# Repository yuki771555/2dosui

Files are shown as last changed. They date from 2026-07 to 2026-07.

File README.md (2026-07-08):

# 2dosumi

Raspberry Pi + HX711 + load cells project for detecting return-to-bed events.

## Local mock run

```powershell
python -m twodosumi run --config config/mock.fast.json --max-samples 25
```

## Web UI and webhook notifications

Install dependencies on the Raspberry Pi, then start the Web UI:

```bash
python3 -m pip install -r requirements-pi.txt
python3 -m twodosumi web --config config/pi.aggregate.json --secrets config/secrets.json --host 127.0.0.1 --port 8080
```

On first launch, `config/secrets.json` is created with a `web_ui_token`.
Open the UI through Tailscale Serve:

```bash
tailscale serve --bg 8080
```

The Web UI can edit thresholds and timing settings, start/stop detection, check sensor reads, run zero and scale calibration, and test webhook delivery. Use a Discord webhook URL with `webhook_payload_format=discord`, or set the format to `json` for a generic webhook endpoint.

The second-sleep alarm can be turned on or off from the Web UI. When `alarm_enabled` is on, `second_sleep_detected` sends a Discord webhook using `config/secrets.json` and pulses the Raspberry Pi buzzer. The default buzzer pin is `board.D13`; use an active buzzer or a suitable transistor/driver circuit for your buzzer module.

To start the Web UI automatically when the Pi boots:

```bash
chmod +x scripts/install_twodosumi_web_service.sh
./scripts/install_twodosumi_web_service.sh
tailscale serve --bg 8080
```

The installer defaults to `APP_DIR=/home/pi/2dosumi`, `APP_USER=pi`, and port `8080`. Override them if needed:

```bash
APP_DIR=/home/pi/2dosumi APP_USER=pi PORT=8080 ./scripts/install_twodosumi_web_service.sh
```

Useful checks:

```bash
systemctl status twodosumi-web.service --no-pager
journalctl -u twodosumi-web.service -f
tailscale serve status
```

## Raspberry Pi setup

For the full deployment flow, including copying files to the Pi, first sensor verification, calibration, and systemd setup, see [docs/raspberry_pi_deploy.md](docs/raspberry_pi_deploy.md).

```bash
python3 -m pip install -r requirements-pi.txt
python3 -m twodosumi check-sensor --config config/pi.aggregate.json --samples 10
python3 -m twodosumi calibrate-zero --config config/pi.aggregate.json
python3 -m twodosumi calibrate-scale --config config/pi.aggregate.json --known-kg 8
python3 -m twodosumi run --config config/pi.aggregate.json --secrets config/secrets.json
```

The current Pi config uses HX711 DATA on `board.D6` and SCK on `board.D5`.

## Android native app

The native Android client lives in `android/`. It uses Kotlin + Jetpack Compose
and talks to the existing Raspberry Pi Flask API; the sensor and detector still
run on the Pi.

Open `android/` in Android Studio, sync Gradle, then run the `app`
configuration. On first launch, enter the Pi Web UI URL, for example
`http://raspberrypi.local:8080` or your Tailscale Serve URL, and the
`web_ui_token` from `config/secrets.json`.

If you have a local JDK and Gradle installed, you can also build from the
project root:

```powershell
cd android
.\gradlew.bat :app:assembleDebug
```

The app mirrors the Web UI:

- status polling every 3 seconds, start/stop controls, weight sparkline, and event timeline
- quick alarm toggles and scheduled alarm editing
- sensor check, zero calibration, and scale calibration
- full settings editing and webhook test

## 4 load cell wiring

This project assumes four half-bridge load cells combined into one HX711 channel.
The program reads one aggregate weight value, not four independent corner values.

| HX711 terminal | Connect to |
| --- | --- |
| `E+` | `LC1 + LC2` |
| `E-` | `LC3 + LC4` |
| `A+` | `LC1 + LC3` |
| `A-` | `LC2 + LC4` |

HX711 to Raspberry Pi:

| HX711 | Raspberry Pi 4 |
| --- | --- |
| `VCC` | Pin 1 `3.3V` |
| `GND` | Pin 6 `GND` |
| `DT` / `DOUT` | Pin 31 `GPIO6` (`board.D6`) |
| `SCK` / `CLK` | Pin 29 `GPIO5` (`board.D5`) |

Use 3.3V for HX711 VCC first. Do not feed a 5V signal into Raspberry Pi GPIO.

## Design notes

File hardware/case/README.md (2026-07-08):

# ベッド下スケールプレート(3Dプリントケース)

Raspberry Pi 4 + HX711 + 50kg半橋ロードセル×4 を内蔵する体重計型プレート。
ベッドの脚1本の下に敷き、脚にかかる荷重の変化でベッド復帰を検知する。

設計ソースは [bed_scale_plate.scad](bed_scale_plate.scad)(OpenSCAD、全寸法パラメトリック)。
STLは `stl/`、プレビュー画像は `img/` にある。

## 仕組み(荷重経路)

```
ベッドの脚
  → 脚受けリング付きの上蓋(top_plate + leg_ring)
  → 裏面のボス×4 → ロードセルのボタン×4
  → ペデスタル → 下皿(base_plate) → 床
```

上蓋はロードセルのボタン4点**だけ**に接触して浮いている。外周スカートは
横ズレ・ホコリ防止用で、下皿の壁とは上下方向に2mmの隙間があり荷重を邪魔しない。
Pi・HX711は下皿に固定され、上蓋裏面とは2.6mm以上のクリアランスがある。

## パーツと印刷

| STL | 個数 | サイズ | 備考 |
| --- | --- | --- | --- |
| `stl/base_plate.stl` | 1 | 168×168×25mm | 下皿。そのままの向きで印刷 |
| `stl/top_plate.stl` | 1 | 175.8×175.8×14mm | 上蓋。天面を下にした印刷向きでエクスポート済み |
| `stl/leg_ring.stl` | 1 | φ110×8mm | 脚受けリング(φ80までの脚に対応) |
| `stl/leg_spacer.stl` | 3 | φ110×36mm | 残り3本の脚用スペーサー(本体と同じ高さ34mm+皿2mm) |

- **Bambu A1 mini(180×180mm)で全パーツ印刷可**(最大175.8mm角)
- 材料: **PETG推奨**(PLA+でも可)。常時荷重がかかるため
- 壁 4〜6周、インフィル **40%以上**(ペデスタル部が潰れないように)
- サポート不要(全パーツその向きのまま)

## 必要部品

- 50kg 半橋ロードセル ×4(体重計タイプ、34×34mm)
- HX711 モジュール ×1
- Raspberry Pi 4 ×1
- M2.5×6mm タッピングネジ ×4(Pi固定)
- 結束バンド ×1(HX711固定)
- 瞬間接着剤 少量(脚受けリングのピン固定)

## 組立手順

1. 下皿の四隅ポケットにロードセルを置く(ボタン面を上、配線は中央向きのスロットから出す)
2. ロードセル4本の配線をHX711へ。結線はルート [README.md](../../README.md) の
   「4 load cell wiring」の表の通り(E+/E-/A+/A- の合成、HX711→Pi は GPIO5/6)
3. HX711 を中央のベイにはめ、床の貫通スロットに結束バンドを通して固定
4. Pi 4 をスタンドオフに M2.5 ネジで固定(縦置き: USB-C/HDMI辺が左壁、USB/Ethernetが奥向き)。
   USB-C 電源ケーブルは左側面スリットから外へ
5. 上蓋をかぶせる(スカートが下皿の壁の外側に重なる)
6. 脚受けリングのピン3本に接着剤を付け、上蓋天面の穴に差し込む
7. ベッドの脚1本をリングの内側に載せ、残り3本の脚にスペーサーを敷く
8. `python3 -m twodosumi calibrate-zero` → `calibrate-scale` で校正(ルートREADME参照)

## 寸法をいじりたいとき

`.scad` 先頭のパラメータを変更して再エクスポート:

- `base_outer` — プレート外形(現在168mm=A1 mini対応。大きいプリンタなら192等に拡大可)
- `ring_id` — 脚がφ80を超える場合に拡大(`ring_od`・`spacer_d` も合わせて)
- `top_underside` — Pi上空クリアランス(ヒートシンク搭載時は+数mm)
- `cell_w` / `cell_h` — ロードセルの実寸が違う場合

```powershell
$scad = "C:\Program Files\OpenSCAD\openscad.com"
& $scad -o stl\base_plate.stl -D 'part="base"'   bed_scale_plate.scad
& $scad -o stl\top_plate.stl  -D 'part="top"'    bed_scale_plate.scad
& $scad -o stl\leg_ring.stl   -D 'part="ring"'   bed_scale_plate.scad
& $scad -o stl\leg_spacer.stl -D 'part="spacer"' bed_scale_plate.scad
```

組立確認は `part="assembly"`、断面確認は `part="section"` をOpenSCADのGUIで表示。

## 注意

- 本体の全高は34mm。**必ず残り3本の脚にもスペーサー(または同厚の板)を敷いて**
  ベッドを水平に保つこと
- 定格は 50kg×4=200kg(半橋合成)。通常のシングルベッド+成人1人で問題ないが、
  片脚への集中荷重が大きい重いベッドでは脚の位置をリング中央に正しく合わせること
- 印刷品はクリープ(常時荷重での変形)があるため、検知値が徐々にドリフトしたら
  Web UI からゼロ校正をやり直す

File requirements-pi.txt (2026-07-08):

adafruit-blinka
adafruit-circuitpython-hx711
Flask

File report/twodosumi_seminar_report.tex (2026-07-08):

\documentclass[paper=a4,fontsize=10pt,ja=standard,lualatex]{jlreq}

\usepackage{luatexja}
\usepackage{luatexja-fontspec}
\usepackage[top=18mm,bottom=18mm,left=18mm,right=18mm]{geometry}
\usepackage{graphicx}
\usepackage{xcolor}
\usepackage{booktabs}
\usepackage{array}
\usepackage{longtable}
\usepackage{tabularx}
\usepackage{tikz}
\usepackage[american]{circuitikz}
\usepackage{pgfplots}
\usepackage{enumitem}
\usepackage{fancyhdr}
\usepackage[hidelinks]{hyperref}
\usepackage{lastpage}
\usetikzlibrary{arrows.meta,positioning,shapes.geometric,fit,calc}
\pgfplotsset{compat=1.18}

\definecolor{mainblue}{HTML}{1F5C99}
\definecolor{accentorange}{HTML}{E67E22}
\definecolor{softblue}{HTML}{EAF3FB}
\definecolor{softgray}{HTML}{F4F6F8}
\definecolor{darkgray}{HTML}{36454F}
\definecolor{deepgreen}{HTML}{2E7D32}
\definecolor{softgreen}{HTML}{E9F6EC}

\setmainjfont{Yu Mincho}
\setsansjfont{Yu Gothic}
\setmainfont{Latin Modern Roman}
\setsansfont{Latin Modern Sans}

\hypersetup{
  pdftitle={荷重センシングによる二度寝防止システムの開発},
  pdfauthor={○班},
  pdfsubject={電気電子工学導入ゼミナール自由研究}
}

\pagestyle{fancy}
\setlength{\headheight}{14pt}
\fancyhf{}
\lhead{\small 荷重センシングによる二度寝防止システムの開発}
\rhead{\small 電気電子工学導入ゼミナール自由研究}
\cfoot{\small \thepage}
\renewcommand{\headrulewidth}{0.3pt}

\setlength{\intextsep}{9pt plus 2pt minus 3pt}
\setlist[itemize]{leftmargin=2.0em,itemsep=0.2em,topsep=0.3em}
\setlist[enumerate]{leftmargin=2.0em,itemsep=0.2em,topsep=0.3em}
\renewcommand{\arraystretch}{1.18}

\newcommand{\ResearchTitle}{荷重センシングによる二度寝防止システムの開発}
\newcommand{\GroupNumber}{○班}
\newcommand{\StudentA}{20XXXXXX　氏名A}
\newcommand{\StudentB}{20XXXXXX　氏名B}
\newcommand{\StudentC}{20XXXXXX　氏名C}
\newcommand{\StudentD}{20XXXXXX　氏名D}
\newcommand{\SubmitDate}{2026年7月23日}
\newcommand{\AuthorNote}[1]{\hfill{\small （担当：#1）}}

\newcolumntype{Y}{>{\raggedright\arraybackslash}X}
\newcolumntype{C}[1]{>{\centering\arraybackslash}p{#1}}

\begin{document}

\thispagestyle{empty}
\begin{center}
  \vspace*{6mm}
  {\Large 電気電子工学導入ゼミナール自由研究}\\[12mm]
  {\LARGE\bfseries \ResearchTitle}\\[8mm]
  {\large \GroupNumber}\\[10mm]
\end{center}

\begin{table}[h]
\centering
\begin{tabular}{ll}
\toprule
提出日 & \SubmitDate\\
班番号 & \GroupNumber\\
\bottomrule
\end{tabular}
\end{table}

\vspace{4mm}
\begin{center}
\begin{tabular}{ll}
\toprule
学籍番号 & 氏名\\
\midrule
\StudentA\\
\StudentB\\
\StudentC\\
\StudentD\\
\bottomrule
\end{tabular}
\end{center}

\vspace{8mm}
{\large\bfseries 目次}
\begin{center}
\begin{tabularx}{0.96\linewidth}{C{9mm}Y C{28mm} C{12mm}}
\toprule
番号 & 項目 & 担当者 & ページ\\
\midrule
1 & 研究背景と目的 & 氏名A & \pageref{sec:background}\\
2 & 提案システムの概要 & 氏名B & \pageref{sec:overview}\\
3 & ハードウェア・回路・ソフトウェア構成 & 氏名B & \pageref{sec:hardware}\\
4 & 二度寝判定アルゴリズム & 氏名C & \pageref{sec:algorithm}\\
5 & 実装内容 & 氏名C & \pageref{sec:implementation}\\
6 & 模擬試験・実機確認と結果 & 氏名D & \pageref{sec:results}\\
7 & 考察 & 氏名D & \pageref{sec:discussion}\\
8 & まとめと今後の課題 & 全員 & \pageref{sec:conclusion}\\
\bottomrule
\end{tabularx}
\end{center}

\vfill
\noindent
本稿では、Raspberry Pi とロードセルを用いてベッド上の荷重変化を読み取り、起床後に再びベッドへ戻る行動を検出する二度寝防止システム「2dosumi」の開発について報告する。本研究では、二度寝を「離床後の再在床」という観測可能な状態遷移として定義し、荷重値のしきい値、監視時間、再在床の継続時間を組み合わせて判定する方式を採用した。模擬センサによる状態遷移の確認に加え、実機ではテスターによる電圧測定にもとづく不具合の切り分け、既知重量を用いたゼロ点・スケール校正、荷重変化の読み取りまでを確認した。

\vspace{2mm}
\noindent
{\small\color{darkgray} ※提出前に、班番号・学籍番号・氏名・担当者名を実情報に置き換えること。}

\clearpage

\section{研究背景と目的}
\label{sec:background}
\AuthorNote{氏名A}

朝の起床直後は、目覚ましを止めたあとに再び寝床へ戻る「二度寝」が起こりやすい。スマートフォンのアラームは音や振動によって覚醒を促すが、ユーザが一度アラームを止めてしまうと、その後に本当に起き続けているかを確認できない。そこで本研究では、寝床に戻ったという行動そのものを検出し、二度寝の直前または直後に再通知できるシステムを目標とした。

本研究の着眼点は、映像やマイクではなく荷重センサを用いることである。ベッドの脚やマットレス下にロードセルを設置すれば、利用者の在床・離床を、比較的プライバシーを保ったまま観測できる。画像認識に比べて得られる情報は少ないが、起床支援という目的に対しては「ベッド上にいるか」「離床後に戻ったか」という低次元の情報で十分である。既存の起床支援方法と本研究の位置づけを表\ref{tab:related}に整理する。

\begin{table}[h]
\centering
\caption{既存の起床支援方法と本研究の位置づけ}
\label{tab:related}
\begin{tabularx}{0.95\linewidth}{lYYY}
\toprule
方式 & 長所 & 弱点 & 本研究との関係\\
\midrule
スマートフォンアラーム & 導入が容易 & 停止後の行動を見ない & 基本通知として併用可能\\
カメラ監視 & 行動を細かく把握可能 & プライバシー負担が大きい & 本研究では採用しない\\
ウェアラブル & 身体状態を測定可能 & 装着忘れがある & 非装着型を目指す\\
荷重センシング & 在床変化を直接検出 & 設置・校正が必要 & 本研究の中心\\
\bottomrule
\end{tabularx}
\end{table}

研究目的は次の三点である。第一に、ロードセルから得られる荷重値をもとに在床状態を推定すること。第二に、離床後に一定時間以内で再び在床した場合を「二度寝リスク」として判定すること。第三に、判定結果を Web 画面や通知機構へつなげ、実用的な起床支援システムとして扱える形にすることである。

\section{提案システムの概要}
\label{sec:overview}
\AuthorNote{氏名B}

提案システムは、ベッド下の荷重センサ、Raspberry Pi 上の判定プログラム、利用者が状態を確認する Web インタフェースおよび Android ネイティブアプリから構成される。センサは寝床の荷重を周期的に読み取り、プログラムはその値をしきい値と時間条件で解釈する。二度寝が疑われる状態になると、Android アプリがスマートフォン側でアラーム音と通知を出し、必要に応じて Webhook や Raspberry Pi 側ブザーも補助通知として利用できる。システムの全体構成を図\ref{fig:system}に示す。

\begin{figure}[h]
\centering
\resizebox{0.94\linewidth}{!}{%
\begin{tikzpicture}[
  font=\small,
  block/.style={draw=mainblue!70,line width=0.8pt,rounded corners=2pt,fill=softblue,minimum width=32mm,minimum height=11mm,align=center},
  smallblock/.style={draw=darkgray!45,line width=0.6pt,rounded corners=2pt,fill=softgray,minimum width=30mm,minimum height=10mm,align=center},
  arrow/.style={-{Latex[length=2.4mm]},thick,darkgray},
  lbl/.style={font=\scriptsize,darkgray,fill=white,inner sep=1.5pt}
]
\node[block] (bed) {ベッド\\ロードセル};
\node[smallblock,right=15mm of bed] (hx) {HX711\\増幅・A/D変換};
\node[block,right=15mm of hx] (pi) {Raspberry Pi\\判定・API};
\node[smallblock,above right=7mm and 17mm of pi] (web) {Web UI\\状態確認・設定};
\node[smallblock,right=17mm of pi] (android) {Androidアプリ\\操作・鳴動};
\node[smallblock,below right=7mm and 17mm of pi] (log) {CSVログ\\事後検証};
\node[block,right=10mm of android] (notify) {スマホアラーム\\通知};
\draw[arrow] (bed) -- node[lbl,above]{微小電圧} (hx);
\draw[arrow] (hx) -- node[lbl,above]{デジタル値} (pi);
\draw[arrow] (pi) -- (web);
\draw[arrow] (pi) -- node[lbl,above]{HTTP API} (android);
\draw[arrow] (pi) -- (log);
\draw[arrow] (android) -- (notify);
\end{tikzpicture}
}
\caption{提案システムの全体構成}
\label{fig:system}
\end{figure}

本システムが扱う状態は、主に「在床」「離床後監視」「再在床」「二度寝検出」であり、監視時間内に戻らなければ「起床成功」となる。重要なのは、単にベッドにいるかどうかではなく、起床予定時刻付近で一度離床した後に戻るという時間的な流れを扱う点である。このため、瞬間的なしきい値判定だけではなく、離床から再在床までの経過時間も判定に用いる。

Android ネイティブアプリは、Raspberry Pi 側の HTTP API に接続する日常利用の窓口として位置づけた。Web ブラウザでも状態確認は可能だが、利用者が自分から開く必要があるため、二度寝しかけている利用者へ情報を届ける手段としては受動的である。ネイティブアプリであれば Foreground Service と通知を用いて画面消灯中も状態を監視し、スマートフォン本体からアラーム音を鳴らせる。

起床直後には、枕元の端末から現在状態、重量値、次回アラーム、再確認状態を少ない操作で確認できる。さらに、音量、通知の有無、アラーム設定、二度寝確定までの秒数、再確認間隔、ゼロ点校正、既知重量によるスケール校正、センサ確認などを同じ画面から変更できる。このようにアプリは将来の拡張ではなく、通知を受け取り設定を調整するというシステムの利用体験そのものを担う要素である。

実装済みのプログラムでは、設定ファイルからセンサ種別、しきい値、通知方法、Web サーバ設定などを読み込める。これにより、実機ロードセルがない環境でも模擬センサを用いて判定ロジックを検証できる。また、設定値を変更することで、ベッドや利用者の体重差に応じた調整を行える設計とした。

\section{ハードウェア・回路・ソフトウェア構成}
\label{sec:hardware}
\AuthorNote{氏名B}

ハードウェア面では、Raspberry Pi、HX711、ロードセル、スマートフォンアプリによる通知を中心に構成する。ロードセルは微小なひずみを電気信号へ変換するセンサであり、HX711 はロードセル用の高分解能 A/D 変換器として広く使われている。Raspberry Pi は HX711 から得られる値を読み取り、Python プログラムで状態判定を行う。主要な構成要素を表\ref{tab:components}にまとめる。

\begin{table}[h]
\centering
\caption{主要構成要素}
\label{tab:components}
\begin{tabularx}{0.95\linewidth}{lYY}
\toprule
分類 & 要素 & 役割\\
\midrule
センサ & ロードセル & ベッド上の荷重変化を測定する\\
変換回路 & HX711 & ロードセル信号を Raspberry Pi で扱える値に変換する\\
処理部 & Raspberry Pi & 状態判定、通知、Web UI 提供を行う\\
通知部 & Android アプリ、通知、スマホ音 & 二度寝検出時に利用者へ知らせる\\
表示部 & Web ブラウザ & 現在状態、履歴、設定値を確認する\\
モバイル部 & Android ネイティブアプリ & 状態確認、設定、校正、アラーム鳴動を行う\\
\bottomrule
\end{tabularx}
\end{table}

回路面で当初想定した標準構成は、4個のロードセルを組み合わせたホイートストンブリッジである（図\ref{fig:bridge}）。ロードセル内部のひずみゲージは、荷重を受けると抵抗値がわずかに変化する。しかし、その変化は非常に小さく、Raspberry Pi の GPIO へ直接入力しても読み取れない。そこで、4個のロードセルをブリッジの4辺として構成し、左右の中点間に現れる差動電圧を HX711 で増幅・A/D 変換する。ブリッジ構成には、抵抗変化を差動電圧として取り出すことで感度を高められるうえ、温度変化のように4個の抵抗へ同じ向きに現れる変動を打ち消せるという利点がある。

\begin{figure}[h]
\centering
\resizebox{0.82\linewidth}{!}{%
\begin{circuitikz}[
  american resistors,
  circuitikz/bipoles/length=12mm,
  every node/.style={font=\small},
  wire/.style={thick},
  sig/.style={{Latex[length=2.0mm]}-{Latex[length=2.0mm]},dashed,thick,mainblue},
  data/.style={-{Latex[length=2.0mm]},thick},
  port/.style={font=\scriptsize,inner sep=1pt}
]
\coordinate (ep) at (0,2.6);
\coordinate (em) at (0,-2.6);
\coordinate (ap) at (-3.1,0);
\coordinate (am) at (3.1,0);
\draw[wire] (ep) to[R,l_={LC1}] (ap)
            to[R,l_={LC3}] (em)
            to[R,l_={LC4}] (am)
            to[R,l_={LC2}] (ep);
\fill (ep) circle (1.4pt);
\fill (em) circle (1.4pt);
\fill (ap) circle (1.4pt);
\fill (am) circle (1.4pt);
\node[above left=1mm and -2mm of ep] {E+（励起+）};
\node[left=3mm of em] {E-（励起-）};
\node[left=2mm of ap] {A+};
\node[below=2mm of am] {A-};
\draw[sig] ($(ap)+(0.45,0)$) -- node[above,fill=white,inner sep=1.5pt]{差動電圧} ($(am)+(-0.45,0)$);
\node[draw,rounded corners,fill=softblue,minimum width=30mm,minimum height=30mm,align=center] (hx) at (6.7,0) {HX711\\増幅（PGA）\\A/D変換};
% 励起（E+ / E-）：HX711基板からブリッジへ電源を供給
\draw[wire] (ep) -- node[above,font=\scriptsize]{励起電圧の供給} (5.0,2.6) -- (5.0,1.15) -- (hx.west |- 0,1.15);
\draw[wire] (em) -- (0,-3.3) -- (4.6,-3.3) -- (4.6,-0.45) -- (hx.west |- 0,-0.45);
% 差動入力（A+ / A-）：ブリッジ中点の電圧をHX711へ入力
\draw[wire] (am) -- (4.6,0) -- (4.6,0.45) -- (hx.west |- 0,0.45);
\draw[wire] (ap) -- (-3.1,-3.9) -- (5.0,-3.9) -- (5.0,-1.15) -- (hx.west |- 0,-1.15);
\node[port,anchor=west] at ($(hx.west)+(0.06,1.15)$) {E+};
\node[port,anchor=west] at ($(hx.west)+(0.06,0.45)$) {A-};
\node[port,anchor=west] at ($(hx.west)+(0.06,-0.45)$) {E-};
\node[port,anchor=west] at ($(hx.west)+(0.06,-1.15)$) {A+};
\node[draw,rounded corners,fill=softgray,minimum width=30mm,minimum height=17mm,align=center,right=13mm of hx] (pi) {Raspberry Pi\\GPIO};
\draw[data] (hx.east |- 0,0.4) -- node[above]{DOUT} (pi.west |- 0,0.4);
\draw[data] (pi.west |- 0,-0.4) -- node[below]{SCK} (hx.east |- 0,-0.4);
\end{circuitikz}%
}
\caption{4個のロードセル（LC1〜LC4）で構成したホイートストンブリッジと HX711・Raspberry Pi の接続}
\label{fig:bridge}
\end{figure}

実機検証では当初4個構成で組み、初期の読み取り不良は HX711 読み取り処理の実装ミスを修正することで解消し、4個構成でもサンプル取得できることを確認した。その後、別日にロードセル1個のセンサ線を断線してしまったため、最終的な実機検証では故障したロードセルを外し、2個の半橋ロードセルで1つのブリッジを構成する方式へ変更した。これは初期の読み取り不良とは別の事象であり、測定方式を単に簡略化したのではなく、実験を継続するための故障対応である。本研究の目的は体重を高精度に量ることではなく、在床、離床、再在床の大きな荷重変化を判定することであるため、2個構成でも判定ロジックの検証には十分であると判断した。実機検証で用いた2個ロードセル版の接続を図\ref{fig:two-cell-bridge}と表\ref{tab:two-cell-wiring}に示す。

\begin{figure}[h]
\centering
\resizebox{0.86\linewidth}{!}{%
\begin{circuitikz}[
  american resistors,
  circuitikz/bipoles/length=12mm,
  every node/.style={font=\small},
  wire/.style={thick},
  sig/.style={{Latex[length=2.0mm]}-{Latex[length=2.0mm]},dashed,thick,mainblue},
  data/.style={-{Latex[length=2.0mm]},thick},
  port/.style={font=\scriptsize,inner sep=1pt}
]
\coordinate (lTop) at (-2.4,2.4);
\coordinate (lMid) at (-2.4,0);
\coordinate (lBot) at (-2.4,-2.4);
\coordinate (rTop) at (2.4,2.4);
\coordinate (rMid) at (2.4,0);
\coordinate (rBot) at (2.4,-2.4);
\draw[wire] (lTop) to[R,l={LC1上側}] (lMid)
            to[R,l={LC1下側}] (lBot);
\draw[wire] (rTop) to[R,l_={LC2上側}] (rMid)
            to[R,l_={LC2下側}] (rBot);
\draw[wire] (lTop) -- node[above,font=\scriptsize]{E+ 共通} (rTop);
\draw[wire] (lBot) -- node[below,font=\scriptsize]{E- 共通} (rBot);
\fill (lTop) circle (1.4pt);
\fill (lMid) circle (1.4pt);
\fill (lBot) circle (1.4pt);
\fill (rTop) circle (1.4pt);
\fill (rMid) circle (1.4pt);
\fill (rBot) circle (1.4pt);
\node[left=2mm of lMid] {A+};
\node[right=2mm of rMid] {A-};
\draw[sig] ($(lMid)+(0.35,0)$) -- node[above,fill=white,inner sep=1.5pt]{差動電圧} ($(rMid)+(-0.35,0)$);
\node[draw,rounded corners,fill=softblue,minimum width=30mm,minimum height=30mm,align=center] (hx) at (6.5,0) {HX711\\Aチャネル\\増幅・A/D};
\draw[wire] (rTop) -- (4.7,2.4) -- (4.7,1.15) -- (hx.west |- 0,1.15);
\draw[wire] (rBot) -- (4.3,-2.4) -- (4.3,-0.45) -- (hx.west |- 0,-0.45);
\draw[wire] (rMid) -- (4.3,0) -- (4.3,0.45) -- (hx.west |- 0,0.45);
\draw[wire] (lMid) -- (-1.0,0) -- (-1.0,-3.1) -- (4.7,-3.1) -- (4.7,-1.15) -- (hx.west |- 0,-1.15);
\node[port,anchor=west] at ($(hx.west)+(0.06,1.15)$) {E+};
\node[port,anchor=west] at ($(hx.west)+(0.06,0.45)$) {A-};
\node[port,anchor=west] at ($(hx.west)+(0.06,-0.45)$) {E-};
\node[port,anchor=west] at ($(hx.west)+(0.06,-1.15)$) {A+};
\node[draw,rounded corners,fill=softgray,minimum width=30mm,minimum height=17mm,align=center,right=13mm of hx] (pi) {Raspberry Pi\\GPIO};
\draw[data] (hx.east |- 0,0.4) -- node[above]{DOUT} (pi.west |- 0,0.4);
\draw[data] (pi.west |- 0,-0.4) -- node[below]{SCK} (hx.east |- 0,-0.4);
\end{circuitikz}%
}
\caption{実機検証で用いた2個の半橋ロードセルによるブリッジ構成}
\label{fig:two-cell-bridge}
\end{figure}

\begin{table}[h]
\centering
\caption{2個ロードセル構成での端子接続}
\label{tab:two-cell-wiring}
\begin{tabularx}{0.95\linewidth}{lY}
\toprule
端子 & 接続先\\
\midrule
E+ & 2個のロードセルの上側外端を共通接続\\
E- & 2個のロードセルの下側外端を共通接続\\
A+ & 1個目ロードセルの中点\\
A- & 2個目ロードセルの中点\\
VCC & Raspberry Pi の 3.3 V\\
GND & Raspberry Pi の GND\\
DT / DOUT & Raspberry Pi の GPIO6（D6）\\
SCK / CLK & Raspberry Pi の GPIO5（D5）\\
\bottomrule
\end{tabularx}
\end{table}

2個のロードセルは向きや荷重のかかり方により、A+ と A- の符号が期待と逆になる場合がある。その場合でも故障とは限らず、既知重量を用いた校正でスケール係数の符号が決まり、ソフトウェア上では kg 相当値として扱える。本研究の実機でも、既知重量による校正後に荷重を kg 相当値として読み取れることを確認した（第\ref{sec:results}節）。

HX711 基板では、ロードセル側の端子は一般に E+、E-、A+、A- と表記される。E+ と E- は HX711 基板側からブリッジへ電圧を供給する励起端子であり、A+ と A- はブリッジの左右の中点から差動電圧を受け取る入力端子である。荷重がないときは左右の分圧がほぼ等しく、A+ と A- の電位差はほぼ 0 V になる。荷重がかかると一部のゲージが伸び、別のゲージが縮むため、片側の抵抗はわずかに増え、反対側はわずかに減る。励起電圧を $V_E$、無荷重時の各辺の抵抗を $R$、荷重による変化分を $\Delta R$ とし、対角の2辺が $+\Delta R$、残りの2辺が $-\Delta R$ と逆向きに変化する理想的な場合を考えると、左右の分圧の差として現れる出力電圧は
\[
  V_{\mathrm{A+}} - V_{\mathrm{A-}} = \frac{\Delta R}{R}\, V_E
\]
となり、抵抗の変化率に比例した電圧が得られる。実際の $\Delta R / R$ はごく小さく、この差動電圧は数 mV 程度と微小であるため、HX711 は内部のプログラマブルゲインアンプ（チャネル A では 128 倍）で増幅したうえで、24 ビットの A/D 変換器によりデジタル値へ変換し、DOUT・SCK の2線シリアルで Raspberry Pi へ送る（表\ref{tab:hx711}）。

\begin{table}[h]
\centering
\caption{HX711 と Raspberry Pi の接続例}
\label{tab:hx711}
\begin{tabularx}{0.95\linewidth}{lYY}
\toprule
端子 & 接続先 & 役割\\
\midrule
E+ / E- & ロードセルブリッジの電源端 & ブリッジ回路へ励起電圧を与える\\
A+ / A- & ブリッジの左右中点 & 荷重で変化する差動電圧を入力する\\
VCC / GND & Raspberry Pi の 3.3 V / GND & HX711 基板へ電源を供給する\\
DT / DOUT & Raspberry Pi の GPIO6（D6） & 変換完了とデータ出力を受け取る\\
SCK / CLK & Raspberry Pi の GPIO5（D5） & クロックを送り、データ読み出しとゲイン設定を行う\\
\bottomrule
\end{tabularx}
\end{table}

Raspberry Pi で使う場合は、GPIO が 3.3 V 入力である点に注意する。HX711 モジュールには 5 V 動作品も多く、DT 端子の High レベルが 5 V のままでは GPIO を傷めるおそれがあるため、本研究では HX711 を 3.3 V で駆動した。また、センサ配線は微小電圧を扱うため、長い配線や電源ノイズ、断線の影響を受けやすい。実機では、ロードセルの固定と荷重分散に注意し、ゼロ点補正と既知重量による校正で読み取り値を kg 相当へ変換する。

ソフトウェアは Raspberry Pi 側の Python プログラムと、スマートフォン側の Android ネイティブアプリに分けて構成した。Raspberry Pi 側では、センサ入力、判定器、通知、Web サーバを分離し、それぞれの責務を小さくした。これにより、実機センサから模擬センサへ切り替えても、判定器や表示側のコードを大きく変えずに試験できる。

Android アプリは Kotlin と Jetpack Compose により実装し、Retrofit/OkHttp を用いて、Raspberry Pi が公開する状態 API、設定 API、校正 API を呼び出す。センサ値を直接読まずに API 経由とすることで、ロードセルや HX711 に近い低レベル処理は Raspberry Pi に集約し、スマートフォン側は操作性と表示に集中できる。

\subsection{筐体（3Dプリントケース）の設計}

当初設計では、ロードセル4個、HX711、Raspberry Pi を一体化した体重計型の筐体を OpenSCAD で設計し、3Dプリンタ（Bambu A1 mini、造形範囲 $180\times180$ mm）で製作する構成を想定した。筐体はベッドの脚1本の下に敷き、その脚にかかる荷重の変化から在床・離床を読み取る。構成は、ロードセル・HX711・Raspberry Pi を収める下皿（168 mm 角）、その上に浮かべる上蓋（175.8 mm 角）、脚を受けるリング、および残り3本の脚の高さを揃えるスペーサー3個であり、全高は 34 mm である。設計の要点は荷重経路にある。脚の荷重は上蓋から裏面の4個のボスを介してロードセル中央の受圧ボタンのみに伝わり、下皿の支持台（ペデスタル）を経て床へ抜ける。上蓋は電子部品のどこにも接触せず（Raspberry Pi 最上部との隙間 2.6 mm）、外周のスカートは横ズレとほこりの侵入を防ぐだけで荷重を負担しない。これは市販の体重計と同じ構造であり、4個構成では各ロードセルに荷重が分配される。設計した筐体の組立状態と断面を図\ref{fig:case}に示す。

\begin{figure}[h]
\centering
\begin{minipage}[t]{0.48\linewidth}
  \centering
  
\end{minipage}\hfill
\begin{minipage}[t]{0.48\linewidth}
  \centering
  
\end{minipage}
\caption{設計した筐体の組立ビュー（左）とロードセル中心線での断面（右）。断面では上蓋がロードセルの受圧ボタン4点のみに接触し、中央の Raspberry Pi（緑・灰）と隙間を保っていることが分かる}
\label{fig:case}
\end{figure}

当初設計の耐久性は、荷重をほぼすべて「圧縮」で受ける構造とすることで確保した。3Dプリント品は曲げや積層はく離に弱い一方、押し潰す方向には強いためである。ロードセルの定格は4個構成で $50\,\mathrm{kg}\times4=200\,\mathrm{kg}$ であり、就寝時にこの脚へかかる荷重（数十 kg）に対して十分な余裕がある。曲げを受ける唯一の部品は上蓋であり、板厚 7 mm に加えて裏面に深さ 5 mm のリブを配置し、Raspberry Pi の直上のみリブを省いてクリアランスを確保した。また、樹脂は常時荷重でわずかに変形が進む（クリープ）ため、長期間の使用ではゼロ点が徐々にずれ得るが、これは Web UI からのゼロ点校正で補正できる。製作時の主な印刷条件を表\ref{tab:print}に示す。曲げ剛性が必要な上蓋のみ壁数と充填密度を高め、圧縮しか受けない部品は標準設定として印刷時間を抑えた。

\begin{table}[h]
\centering
\caption{3Dプリントの主な条件（材料は PETG、積層ピッチ 0.2 mm、サポート材なし）}
\label{tab:print}
\begin{tabularx}{0.95\linewidth}{lllY}
\toprule
部品 & 壁面層数 & 充填密度 & 補足\\
\midrule
上蓋 & 4 & 25\% & トップ面・底面各5層。唯一曲げを受けるため強化する\\
下皿 & 3 & 15\% & 床に全面接地するため曲げがかからない\\
スペーサー（3個） & 2 & 10〜15\% & 圧縮のみ。本体と同高にしてベッドを水平に保つ\\
脚受けリング & 2 & 15\% & 脚の横ズレ防止用\\
\bottomrule
\end{tabularx}
\end{table}

当初設計の組立では、ロードセルは下皿四隅のポケットにはめ込むだけで位置が決まり、上蓋のボスが上から押さえる。HX711 は中央のベイに収め、床の貫通スロットに通した結束バンドで固定する。Raspberry Pi は下皿のスタンドオフ4本（Pi 4 の取付穴ピッチ $58\times49$ mm に対応、下穴 $\phi2.2$ mm）に M2.5$\times$6 mm の小ネジをセルフタップでねじ込んで固定し、USB-C 電源ケーブルは側壁のスリットから外へ引き出す。設置面が沈むと支持台が傾き測定が不安定になるため、カーペット上への直置きは避け、フローリングか板の上に設置する。

\section{二度寝判定アルゴリズム}
\label{sec:algorithm}
\AuthorNote{氏名C}

判定アルゴリズムは状態遷移として設計した。センサ値には揺らぎがあるため、単一のしきい値で在床・離床を切り替えると、境界付近で判定が細かく振動してしまう。そこで本システムでは、荷重値を設定した利用者体重に対する比率へ換算したうえで、離床の判定（体重比 0.3 未満）と再在床の判定（体重比 0.4 超）に異なるしきい値を用いるヒステリシスを持たせた。さらに、離床後の監視時間と、再在床の継続を確かめる確認時間を組み合わせることで、瞬間的な変動だけで二度寝と決めない設計とした。状態遷移の全体を図\ref{fig:fsm}に、判定に用いる主なパラメータを表\ref{tab:params}に示す。

\begin{figure}[h]
\centering
\begin{tikzpicture}[
  font=\small,
  state/.style={draw=mainblue!70,line width=0.8pt,rounded corners=3pt,fill=softblue,minimum width=31mm,minimum height=11mm,align=center},
  goal/.style={draw=deepgreen!70,line width=0.8pt,rounded corners=3pt,fill=softgreen,minimum width=31mm,minimum height=11mm,align=center},
  alert/.style={draw=accentorange!80,line width=0.8pt,rounded corners=3pt,fill=accentorange!18,minimum width=31mm,minimum height=11mm,align=center},
  lab/.style={font=\scriptsize,align=center,darkgray},
  arrow/.style={-{Latex[length=2.2mm]},thick,darkgray}
]
\node[state] (sleep) {SLEEPING\\在床};
\node[state,right=27mm of sleep] (awake) {AWAKE\_WINDOW\\離床後監視};
\node[goal,right=27mm of awake] (done) {DONE\\起床成功};
\node[state,below=16mm of awake] (returned) {RETURNED\\再在床};
\node[alert,below=16mm of sleep] (second) {SECOND\_SLEEP\\二度寝検出};
\node[lab,left=8mm of sleep] (start) {開始};
\draw[arrow] (start) -- (sleep);
\draw[arrow] (sleep) -- node[lab,above]{離床\\（体重比 $<0.3$）} (awake);
\draw[arrow] (awake) -- node[lab,above]{監視時間\\（30分）経過} (done);
\draw[arrow] ([xshift=-5mm]awake.south) -- node[lab,left]{再在床\\（体重比 $>0.4$）} ([xshift=-5mm]returned.north);
\draw[arrow] ([xshift=5mm]returned.north) -- node[lab,right]{荷重再低下} ([xshift=5mm]awake.south);
\draw[arrow] (returned) -- node[lab,above]{確認時間\\（3分）継続} (second);
\end{tikzpicture}
\caption{二度寝判定の状態遷移（緑：正常終了、橙：二度寝検出。しきい値と時間は表\ref{tab:params}の既定値）}
\label{fig:fsm}
\end{figure}

\begin{table}[h]
\centering
\caption{判定に用いる主なパラメータ（既定値。設定ファイルで変更できる）}
\label{tab:params}
\begin{tabularx}{0.95\linewidth}{llY}
\toprule
パラメータ & 既定値 & 意味\\
\midrule
離床判定比 & 0.3 & 体重比がこの値を下回ると離床とみなす\\
再在床判定比 & 0.4 & 離床後、体重比がこの値を超えると再在床とみなす\\
監視時間 & 30分 & 離床後に再在床を見張る時間\\
確認時間 & 3分 & 再在床がこの時間続くと二度寝と確定する\\
中央値フィルタ & 9点 & 複数サンプルの中央値で1回分の読み値を決める\\
移動平均 & 5点 & 判定前に読み値の列を平滑化する\\
\bottomrule
\end{tabularx}
\end{table}

この方式の利点は、判定理由を説明しやすいことである。機械学習モデルを用いる場合、多様なデータを集めれば複雑な行動を分類できる一方、少数データでは過学習や説明困難性が問題になる。本研究段階では、まず比率のしきい値と時間条件による確実な基礎機能を作り、将来的にデータが蓄積した段階で学習型の判定へ拡張する方針とした。

処理の流れをまとめると、次のようになる。

\begin{enumerate}
  \item センサ値を一定周期で取得し、中央値フィルタと移動平均で平滑化する。
  \item 平滑化した値の体重比が離床判定比を下回ったら、離床時刻を記録して監視を始める。
  \item 監視時間内に体重比が再在床判定比を超えたら、再在床状態へ移る。監視時間を過ぎれば、起床成功として監視を終える。
  \item 再在床が確認時間続けば、二度寝検出として通知する。途中で荷重が再び下がった場合は監視状態へ戻る。
\end{enumerate}

\section{実装内容}
\label{sec:implementation}
\AuthorNote{氏名C}

実装では、コマンドライン実行、Web サーバ、設定ファイル、ログ出力、Android アプリ、テストを用意した。コマンドラインからは通常実行と模擬実行を切り替えられる。Web サーバは現在の状態やイベント履歴を返す API を持ち、簡易画面から状態確認と設定変更ができる。ログは時刻、荷重値、状態、イベントを残すため、後から判定が妥当だったかを確認できる。Raspberry Pi 側のモジュール分割と依存関係を図\ref{fig:software}に、実装した主な機能を表\ref{tab:features}に示す。

\begin{figure}[h]
\centering
\begin{tikzpicture}[
  font=\small,
  module/.style={draw=mainblue!70,line width=0.7pt,rounded corners=2pt,fill=softblue,minimum width=31mm,minimum height=9mm,align=center},
  ext/.style={draw=accentorange!80,line width=0.7pt,rounded corners=2pt,fill=accentorange!12,minimum width=31mm,minimum height=9mm,align=center},
  data/.style={draw=darkgray!45,line width=0.6pt,rounded corners=2pt,fill=softgray,minimum width=26mm,minimum height=8mm,align=center},
  arrow/.style={-{Latex[length=2.2mm]},thick,darkgray},
  lbl/.style={font=\scriptsize,darkgray}
]
\node[module] (sensor) {sensors.py\\荷重取得};
\node[module,above=7mm of sensor] (config) {config.py\\設定読込};
\node[module,right=16mm of sensor] (detector) {detector.py\\状態判定};
\node[module,right=16mm of detector] (notify) {alarm.py\\通知イベント};
\node[data,above=7mm of detector] (log) {CSVログ};
\node[module,below=8mm of detector] (web) {web.py\\Web API};
\node[ext,below=8mm of notify] (android) {Androidアプリ\\スマホ鳴動};
\draw[arrow] (config) -- (sensor);
\draw[arrow] (config) -- (detector);
\draw[arrow] (sensor) -- (detector);
\draw[arrow] (detector) -- (notify);
\draw[arrow] (detector) -- (web);
\draw[arrow] (detector) -- (log);
\draw[arrow] (web) -- node[lbl,below]{HTTP} (android);
\end{tikzpicture}
\caption{ソフトウェアのモジュール分割（青：Raspberry Pi 側の Python モジュール、橙：スマートフォン側、灰：データ）}
\label{fig:software}
\end{figure}

\begin{table}[h]
\centering
\caption{実装した主な機能}
\label{tab:features}
\begin{tabularx}{0.95\linewidth}{lY}
\toprule
機能 & 内容\\
\midrule
設定読込 & JSON 設定から判定比、監視・確認時間、通知方法を指定する\\
センサ抽象化 & 実機 HX711 と模擬センサを切り替えられる\\
平滑化 & 中央値フィルタと移動平均で読み値のノイズを抑える\\
状態判定 & 離床、再在床、二度寝検出を状態遷移で処理する\\
通知 & Android アプリのスマホ音、通知、Webhook、補助ブザーに対応する\\
定時アラーム & 指定時刻に鳴動し、離床の継続を確認する起床ミッションを持つ\\
Web UI & ブラウザから状態、ログ、設定を確認できる\\
Android アプリ & Kotlin/Jetpack Compose で状態確認、スマホアラーム、音量調整、校正操作を行う\\
単体テスト & 設定、センサ、判定、Web API の基本動作を確認する\\
\bottomrule
\end{tabularx}
\end{table}

模擬センサを用意した理由は、実機環境がなくても判定器の振る舞いを再現できるようにするためである。開発初期に実機だけへ依存すると、配線ミスやセンサ固定方法の問題と、ソフトウェアのバグが混ざってしまう。模擬入力で「期待する状態遷移が起こる」ことを先に確認しておくことで、実機試験時の切り分けが容易になる。

また、Web UI と Android アプリを持たせたことで、実験中にターミナルを見続けなくても現在状態を確認できる。Web UI は PC からの確認や発表デモに向き、Android アプリは起床直後に手元で操作する場面に向く。特に、スマートフォン側でアラーム一覧、センサ校正、音量、通知、二度寝確定秒数、再確認間隔を変更できるため、利用者が日常的に設定を変える運用を想定できる。アプリは Foreground Service で Raspberry Pi の状態 API を監視し、時刻アラーム、再アラーム、再入床、二度寝検出のイベントを受けてスマートフォン本体から音を鳴らす。これにより、Raspberry Pi にブザーを接続しなくても、枕元のスマートフォンを通知装置として利用できる。

\section{模擬試験・実機確認と結果}
\label{sec:results}
\AuthorNote{氏名D}

本節では、ソフトウェア上の判定ロジック、実機回路の電気的状態、校正後の荷重読み取りの三段階で確認した結果を述べる。模擬試験では、実機の配線状態に依存せず、状態遷移そのものが設計どおりに動くかを検証した。実機確認では、HX711 まわりの電源・励起・差動入力を測定し、読み取り不良の原因を配線とソフトウェアに分けて切り分けた。最後に、2個ロードセル構成で校正を行い、在床・離床判定に必要な荷重差を読み取れるか確認した。結果の要約を表\ref{tab:result-summary}に示す。

\begin{table}[h]
\centering
\caption{確認結果の要約}
\label{tab:result-summary}
\begin{tabularx}{0.95\linewidth}{lYY}
\toprule
確認項目 & 方法 & 結果\\
\midrule
状態遷移 & 体重 60 kg 相当の模擬入力18サンプルを与える & left\_bed、returned、second\_sleep\_detected が順に1回ずつ発生\\
実機切り分け & VCC、励起電圧、A+--A-、導通、DOUT の挙動を測定 & 電源・ブリッジ応答は確認でき、初期不具合は HX711 読み取り処理の実装ミスと判断\\
4個構成の確認 & 読み取り処理修正後にサンプル取得を実施 & 4個ロードセル構成でも変換完了とサンプル取得を確認\\
最終構成の校正 & 後日の断線対応として2個構成へ組み替え、ゼロ点・スケール校正を実施 & 既知荷重を1\%未満の誤差で読み取り、空床と在床相当の値が明確に分離\\
ソフトウェア試験 & 設定、センサ、判定、Web API の単体テストを実行 & 24件のテストが通過\\
\bottomrule
\end{tabularx}
\end{table}

\subsection{模擬センサによる状態遷移の確認}

模擬試験では、体重 60 kg の利用者を想定し、在床状態から一度離床し、その後ベッドへ戻る入力列を与えた。確認した実行では、18 サンプルの範囲で「在床」「離床後監視」「再在床」「二度寝検出」の順に状態が遷移した。これにより、少なくとも設計した状態遷移がソフトウェア上で動作することを確認できた。与えた模擬入力を図\ref{fig:sim}に、確認したイベントを表\ref{tab:events}に示す。図中の2本の破線は、離床判定（体重比 0.3、荷重値 18 相当）と再在床判定（体重比 0.4、荷重値 24 相当）のしきい値であり、両者をずらしたヒステリシスによって境界付近の揺らぎで判定が振動しないようにしている。

\begin{figure}[h]
\centering
\begin{tikzpicture}
\begin{axis}[
  width=0.92\linewidth,
  height=56mm,
  xlabel={サンプル番号},
  ylabel={荷重値（kg 相当・模擬）},
  xmin=1,xmax=18,
  ymin=0,ymax=78,
  xtick={1,3,5,7,9,11,13,15,17},
  ytick={0,20,40,60},
  axis line style={darkgray!70},
  every tick/.append style={darkgray!70},
  tick label style={font=\small},
  label style={font=\small},
  grid=both,
  grid style={line width=.1pt, draw=gray!25},
  major grid style={line width=.2pt,draw=gray!40},
  legend pos=south east,
  legend cell align=left,
  legend style={font=\small,fill=white,fill opacity=0.9,text opacity=1,draw=darkgray!40}
]
\fill[softblue,opacity=0.6] (axis cs:1,0) rectangle (axis cs:4.5,78);
\fill[softgray,opacity=0.8] (axis cs:4.5,0) rectangle (axis cs:8.5,78);
\fill[accentorange,opacity=0.10] (axis cs:8.5,0) rectangle (axis cs:18,78);
\node[font=\scriptsize,darkgray] at (axis cs:2.7,73) {在床};
\node[font=\scriptsize,darkgray] at (axis cs:6.5,73) {離床};
\node[font=\scriptsize,darkgray] at (axis cs:13.2,73) {再在床};
\addplot[color=mainblue,line width=1pt,mark=*,mark size=1.5pt] coordinates {
  (1,59) (2,61) (3,60) (4,58)
  (5,12) (6,10) (7,11) (8,13)
  (9,57) (10,59) (11,58) (12,60)
  (13,61) (14,60) (15,62) (16,61) (17,60) (18,59)
};
\addlegendentry{模擬荷重}
\addplot[color=accentorange,dashed,thick] coordinates {(1,24) (18,24)};
\addlegendentry{再在床判定（体重比0.4）}
\addplot[color=darkgray,dashed,thick] coordinates {(1,18) (18,18)};
\addlegendentry{離床判定（体重比0.3）}
\end{axis}
\end{tikzpicture}
\caption{模擬入力における荷重変化と判定しきい値}
\label{fig:sim}
\end{figure}

\begin{table}[h]
\centering
\caption{模擬試験で確認したイベント}
\label{tab:events}
\begin{tabularx}{0.95\linewidth}{lYY}
\toprule
段階 & 状態 & 確認内容\\
\midrule
初期 & SLEEPING & 体重比が十分大きく在床と判定した\\
離床 & AWAKE\_WINDOW & 荷重低下により離床後の監視へ移った\\
復帰 & RETURNED & 監視時間内に荷重が戻ったことを検出した\\
検出 & SECOND\_SLEEP & 再在床が継続し二度寝イベントを発生させた\\
\bottomrule
\end{tabularx}
\end{table}

模擬試験の実行ログは CSV 形式で保存され、各行に時刻、センサ生値、kg 換算値、平滑化後の値、状態、イベントが記録される。ログ上でも left\_bed（離床）、returned（再在床）、second\_sleep\_detected（二度寝検出）の各イベントがこの順で1回ずつ出力されており、平滑化後の値がしきい値を横切ったサンプルで状態が切り替わることを行単位で追跡できた。この試験は繰り返し実行しても同じイベント列が得られ、判定器の動作は再現的であった。したがって、実機の測定誤差を含まない条件では、設計した状態遷移とイベント出力が意図どおり機能することを確認できた。

\subsection{実機の電気的測定と不具合の切り分け}

実機は Raspberry Pi、HX711、ロードセルで構成し、まず当初設計どおりの4個構成で組み立てた。最初の動作確認では、HX711 の DOUT が変換完了（Low）にならずタイムアウトする状態と、読み値が 24 ビット A/D の端点値（$\pm 8388607$）に張り付く状態が発生し、ソフトウェアからは有効な荷重値を得られなかった。端点値への張り付きは配線系の異常でも起こり得るため、当初は入力の開放や断線を疑った。そこでテスターを用い、電源側から信号側へ向かって順に電圧と導通を実測して切り分けを行った。測定箇所と結果を表\ref{tab:probe}に示す。

\begin{table}[h]
\centering
\caption{実機での電気的測定とソフトウェア不具合の切り分け}
\label{tab:probe}
\begin{tabularx}{0.95\linewidth}{lYYY}
\toprule
測定箇所 & 期待される値 & 実測値 & 判断\\
\midrule
HX711 の VCC-GND 間 & 3.3 V & 3.3 V & 電源供給は正常\\
E+ - E- 間（励起電圧） & 電源電圧以下の一定値 & 約 2.68 V & ブリッジへの励起は正常\\
A+ - A- 間（無荷重時） & ほぼ 0 mV & ほぼ 0 mV & ブリッジの平衡は正常\\
A+ - A- 間（荷重印加時） & 数 mV 以下の微小変化 & わずかな変化を確認 & ブリッジ応答は存在\\
センサ線の導通 & 全線で導通あり & おおむね導通あり & 初期不具合の主因ではない\\
HX711 読み取り処理 & 有効サンプルを取得 & 端点値・タイムアウトが発生 & 実装ミスを修正\\
\bottomrule
\end{tabularx}
\end{table}

この測定では、電源、励起、ブリッジの応答、センサ線の導通に大きな異常は確認できず、初期不具合の主因はセンサ線の断線ではなく、HX711 の読み取り処理におけるソフトウェア実装ミスであると判断した。該当箇所を修正した後は、4個ロードセル構成でも DOUT が周期的に変換完了を示し、サンプル取得が成功した。

ただし、後日別の作業中にロードセル1個のセンサ線を断線してしまったため、最終的な検証では故障したロードセルを外し、2個の半橋ロードセルによるブリッジ構成（図\ref{fig:two-cell-bridge}）へ組み替えた。したがって、初期不具合の原因であったソフトウェア実装ミスと、2個構成へ変更した理由である後日の断線は、別の事象である。

実測値の妥当性は、ロードセルの定格からも確認できる。使用したロードセルの定格出力を約 1 mV/V と仮定すると、実測した励起電圧 2.68 V では定格荷重時でも差動電圧は約 2.7 mV にとどまり、数十 kg の荷重では 1 mV 前後となる。これは「無荷重時はほぼ 0 mV、荷重印加でわずかに変化する」という実測結果と整合しており、HX711 が内蔵アンプで 128 倍に増幅してから A/D 変換する必要性を、実測からも裏付けられた。

\subsection{校正と荷重読み取りの確認}

組み替え後の2個構成で、ゼロ点校正とスケール校正を実施した。ゼロ点校正では、寝具を載せた空床状態で読み値を繰り返し取得し、その中央値をゼロ点とした。起動直後は値が安定しないため、ウォームアップとして最初の5サンプルを捨て、その後の読み値へ9点の中央値フィルタを適用している。スケール校正では、既知重量の荷重を載せた状態で生値を取得し、スケール係数を（荷重時の生値 $-$ ゼロ点）$\div$ 既知重量として算出した。

校正後に同じ既知荷重を載せ直して読み値を確認したところ、kg 相当値の誤差は約 0.8\%（1\%未満）であり、在床・離床判定には十分な精度で変換できることを確認した。また、在床相当の荷重を加えた状態と空床状態を繰り返して読み値を比較すると、両者は明確に分離しており、離床判定比 0.3・再在床判定比 0.4 のしきい値（体重比換算）に対して十分な余裕があった。

この結果から、2個ロードセル構成でも、在床と離床を区別するために必要な大きな荷重変化は取得できることを確認した。ただし、体重計としての絶対精度、寝返りや荷物による誤判定率、利用者ごとのしきい値最適化は継続検証が必要である。単体テストとしては設定読込、センサ処理、Web API などの基本動作を確認し、現時点では 24 件のテストが通過している。そのため、本結果は「判定ロジック、ソフトウェア構成、実機読み取りの成立性」を示すものであり、最終的な実用性能を示すものではない。

\section{考察}
\label{sec:discussion}
\AuthorNote{氏名D}

本研究の有効性は、二度寝という行動を「起床後にベッドへ戻る」という観測可能な現象へ置き換えた点にある。眠気そのものを直接測ることは難しいが、ベッド荷重の変化なら安価なセンサで扱える。特に、カメラやマイクを使わないため、寝室で使う装置として心理的な抵抗を小さくできる可能性がある。

一方で、荷重だけに頼る方式には限界もある。たとえば、ベッドの上に荷物を置いた場合や、利用者がベッド端に腰掛けた場合、荷重の大きさだけでは在床と誤判定する可能性がある。また、ロードセルの設置位置によって測定値が変化するため、実機導入時には校正が不可欠である。今回の実機では、初期の読み取り不良はソフトウェア修正により解消し、4個構成での動作を確認できた。一方で、後日にロードセル1個のセンサ線を断線したため、最終検証では2個構成へ変更した。これにより荷重分布の情報は少なくなったが、本研究で必要なのは体重の絶対値ではなく、空床状態と在床状態の差を安定して検出することである。2個構成でも校正後に既知荷重を誤差1\%未満の kg 相当値として読み取れたため、在床・離床判定の基礎検証には有効であった。

この経験から、実機開発では回路図通りに配線するだけでなく、断線、接触不良、電源電圧、HX711 の応答、ソフトウェアの読み取り処理を順に切り分けることが重要だと分かった。特にロードセルは微小電圧を扱うため、線が細く、引っ張りや固定不足の影響を受けやすい。今後は、はんだ付け部の保護、ケース内でのケーブル固定、コネクタ化により、測定以前の故障要因を減らす必要がある。

ソフトウェア面では、状態遷移による設計が扱いやすかった。判定の流れが明確で、ログを見ればどの条件でイベントが起きたか説明できる。これは初期開発や授業発表に向いている。ただし、利用者の睡眠習慣が多様であることを考えると、将来的には曜日、起床予定時刻、過去の失敗履歴などを用いて、しきい値や監視時間を自動調整する仕組みが有効である。

\section{まとめと今後の課題}
\label{sec:conclusion}
\AuthorNote{全員}

本研究では、ロードセルによる荷重センシングを用いて、起床後に再びベッドへ戻る行動を検出する二度寝防止システムを開発した。Raspberry Pi 上で動作する Python プログラムとして、センサ入力、状態判定、ログ出力、通知イベント、Web UI を構成し、さらに Android ネイティブアプリから状態確認、設定変更、校正、スマートフォン側アラーム鳴動を行えるようにした。

得られた成果は三点に整理できる。第一に、模擬センサによる試験で、二度寝検出までの状態遷移とイベント出力を再現的に確認した。第二に、実機では電源電圧・励起電圧・差動電圧をテスターで実測し、初期の読み取り不良を配線不良ではなく HX711 読み取り処理の実装ミスとして切り分け、修正後に4個ロードセル構成でのサンプル取得を確認した。第三に、後日に発生したロードセル1個の断線へ対応するため最終検証では2個ロードセル構成へ変更し、既知重量によるゼロ点・スケール校正と荷重変化の読み取りを確認した。以上より、本研究の範囲では、判定ロジック、ソフトウェア構成、実機荷重読み取りの成立性を示すことができた。

今後の課題は、第一に実使用に近い条件での測定安定性評価である。ベッド構造、床面、センサ固定方法により値が変化するため、校正方法と設置方法を決める必要がある。第二に、誤検出を減らすことである。寝返り、荷物、短時間の着座などを区別するには、判定比・フィルタ・確認時間といったパラメータの調整が考えられる。第三に、ハードウェアの信頼性向上である。後日に発生したようなセンサ線切れを避けるため、断線しにくい固定、ケーブル保護、コネクタ化を進め、必要に応じて4個ロードセル構成へ復帰できるようにする。第四に、通知方法の改善である。Android アプリのスマホアラームを中心に、通知権限、音量、再通知間隔、照明制御、家族への通知など、利用場面に応じた出力を選べると実用性が高まる。

導入ゼミナールでの自由研究としては、電気電子工学の要素であるセンサ計測、A/D 変換、組込み処理、情報通信、ユーザインタフェースを一つの具体的な生活課題へ結びつけられた。今後、実機実験を重ねることで、より信頼性の高い起床支援システムへ発展させたい。

\section*{参考資料}
\begin{enumerate}
  \item Avia Semiconductor, ``HX711 24-Bit Analog-to-Digital Converter (ADC) for Weigh Scales,'' データシート.
  \item Raspberry Pi Ltd, ``Raspberry Pi Documentation''（2026年7月参照）. \url{https://www.raspberrypi.com/documentation/}
  \item 本プロジェクトの公開リポジトリ一式（README、Raspberry Pi 側実装、Android アプリ実装、単体テスト）. \url{https://github.com/yuki771555/2dosui}
\end{enumerate}

\end{document}

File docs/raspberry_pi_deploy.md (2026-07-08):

# Raspberry Pi deployment

This guide deploys 2dosumi to a Raspberry Pi, confirms the HX711/load-cell sensor can be read, calibrates it, and starts the Web UI as a boot service.

The deployment flow is:

- sync code from Windows to the Pi with `ssh` and `scp`
- keep the Pi's calibrated config and secrets on the Pi
- install dependencies into `/home/pi/2dosumi/.venv`
- run the Web UI as `twodosumi-web.service`
- expose `127.0.0.1:8080` through Tailscale Serve

## 1. Confirm SSH access

From this Windows project folder, confirm the Pi is reachable:

```powershell
ssh pi@raspberrypi.local
```

The defaults used by the deploy script are:

| Setting | Default |
| --- | --- |
| HostName | `raspberrypi.local` |
| User | `pi` |
| RemoteDir | `/home/pi/2dosumi` |
| Port | `8080` |

Adjust `HostName`, `User`, `RemoteDir`, and `Port` if your Pi differs.

## 2. Deploy from Windows

From this Windows project folder:

```powershell
.\scripts\deploy_pi.ps1 -HostName raspberrypi.local -User pi -RemoteDir /home/pi/2dosumi
```

If you are intentionally testing the current uncommitted working tree, add `-AllowDirty`:

```powershell
.\scripts\deploy_pi.ps1 -AllowDirty
```

The script copies application code, docs, scripts, `requirements-pi.txt`, and `README.md`. It creates `config/pi.aggregate.json` only when the Pi does not already have one.

Do not overwrite the Pi's existing `config/pi.aggregate.json` or `config/secrets.json` during normal updates. Calibration values, Web UI settings, webhook settings, and the generated token live there.

The script also creates or refreshes `.venv`, installs Pi dependencies, installs/restarts `twodosumi-web.service`, and verifies:

```bash
curl http://127.0.0.1:8080/healthz
```

If virtual environment creation fails, install venv support on the Pi:

SSH into the Pi:

```bash
ssh pi@raspberrypi.local
sudo apt-get update
sudo apt-get install -y python3-venv
```

Then run the deploy script again from Windows.

The default Pi config uses:

| HX711 | Raspberry Pi |
| --- | --- |
| DT / DOUT | GPIO6 / `board.D6` |
| SCK / CLK | GPIO5 / `board.D5` |
| VCC | 3.3V |
| GND | GND |

## 3. Expose the Web UI with Tailscale

On the Pi, run once:

```bash
tailscale serve --bg 8080
tailscale serve status
```

The Flask service listens only on `127.0.0.1:8080`; Tailscale Serve is the intended remote access path.

On first Web UI launch, `config/secrets.json` is created with a `web_ui_token`. Check the service log to see it:

```bash
journalctl -u twodosumi-web.service --no-pager -n 50
```

## 4. First sensor check

Before calibration, verify the Pi can read raw samples:

```bash
cd /home/pi/2dosumi
. .venv/bin/activate
python -m twodosumi check-sensor --config config/pi.aggregate.json --samples 10
```

Expected:

- `ok=True`
- `samples=10/10`
- raw `min`, `max`, and `median` values are printed

If it fails with `HX711 DOUT stayed HIGH`, check HX711 power, ground, DT/DOUT, SCK/CLK, and the load-cell bridge wiring.

You can also run this from the Web UI with the `センサー確認` button in the calibration section. It temporarily stops the managed detection process if needed, reads samples, and restarts it afterward.

## 5. Calibrate

With the bed empty:

```bash
python -m twodosumi calibrate-zero --config config/pi.aggregate.json
```

Put a known weight on the bed and run:

```bash
python -m twodosumi calibrate-scale --config config/pi.aggregate.json --known-kg 8
```

Replace `8` with the actual known weight in kg.

Run the sensor check again. The `weight_median_kg` should be close to the current load.

## 6. Service operation

Useful checks:

```bash
systemctl status twodosumi-web.service --no-pager
journalctl -u twodosumi-web.service -f
tailscale serve status
curl http://127.0.0.1:8080/healthz
```

To reinstall the service manually:

```bash
cd /home/pi/2dosumi
APP_DIR=/home/pi/2dosumi APP_USER=pi PORT=8080 ./scripts/install_twodosumi_web_service.sh
```

To start the Web UI manually for debugging:

```bash
cd /home/pi/2dosumi
. .venv/bin/activate
python -m twodosumi web --config config/pi.aggregate.json --secrets config/secrets.json --host 127.0.0.1 --port 8080
```

## 7. Daily operation

Open the Web UI through Tailscale, enter the `web_ui_token`, then:

1. Run `センサー確認`.
2. Check the live weight/status.
3. Configure scheduled alarms.
4. Press `開始` to start detection.

For later updates, run:

```powershell
.\scripts\deploy_pi.ps1
```

Use `-AllowDirty` only when you intentionally want to send uncommitted local changes to the Pi.

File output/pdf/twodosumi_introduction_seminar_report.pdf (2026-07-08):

## 電気電子工学導入ゼミナール自由研究

# 荷重センシングによる二度寝防止システムの開発

○班

## 提出日 2026 年 7 月 23 日

班番号 ○班

学籍番号 | 氏名

## 20XXXXXX 氏名 A 20XXXXXX 氏名 B 20XXXXXX 氏名 C 20XXXXXX 氏名 D

目次

番号 | 項目 | 担当者 | ページ
1 | 研究背景と目的 | 氏名 A | 2
2 | 提案システムの概要 | 氏名 B | 2
3 | ハードウェア・回路・ソフトウェア構成 | 氏名 B | 3
4 | 二度寝判定アルゴリズム | 氏名 C | 6
5 | 実装内容 | 氏名 C | 7
6 | 模擬試験・実機確認と結果 | 氏名 D | 8
7 | 考察 | 氏名 D | 11
8 | まとめと今後の課題 | 全員 | 11

本稿では、Raspberry Pi とロードセルを用いてベッド上の荷重変化を読み取り、起床後に再びベッドへ戻る行 動を検出する二度寝防止システム「2dosumi」の開発について報告する。本研究では、二度寝を「離床後の再在

床」という観測可能な状態遷移として定義し、荷重値のしきい値、監視時間、再在床の継続時間を組み合わせ て判定する方式を採用した。模擬センサによる状態遷移の確認に加え、実機ではテスターによる電圧測定にも とづく不具合の切り分け、既知重量を用いたゼロ点・スケール校正、荷重変化の読み取りまでを確認した。

※提出前に、班番号・学籍番号・氏名・担当者名を実情報に置き換えること。

荷重センシングによる二度寝防止システムの開発 | 電気電子工学導入ゼミナール自由研究

## 1 研究背景と目的

（担当：氏名 A）

朝の起床直後は、目覚ましを止めたあとに再び寝床へ戻る「二度寝」が起こりやすい。スマートフォンのア ラームは音や振動によって覚醒を促すが、ユーザが一度アラームを止めてしまうと、その後に本当に起き続け ているかを確認できない。そこで本研究では、寝床に戻ったという行動そのものを検出し、二度寝の直前また は直後に再通知できるシステムを目標とした。
本研究の着眼点は、映像やマイクではなく荷重センサを用いることである。ベッドの脚やマットレス下に ロードセルを設置すれば、利用者の在床・離床を、比較的プライバシーを保ったまま観測できる。画像認識に 比べて得られる情報は少ないが、起床支援という目的に対しては「ベッド上にいるか」「離床後に戻ったか」と いう低次元の情報で十分である。既存の起床支援方法と本研究の位置づけを表 1 に整理する。

表 1 既存の起床支援方法と本研究の位置づけ

方式 | 長所 | 弱点 | 本研究との関係
スマートフォンアラーム 導入が容易 | 停止後の行動を見ない | 基本通知として併用
| | | 可能
カメラ監視 | 行動を細かく把握可能 | プライバシー負担が大 きい | 本研究では採用しない
ウェアラブル | 身体状態を測定可能 | 装着忘れがある | 非装着型を目指す
荷重センシング | 在床変化を直接検出 | 設置・校正が必要 | 本研究の中心

研究目的は次の三点である。第一に、ロードセルから得られる荷重値をもとに在床状態を推定すること。第 二に、離床後に一定時間以内で再び在床した場合を「二度寝リスク」として判定すること。第三に、判定結果 を Web 画面や通知機構へつなげ、実用的な起床支援システムとして扱える形にすることである。

## 2 提案システムの概要

（担当：氏名 B）
提案システムは、ベッド下の荷重センサ、Raspberry Pi 上の判定プログラム、利用者が状態を確認する Web インタフェースおよび Android ネイティブアプリから構成される。センサは寝床の荷重を周期的に読み取り、 プログラムはその値をしきい値と時間条件で解釈する。二度寝が疑われる状態になると、Android アプリがス マートフォン側でアラーム音と通知を出し、必要に応じて Webhook や Raspberry Pi 側ブザーも補助通知とし

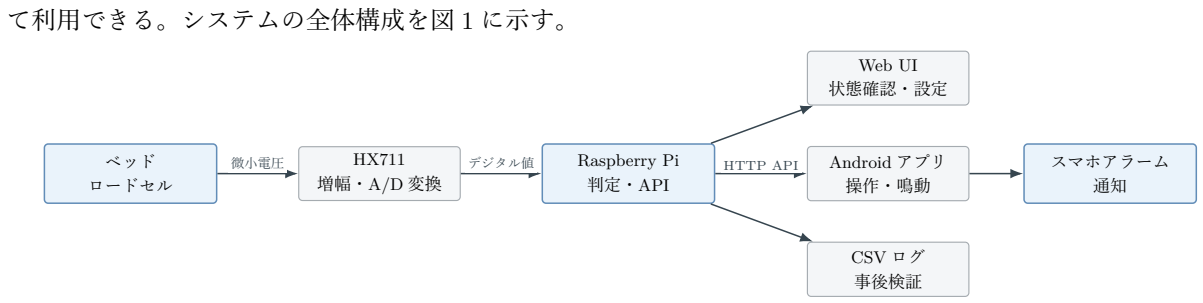
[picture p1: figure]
て利用できる。システムの全体構成を図 1 に示す。; ベッド; ロードセル; Raspberry Pi 判定・API; Web UI; 状態確認・設定; Android アプリ; CSV ログ; 事後検証; スマホアラーム 通知; 微小電圧; デジタル値; HTTP API

図 1 提案システムの全体構成

本システムが扱う状態は、主に「在床」「離床後監視」「再在床」「二度寝検出」であり、監視時間内に戻らな ければ「起床成功」となる。重要なのは、単にベッドにいるかどうかではなく、起床予定時刻付近で一度離床

した後に戻るという時間的な流れを扱う点である。このため、瞬間的なしきい値判定だけではなく、離床から 再在床までの経過時間も判定に用いる。

## Android ネイティブアプリは、Raspberry Pi 側の HTTP API に接続する日常利用の窓口として位置づけた。

Web ブラウザでも状態確認は可能だが、利用者が自分から開く必要があるため、二度寝しかけている利用者へ 情報を届ける手段としては受動的である。ネイティブアプリであれば Foreground Service と通知を用いて画面

消灯中も状態を監視し、スマートフォン本体からアラーム音を鳴らせる。 起床直後には、枕元の端末から現在状態、重量値、次回アラーム、再確認状態を少ない操作で確認できる。 さらに、音量、通知の有無、アラーム設定、二度寝確定までの秒数、再確認間隔、ゼロ点校正、既知重量による スケール校正、センサ確認などを同じ画面から変更できる。このようにアプリは将来の拡張ではなく、通知を 受け取り設定を調整するというシステムの利用体験そのものを担う要素である。 実装済みのプログラムでは、設定ファイルからセンサ種別、しきい値、通知方法、Web サーバ設定などを読

み込める。これにより、実機ロードセルがない環境でも模擬センサを用いて判定ロジックを検証できる。また、 設定値を変更することで、ベッドや利用者の体重差に応じた調整を行える設計とした。

## 3 ハードウェア・回路・ソフトウェア構成

（担当：氏名 B）
ハードウェア面では、Raspberry Pi、HX711、ロードセル、スマートフォンアプリによる通知を中心に構成す る。ロードセルは微小なひずみを電気信号へ変換するセンサであり、HX711 はロードセル用の高分解能 A/D 変換器として広く使われている。Raspberry Pi は HX711 から得られる値を読み取り、Python プログラムで状 態判定を行う。主要な構成要素を表 2 にまとめる。

表 2 主要構成要素

分類 | 要素 | 役割
センサ | ロードセル | ベッド上の荷重変化を測定する
変換回路 | HX711 | ロードセル信号を Raspberry Pi で扱える値
| | に変換する
処理部 | Raspberry Pi | 状態判定、通知、Web UI 提供を行う
通知部 | Android アプリ、通知、スマホ音 | 二度寝検出時に利用者へ知らせる
表示部 | Web ブラウザ | 現在状態、履歴、設定値を確認する
モバイル部 Android ネイティブアプリ | 状態確認、設定、校正、アラーム鳴動を行う

回路面で当初想定した標準構成は、4 個のロードセルを組み合わせたホイートストンブリッジである（図 2）。

ロードセル内部のひずみゲージは、荷重を受けると抵抗値がわずかに変化する。しかし、その変化は非常に小 さく、Raspberry Pi の GPIO へ直接入力しても読み取れない。そこで、4 個のロードセルをブリッジの 4 辺と して構成し、左右の中点間に現れる差動電圧を HX711 で増幅・A/D 変換する。ブリッジ構成には、抵抗変化 を差動電圧として取り出すことで感度を高められるうえ、温度変化のように 4 個の抵抗へ同じ向きに現れる変

動を打ち消せるという利点がある。
実機検証では当初 4 個構成で組み、初期の読み取り不良は HX711 読み取り処理の実装ミスを修正することで 解消し、4 個構成でもサンプル取得できることを確認した。その後、別日にロードセル 1 個のセンサ線を断線 してしまったため、最終的な実機検証では故障したロードセルを外し、2 個の半橋ロードセルで 1 つのブリッ

ジを構成する方式へ変更した。これは初期の読み取り不良とは別の事象であり、測定方式を単に簡略化したの ではなく、実験を継続するための故障対応である。本研究の目的は体重を高精度に量ることではなく、在床、

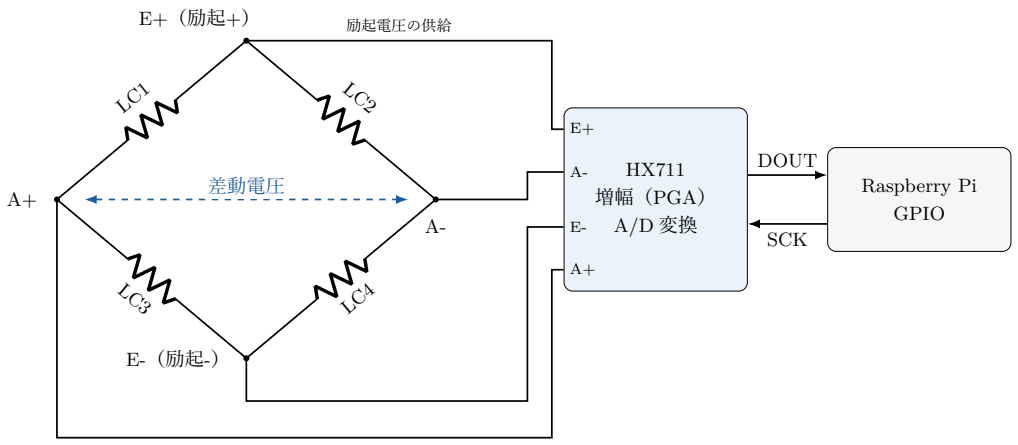
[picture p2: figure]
差動電圧; HX711 増幅（PGA） A/D 変換; 励起電圧の供給; Raspberry Pi GPIO; DOUT; SCK

## 図 2 4 個のロードセル（LC1〜LC4）で構成したホイートストンブリッジと HX711・Raspberry Pi の接続

離床、再在床の大きな荷重変化を判定することであるため、2 個構成でも判定ロジックの検証には十分である と判断した。実機検証で用いた 2 個ロードセル版の接続を図 3 と表 3 に示す。

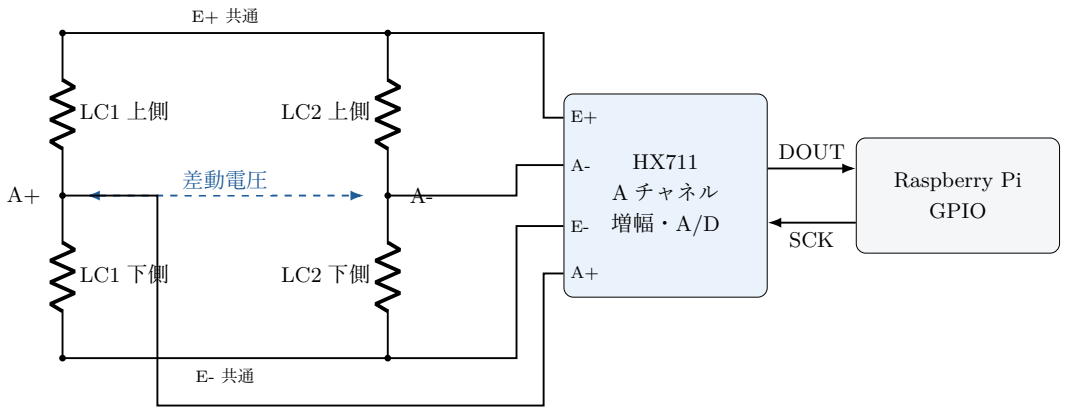
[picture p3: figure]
A- 差動電圧; HX711 A チャネル 増幅・A/D; Raspberry Pi GPIO; DOUT; SCK

図 3 実機検証で用いた 2 個の半橋ロードセルによるブリッジ構成

2 個のロードセルは向きや荷重のかかり方により、A+ と A- の符号が期待と逆になる場合がある。その場合 でも故障とは限らず、既知重量を用いた校正でスケール係数の符号が決まり、ソフトウェア上では kg 相当値と して扱える。本研究の実機でも、既知重量による校正後に荷重を kg 相当値として読み取れることを確認した （第 6 節）。
HX711 基板では、ロードセル側の端子は一般に E+、E-、A+、A- と表記される。E+ と E- は HX711 基板 側からブリッジへ電圧を供給する励起端子であり、A+ と A- はブリッジの左右の中点から差動電圧を受け取る 入力端子である。荷重がないときは左右の分圧がほぼ等しく、A+ と A- の電位差はほぼ 0 V になる。荷重が

かかると一部のゲージが伸び、別のゲージが縮むため、片側の抵抗はわずかに増え、反対側はわずかに減る。 励起電圧を VE、無荷重時の各辺の抵抗を R、荷重による変化分を ∆R とし、対角の 2 辺が +∆R、残りの 2 辺

が −∆R と逆向きに変化する理想的な場合を考えると、左右の分圧の差として現れる出力電圧は

VA+ − VA− =

∆R
R

VE

となり、抵抗の変化率に比例した電圧が得られる。実際の ∆R/R はごく小さく、この差動電圧は数 mV 程度と 微小であるため、HX711 は内部のプログラマブルゲインアンプ（チャネル A では 128 倍）で増幅したうえで、

## 24 ビットの A/D 変換器によりデジタル値へ変換し、DOUT・SCK の 2 線シリアルで Raspberry Pi へ送る（表

4）。

## Raspberry Pi で使う場合は、GPIO が 3.3 V 入力である点に注意する。HX711 モジュールには 5 V 動作品も

多く、DT 端子の High レベルが 5 V のままでは GPIO を傷めるおそれがあるため、本研究では HX711 を 3.3

表 3 2 個ロードセル構成での端子接続

端子 | 接続先
E+ | 2 個のロードセルの上側外端を共通接続
E- | 2 個のロードセルの下側外端を共通接続
A+ | 1 個目ロードセルの中点
A- | 2 個目ロードセルの中点
VCC | Raspberry Pi の 3.3 V
GND | Raspberry Pi の GND

## DT / DOUT Raspberry Pi の GPIO6（D6） SCK / CLK Raspberry Pi の GPIO5（D5）

## 表 4 HX711 と Raspberry Pi の接続例

端子 | 接続先 | 役割
E+ / E- | ロードセルブリッジの電源端 | ブリッジ回路へ励起電圧を与える
A+ / A- | ブリッジの左右中点 | 荷重で変化する差動電圧を入力する
VCC / GND Raspberry Pi の 3.3 V / GND | HX711 基板へ電源を供給する
DT / DOUT Raspberry Pi の GPIO6（D6） | 変換完了とデータ出力を受け取る
SCK / CLK Raspberry Pi の GPIO5（D5） | クロックを送り、データ読み出しとゲイン
| | 設定を行う

V で駆動した。また、センサ配線は微小電圧を扱うため、長い配線や電源ノイズ、断線の影響を受けやすい。 実機では、ロードセルの固定と荷重分散に注意し、ゼロ点補正と既知重量による校正で読み取り値を kg 相当へ

変換する。
ソフトウェアは Raspberry Pi 側の Python プログラムと、スマートフォン側の Android ネイティブアプリに 分けて構成した。Raspberry Pi 側では、センサ入力、判定器、通知、Web サーバを分離し、それぞれの責務を

小さくした。これにより、実機センサから模擬センサへ切り替えても、判定器や表示側のコードを大きく変え ずに試験できる。

## Android アプリは Kotlin と Jetpack Compose により実装し、Retrofit/OkHttp を用いて、Raspberry Pi が公

開する状態 API、設定 API、校正 API を呼び出す。センサ値を直接読まずに API 経由とすることで、ロード セルや HX711 に近い低レベル処理は Raspberry Pi に集約し、スマートフォン側は操作性と表示に集中できる。

### 3.1 筐体（3D プリントケース）の設計

## 当初設計では、ロードセル 4 個、HX711、Raspberry Pi を一体化した体重計型の筐体を OpenSCAD で設計

し、3D プリンタ（Bambu A1 mini、造形範囲 180 × 180 mm）で製作する構成を想定した。筐体はベッドの 脚 1 本の下に敷き、その脚にかかる荷重の変化から在床・離床を読み取る。構成は、ロードセル・HX711・

## Raspberry Pi を収める下皿（168 mm 角）、その上に浮かべる上蓋（175.8 mm 角）、脚を受けるリング、および

残り 3 本の脚の高さを揃えるスペーサー 3 個であり、全高は 34 mm である。設計の要点は荷重経路にある。脚 の荷重は上蓋から裏面の 4 個のボスを介してロードセル中央の受圧ボタンのみに伝わり、下皿の支持台（ペデ スタル）を経て床へ抜ける。上蓋は電子部品のどこにも接触せず（Raspberry Pi 最上部との隙間 2.6 mm）、外

周のスカートは横ズレとほこりの侵入を防ぐだけで荷重を負担しない。これは市販の体重計と同じ構造であり、 4 個構成では各ロードセルに荷重が分配される。設計した筐体の組立状態と断面を図 4 に示す。

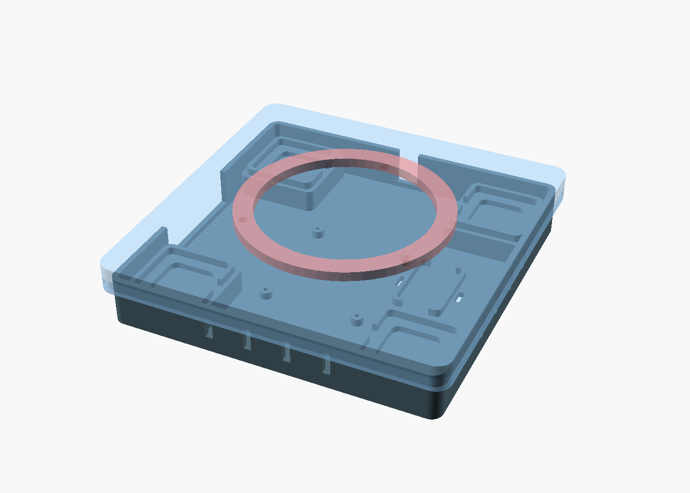
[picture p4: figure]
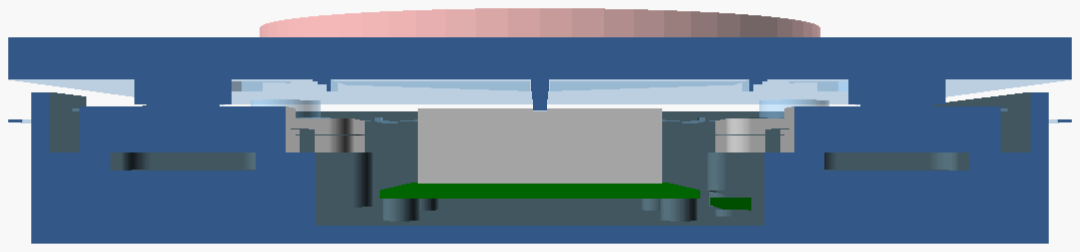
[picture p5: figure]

図 4 設計した筐体の組立ビュー（左）とロードセル中心線での断面（右）。断面では上蓋がロードセルの受圧ボタン 4 点 のみに接触し、中央の Raspberry Pi（緑・灰）と隙間を保っていることが分かる

当初設計の耐久性は、荷重をほぼすべて「圧縮」で受ける構造とすることで確保した。3D プリント 品は曲げや積層はく離に弱い一方、押し潰す方向には強いためである。ロードセルの定格は 4 個構成で 50 kg × 4 = 200 kg であり、就寝時にこの脚へかかる荷重（数十 kg）に対して十分な余裕がある。曲げを受ける 唯一の部品は上蓋であり、板厚 7 mm に加えて裏面に深さ 5 mm のリブを配置し、Raspberry Pi の直上のみリ

ブを省いてクリアランスを確保した。また、樹脂は常時荷重でわずかに変形が進む（クリープ）ため、長期間 の使用ではゼロ点が徐々にずれ得るが、これは Web UI からのゼロ点校正で補正できる。製作時の主な印刷条 件を表 5 に示す。曲げ剛性が必要な上蓋のみ壁数と充填密度を高め、圧縮しか受けない部品は標準設定として

印刷時間を抑えた。

表 5 3D プリントの主な条件（材料は PETG、積層ピッチ 0.2 mm、サポート材なし）

部品 | 壁面層数 充填密度 補足
上蓋 | 4 | 25% | トップ面・底面各 5 層。唯一曲げを受けるため強化する
下皿 | 3 | 15% | 床に全面接地するため曲げがかからない
スペーサー（3 個） 2 | 10〜15% 圧縮のみ。本体と同高にしてベッドを水平に保つ
脚受けリング | 2 | 15% | 脚の横ズレ防止用

当初設計の組立では、ロードセルは下皿四隅のポケットにはめ込むだけで位置が決まり、上蓋のボスが上か ら押さえる。HX711 は中央のベイに収め、床の貫通スロットに通した結束バンドで固定する。Raspberry Pi は 下皿のスタンドオフ 4 本（Pi 4 の取付穴ピッチ 58 × 49 mm に対応、下穴 φ2.2 mm）に M2.5×6 mm の小ネジ をセルフタップでねじ込んで固定し、USB-C 電源ケーブルは側壁のスリットから外へ引き出す。設置面が沈む

と支持台が傾き測定が不安定になるため、カーペット上への直置きは避け、フローリングか板の上に設置する。

## 4 二度寝判定アルゴリズム

（担当：氏名 C）

判定アルゴリズムは状態遷移として設計した。センサ値には揺らぎがあるため、単一のしきい値で在床・離 床を切り替えると、境界付近で判定が細かく振動してしまう。そこで本システムでは、荷重値を設定した利用 者体重に対する比率へ換算したうえで、離床の判定（体重比 0.3 未満）と再在床の判定（体重比 0.4 超）に異な

るしきい値を用いるヒステリシスを持たせた。さらに、離床後の監視時間と、再在床の継続を確かめる確認時 間を組み合わせることで、瞬間的な変動だけで二度寝と決めない設計とした。状態遷移の全体を図 5 に、判定 に用いる主なパラメータを表 6 に示す。

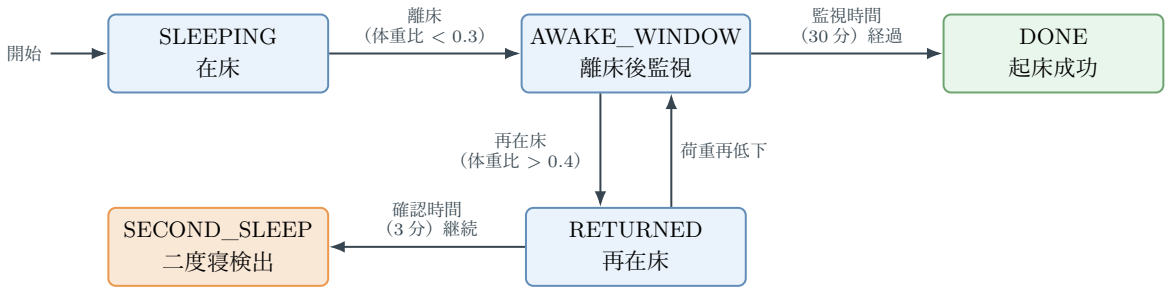
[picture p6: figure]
SLEEPING; AWAKE_WINDOW; 離床後監視; DONE; 起床成功; RETURNED; 再在床; SECOND_SLEEP; 二度寝検出; 離床 （体重比 < 0.3）; 監視時間 （30 分）経過; 再在床 （体重比 > 0.4）; 荷重再低下; 確認時間 （3 分）継続

図 5 二度寝判定の状態遷移（緑：正常終了、橙：二度寝検出。しきい値と時間は表 6 の既定値）

表 6 判定に用いる主なパラメータ（既定値。設定ファイルで変更できる）

パラメータ | 既定値 意味
離床判定比 | 0.3 | 体重比がこの値を下回ると離床とみなす
再在床判定比 | 0.4 | 離床後、体重比がこの値を超えると再在床とみなす
監視時間 | 30 分 | 離床後に再在床を見張る時間
確認時間 | 3 分 | 再在床がこの時間続くと二度寝と確定する
中央値フィルタ 9 点 | 複数サンプルの中央値で 1 回分の読み値を決める
移動平均 | 5 点 | 判定前に読み値の列を平滑化する

この方式の利点は、判定理由を説明しやすいことである。機械学習モデルを用いる場合、多様なデータを集 めれば複雑な行動を分類できる一方、少数データでは過学習や説明困難性が問題になる。本研究段階では、ま ず比率のしきい値と時間条件による確実な基礎機能を作り、将来的にデータが蓄積した段階で学習型の判定へ 拡張する方針とした。
処理の流れをまとめると、次のようになる。
1. センサ値を一定周期で取得し、中央値フィルタと移動平均で平滑化する。
2. 平滑化した値の体重比が離床判定比を下回ったら、離床時刻を記録して監視を始める。
3. 監視時間内に体重比が再在床判定比を超えたら、再在床状態へ移る。監視時間を過ぎれば、起床成功とし

て監視を終える。
4. 再在床が確認時間続けば、二度寝検出として通知する。途中で荷重が再び下がった場合は監視状態へ戻る。

## 5 実装内容

（担当：氏名 C）
実装では、コマンドライン実行、Web サーバ、設定ファイル、ログ出力、Android アプリ、テストを用意し た。コマンドラインからは通常実行と模擬実行を切り替えられる。Web サーバは現在の状態やイベント履歴を 返す API を持ち、簡易画面から状態確認と設定変更ができる。ログは時刻、荷重値、状態、イベントを残すた め、後から判定が妥当だったかを確認できる。Raspberry Pi 側のモジュール分割と依存関係を図 6 に、実装し た主な機能を表 7 に示す。

模擬センサを用意した理由は、実機環境がなくても判定器の振る舞いを再現できるようにするためである。 開発初期に実機だけへ依存すると、配線ミスやセンサ固定方法の問題と、ソフトウェアのバグが混ざってしま う。模擬入力で「期待する状態遷移が起こる」ことを先に確認しておくことで、実機試験時の切り分けが容易

になる。
また、Web UI と Android アプリを持たせたことで、実験中にターミナルを見続けなくても現在状態を確認

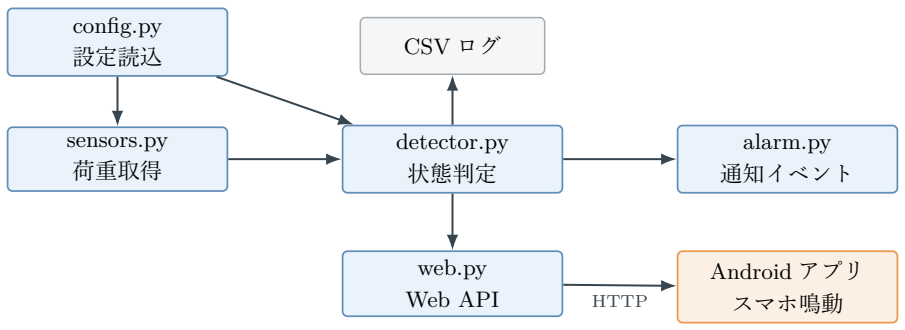
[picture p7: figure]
sensors.py; 荷重取得; config.py; 設定読込; detector.py; 状態判定; alarm.py; 通知イベント; CSV ログ; web.py Web API; Android アプリ; HTTP; スマホ鳴動

図 6 ソフトウェアのモジュール分割（青：Raspberry Pi 側の Python モジュール、橙：スマートフォン側、灰：データ）

表 7 実装した主な機能

機能 | 内容
設定読込 | JSON 設定から判定比、監視・確認時間、通知方法を指定する
センサ抽象化 | 実機 HX711 と模擬センサを切り替えられる
平滑化 | 中央値フィルタと移動平均で読み値のノイズを抑える
状態判定 | 離床、再在床、二度寝検出を状態遷移で処理する
通知 | Android アプリのスマホ音、通知、Webhook、補助ブザーに対応する
定時アラーム | 指定時刻に鳴動し、離床の継続を確認する起床ミッションを持つ
Web UI | ブラウザから状態、ログ、設定を確認できる

## Android アプリ Kotlin/Jetpack Compose で状態確認、スマホアラーム、音量調整、校正操作を行う

単体テスト 設定、センサ、判定、Web API の基本動作を確認する

できる。Web UI は PC からの確認や発表デモに向き、Android アプリは起床直後に手元で操作する場面に向

く。特に、スマートフォン側でアラーム一覧、センサ校正、音量、通知、二度寝確定秒数、再確認間隔を変更で

## きるため、利用者が日常的に設定を変える運用を想定できる。アプリは Foreground Service で Raspberry Pi の

状態 API を監視し、時刻アラーム、再アラーム、再入床、二度寝検出のイベントを受けてスマートフォン本体 から音を鳴らす。これにより、Raspberry Pi にブザーを接続しなくても、枕元のスマートフォンを通知装置と

して利用できる。

## 6 模擬試験・実機確認と結果

（担当：氏名 D）

本節では、ソフトウェア上の判定ロジック、実機回路の電気的状態、校正後の荷重読み取りの三段階で確認 した結果を述べる。模擬試験では、実機の配線状態に依存せず、状態遷移そのものが設計どおりに動くかを検 証した。実機確認では、HX711 まわりの電源・励起・差動入力を測定し、読み取り不良の原因を配線とソフト ウェアに分けて切り分けた。最後に、2 個ロードセル構成で校正を行い、在床・離床判定に必要な荷重差を読み 取れるか確認した。結果の要約を表 8 に示す。

### 6.1 模擬センサによる状態遷移の確認

模擬試験では、体重 60 kg の利用者を想定し、在床状態から一度離床し、その後ベッドへ戻る入力列を与え た。確認した実行では、18 サンプルの範囲で「在床」「離床後監視」「再在床」「二度寝検出」の順に状態が遷移

した。これにより、少なくとも設計した状態遷移がソフトウェア上で動作することを確認できた。与えた模擬

表 8 確認結果の要約

確認項目 | 方法 | 結果
状態遷移 | 体重 60 kg 相当の模擬入力 18 サンプル
| を与える

## left_bed、returned、 second_sleep_detected が順に 1 回ずつ

| | 発生
実機切り分け | VCC、励起電圧、A+–A-、導通、DOUT
| の挙動を測定 | 電源・ブリッジ応答は確認でき、初期不 具合は HX711 読み取り処理の実装ミス
| | と判断
4 個構成の確認 | 読み取り処理修正後にサンプル取得を
| 実施 | 4 個ロードセル構成でも変換完了とサン
| | プル取得を確認
最終構成の校正 | 後日の断線対応として 2 個構成へ組み替
| え、ゼロ点・スケール校正を実施 | 既知荷重を 1%未満の誤差で読み取り、
| | 空床と在床相当の値が明確に分離
ソフトウェア試験 設定、センサ、判定、Web API の単体
| テストを実行 | 24 件のテストが通過

入力を図 7 に、確認したイベントを表 9 に示す。図中の 2 本の破線は、離床判定（体重比 0.3、荷重値 18 相当）

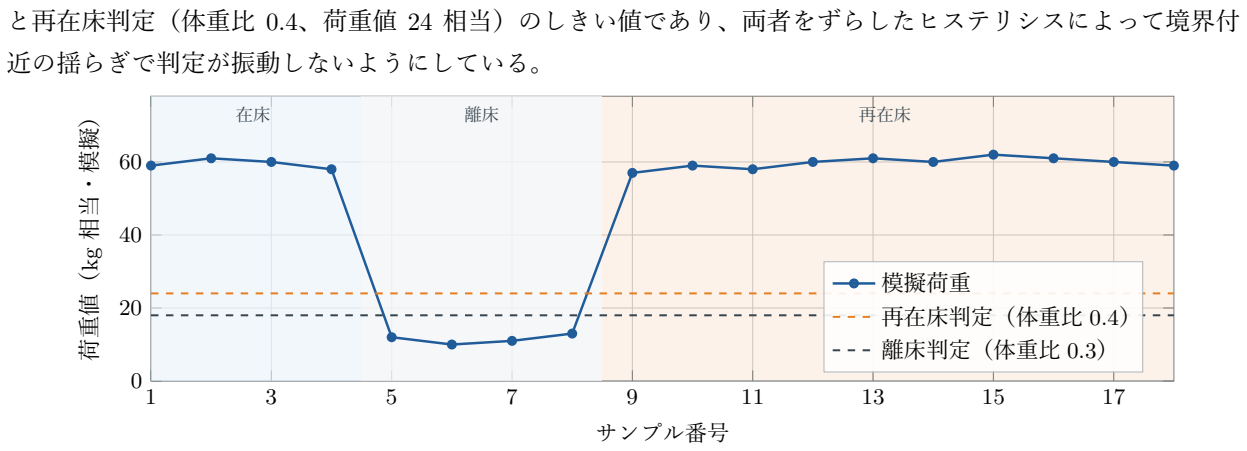
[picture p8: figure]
と再在床判定（体重比 0.4、荷重値 24 相当）のしきい値であり、両者をずらしたヒステリシスによって境界付; 近の揺らぎで判定が振動しないようにしている。; 再在床; サンプル番号; 荷重値（kg 相当・模擬）; 模擬荷重 再在床判定（体重比 0.4） 離床判定（体重比 0.3）

図 7 模擬入力における荷重変化と判定しきい値

表 9 模擬試験で確認したイベント

段階 状態 | 確認内容
初期 SLEEPING | 体重比が十分大きく在床と判定した
離床 AWAKE_WINDOW | 荷重低下により離床後の監視へ移った
復帰 RETURNED | 監視時間内に荷重が戻ったことを検出した
検出 SECOND_SLEEP | 再在床が継続し二度寝イベントを発生させた

模擬試験の実行ログは CSV 形式で保存され、各行に時刻、センサ生値、kg 換算値、平滑化後の値、状態、イ

## ベントが記録される。ログ上でも left_bed（離床）、returned（再在床）、second_sleep_detected（二度寝検出）

の各イベントがこの順で 1 回ずつ出力されており、平滑化後の値がしきい値を横切ったサンプルで状態が切り

替わることを行単位で追跡できた。この試験は繰り返し実行しても同じイベント列が得られ、判定器の動作は 再現的であった。したがって、実機の測定誤差を含まない条件では、設計した状態遷移とイベント出力が意図 どおり機能することを確認できた。

### 6.2 実機の電気的測定と不具合の切り分け

実機は Raspberry Pi、HX711、ロードセルで構成し、まず当初設計どおりの 4 個構成で組み立てた。最初の動 作確認では、HX711 の DOUT が変換完了（Low）にならずタイムアウトする状態と、読み値が 24 ビット A/D

の端点値（±8388607）に張り付く状態が発生し、ソフトウェアからは有効な荷重値を得られなかった。端点値 への張り付きは配線系の異常でも起こり得るため、当初は入力の開放や断線を疑った。そこでテスターを用い、 電源側から信号側へ向かって順に電圧と導通を実測して切り分けを行った。測定箇所と結果を表 10 に示す。

表 10 実機での電気的測定とソフトウェア不具合の切り分け

測定箇所 | 期待される値 | 実測値 | 判断
HX711 の VCC-GND 間 | 3.3 V | 3.3 V | 電源供給は正常
E+ - E- 間（励起電圧） | 電源電圧以下の一定値 | 約 2.68 V | ブリッジへの励起は
| | | 正常
A+ - A- 間（無荷重時） | ほぼ 0 mV | ほぼ 0 mV | ブリッジの平衡は正常
A+ - A- 間（荷重印加時） 数 mV 以下の微小変化 | わずかな変化を確認 | ブリッジ応答は存在
センサ線の導通 | 全線で導通あり | おおむね導通あり | 初期不具合の主因では
| | | ない
HX711 読み取り処理 | 有効サンプルを取得 | 端点値・タイムアウト
| | が発生 | 実装ミスを修正

この測定では、電源、励起、ブリッジの応答、センサ線の導通に大きな異常は確認できず、初期不具合の主 因はセンサ線の断線ではなく、HX711 の読み取り処理におけるソフトウェア実装ミスであると判断した。該当 箇所を修正した後は、4 個ロードセル構成でも DOUT が周期的に変換完了を示し、サンプル取得が成功した。 ただし、後日別の作業中にロードセル 1 個のセンサ線を断線してしまったため、最終的な検証では故障した ロードセルを外し、2 個の半橋ロードセルによるブリッジ構成（図 3）へ組み替えた。したがって、初期不具合 の原因であったソフトウェア実装ミスと、2 個構成へ変更した理由である後日の断線は、別の事象である。 実測値の妥当性は、ロードセルの定格からも確認できる。使用したロードセルの定格出力を約 1 mV/V と仮 定すると、実測した励起電圧 2.68 V では定格荷重時でも差動電圧は約 2.7 mV にとどまり、数十 kg の荷重で は 1 mV 前後となる。これは「無荷重時はほぼ 0 mV、荷重印加でわずかに変化する」という実測結果と整合し ており、HX711 が内蔵アンプで 128 倍に増幅してから A/D 変換する必要性を、実測からも裏付けられた。

### 6.3 校正と荷重読み取りの確認

組み替え後の 2 個構成で、ゼロ点校正とスケール校正を実施した。ゼロ点校正では、寝具を載せた空床状態

で読み値を繰り返し取得し、その中央値をゼロ点とした。起動直後は値が安定しないため、ウォームアップと して最初の 5 サンプルを捨て、その後の読み値へ 9 点の中央値フィルタを適用している。スケール校正では、

既知重量の荷重を載せた状態で生値を取得し、スケール係数を（荷重時の生値 − ゼロ点）÷ 既知重量として算 出した。
校正後に同じ既知荷重を載せ直して読み値を確認したところ、kg 相当値の誤差は約 0.8%（1%未満）であり、

在床・離床判定には十分な精度で変換できることを確認した。また、在床相当の荷重を加えた状態と空床状態 を繰り返して読み値を比較すると、両者は明確に分離しており、離床判定比 0.3・再在床判定比 0.4 のしきい値

（体重比換算）に対して十分な余裕があった。
この結果から、2 個ロードセル構成でも、在床と離床を区別するために必要な大きな荷重変化は取得できる

ことを確認した。ただし、体重計としての絶対精度、寝返りや荷物による誤判定率、利用者ごとのしきい値最

適化は継続検証が必要である。単体テストとしては設定読込、センサ処理、Web API などの基本動作を確認 し、現時点では 24 件のテストが通過している。そのため、本結果は「判定ロジック、ソフトウェア構成、実機

読み取りの成立性」を示すものであり、最終的な実用性能を示すものではない。

## 7 考察

（担当：氏名 D）

本研究の有効性は、二度寝という行動を「起床後にベッドへ戻る」という観測可能な現象へ置き換えた点に ある。眠気そのものを直接測ることは難しいが、ベッド荷重の変化なら安価なセンサで扱える。特に、カメラ やマイクを使わないため、寝室で使う装置として心理的な抵抗を小さくできる可能性がある。 一方で、荷重だけに頼る方式には限界もある。たとえば、ベッドの上に荷物を置いた場合や、利用者がベッ ド端に腰掛けた場合、荷重の大きさだけでは在床と誤判定する可能性がある。また、ロードセルの設置位置に よって測定値が変化するため、実機導入時には校正が不可欠である。今回の実機では、初期の読み取り不良は ソフトウェア修正により解消し、4 個構成での動作を確認できた。一方で、後日にロードセル 1 個のセンサ線を 断線したため、最終検証では 2 個構成へ変更した。これにより荷重分布の情報は少なくなったが、本研究で必 要なのは体重の絶対値ではなく、空床状態と在床状態の差を安定して検出することである。2 個構成でも校正 後に既知荷重を誤差 1%未満の kg 相当値として読み取れたため、在床・離床判定の基礎検証には有効であった。 この経験から、実機開発では回路図通りに配線するだけでなく、断線、接触不良、電源電圧、HX711 の応答、

ソフトウェアの読み取り処理を順に切り分けることが重要だと分かった。特にロードセルは微小電圧を扱うた め、線が細く、引っ張りや固定不足の影響を受けやすい。今後は、はんだ付け部の保護、ケース内でのケーブ ル固定、コネクタ化により、測定以前の故障要因を減らす必要がある。 ソフトウェア面では、状態遷移による設計が扱いやすかった。判定の流れが明確で、ログを見ればどの条件 でイベントが起きたか説明できる。これは初期開発や授業発表に向いている。ただし、利用者の睡眠習慣が多 様であることを考えると、将来的には曜日、起床予定時刻、過去の失敗履歴などを用いて、しきい値や監視時 間を自動調整する仕組みが有効である。

## 8 まとめと今後の課題

（担当：全員）
本研究では、ロードセルによる荷重センシングを用いて、起床後に再びベッドへ戻る行動を検出する二度寝 防止システムを開発した。Raspberry Pi 上で動作する Python プログラムとして、センサ入力、状態判定、ロ グ出力、通知イベント、Web UI を構成し、さらに Android ネイティブアプリから状態確認、設定変更、校正、

スマートフォン側アラーム鳴動を行えるようにした。
得られた成果は三点に整理できる。第一に、模擬センサによる試験で、二度寝検出までの状態遷移とイベン ト出力を再現的に確認した。第二に、実機では電源電圧・励起電圧・差動電圧をテスターで実測し、初期の読 み取り不良を配線不良ではなく HX711 読み取り処理の実装ミスとして切り分け、修正後に 4 個ロードセル構成 でのサンプル取得を確認した。第三に、後日に発生したロードセル 1 個の断線へ対応するため最終検証では 2

個ロードセル構成へ変更し、既知重量によるゼロ点・スケール校正と荷重変化の読み取りを確認した。以上よ り、本研究の範囲では、判定ロジック、ソフトウェア構成、実機荷重読み取りの成立性を示すことができた。 今後の課題は、第一に実使用に近い条件での測定安定性評価である。ベッド構造、床面、センサ固定方法に より値が変化するため、校正方法と設置方法を決める必要がある。第二に、誤検出を減らすことである。寝返 り、荷物、短時間の着座などを区別するには、判定比・フィルタ・確認時間といったパラメータの調整が考え られる。第三に、ハードウェアの信頼性向上である。後日に発生したようなセンサ線切れを避けるため、断線 しにくい固定、ケーブル保護、コネクタ化を進め、必要に応じて 4 個ロードセル構成へ復帰できるようにする。

第四に、通知方法の改善である。Android アプリのスマホアラームを中心に、通知権限、音量、再通知間隔、照

明制御、家族への通知など、利用場面に応じた出力を選べると実用性が高まる。 導入ゼミナールでの自由研究としては、電気電子工学の要素であるセンサ計測、A/D 変換、組込み処理、情

報通信、ユーザインタフェースを一つの具体的な生活課題へ結びつけられた。今後、実機実験を重ねることで、 より信頼性の高い起床支援システムへ発展させたい。

## 参考資料

1. Avia Semiconductor, “HX711 24-Bit Analog-to-Digital Converter (ADC) for Weigh Scales,” データシート.
2. Raspberry Pi Ltd, “Raspberry Pi Documentation”（2026 年 7 月参照）. https://www.raspberrypi.com/

## documentation/ (https://www.raspberrypi.com/documentation/)

## 3. 本プロジェクトの公開リポジトリ一式（README、Raspberry Pi 側実装、Android アプリ実装、単体テ

## スト）. https://github.com/yuki771555/2dosui

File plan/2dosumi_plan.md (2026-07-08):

  
RASPBERRY PI × LOAD CELL

**2度寝防止AIシステム**

開発計画書

*ベッド圧力センシングによる起床・再入床検知システム*

| 作成日 | 2026年4月 |
| :---- | :---- |
| **構成** | 背景 / 問題 / 提案 / 結果 / 今後 |
| **想定予算** | **約 2,500〜3,000円(既存資産除く)** |
| **主要技術** | Raspberry Pi 4 / ロードセル / HX711 / Python / 状態遷移ロジック |

# **文書情報**

本計画書の位置づけ・対象読者・関連文書を以下に示す。

| 文書種別 | 研究開発計画書 |
| :---- | :---- |
| **対象読者** | 指導教員 / 共同研究者 / プロジェクトメンバー |
| **前提知識** | Python基礎・Linuxの基本操作・はんだ付けの基礎 |
| **関連文書** | プレゼンテーション資料(2dosumi\_prevention.pptx) |

# **エグゼクティブサマリー**

本計画書は、ベッドにかかる圧力をRaspberry Pi 4とロードセルでリアルタイム検知し、「2度寝(再入床)」を自動判定して通知するシステムの研究開発計画である。音アラームでは解決できない「アラーム後の再入床」を物理的に検知することが本研究の中核価値である。

## **研究の3行要約**

| 背景 | 睡眠管理への関心が高まり、IoT技術の民主化により個人DIYデバイスが現実化 |
| :---- | :---- |
| **問題** | 既存のアラーム・睡眠デバイスは「再入床」を物理的に検知できない |
| **提案** | ロードセル4個でベッド荷重を計測、状態遷移ロジック+ML+LLMで2度寝を判定・通知 |

## **主要な数字**

| 項目 | 値 | 項目 | 値 |
| ----- | :---: | ----- | :---: |
| **追加コスト** | **約3,000円** | **実装期間** | **1〜2週間** |
| **センサー数** | **4個(50kg)** | **目標精度(F1)** | **0.85以上** |
| **Phase数** | **3段階+任意** | **試作環境** | **椅子→ベッド** |

## **研究のゴールと評価軸**

* **機能ゴール:** 2度寝を自動検知し、段階的な通知でユーザーに介入する

* **技術評価軸:** ルールベース vs 機械学習(ML) vs LLM補助 — 3アプローチの精度比較(F1スコア)

* **コスト評価:** 市販品の1/10以下のコストで「再入床検知」という独自機能を実現

* **再現性:** 本計画書通りに作業すれば誰でも実装可能なレベルの手順書

## **読み方ガイド**

時間がない読者は、以下の優先順位で読むことを推奨する。

1. 第3章「提案」 — システム全体像と必要部品

2. 第4章「結果」 — 何ができるようになるか

3. 第5章「今後」 — AI・LLM活用の発展可能性

4. 付録A〜D — 配線・コード・チェックリスト

# **目次**

|  | 文書情報 | 2 |
| :---- | :---- | ----: |
|  | エグゼクティブサマリー | 3 |
|  | 目次 | 4 |
| **1\.** | **背景 — こういう状況・社会になってきた** | **5** |
| 1.1 | 睡眠への関心が急速に高まっている | 5 |
| 1.2 | IoT・センシング技術の民主化 | 5 |
| 1.3 | 「睡眠の計測」から「行動の検知」へ | 5 |
| **2\.** | **問題 — でも、こういう問題がある** | **6** |
| 2.1 | アラームは「鳴る」が「起こす」ことはできない | 6 |
| 2.2 | 2度寝は「意図的な行動」ではない | 6 |
| 2.3 | 既存の解決手段の限界 | 6 |
| 2.4 | 問題の本質 | 6 |
| **3\.** | **提案 — そこで、こういう方法・デバイスを提案する** | **7** |
| 3.1 | 提案の概要 | 7 |
| 3.2 | システム全体構成 | 7 |
| 3.3 | 判定のしくみ — 状態遷移モデル | 7 |
| 3.4 | 必要部品と構成コスト | 8 |
| 3.5 | 実装計画 — 段階的アプローチ | 9 |
| 3.6 | 延長配線の実作業 — はんだ付けによる1m延長 | 10 |
| 3.7 | キャリブレーション手順 | 11 |
| **4\.** | **結果 — こういうことができる** | **12** |
| 4.1 | 実現できること | 12 |
| 4.2 | システム動作の流れ(具体例) | 12 |
| 4.3 | 1個構成と4個構成の比較 | 13 |
| 4.4 | コスト効果 | 13 |
| **5\.** | **今後 — こういう展開があり得る** | **14** |
| 5.1 | AIによる個人最適化 — ルールベースの先へ | 14 |
| 5.2 | LLMの活用 — MLと組み合わせた高度な判断・対話 | 16 |
| 5.3 | センサーの拡張 | 18 |
| 5.4 | 通知・介入の強化 | 18 |
| 5.5 | データ活用・可視化 | 19 |
| 5.6 | 製品化・外部展開の可能性 | 19 |
| 5.7 | ロードマップ全体像 | 19 |
| **付録A** | **配線表** | **20** |
| 付録B | 最小動作コード(試作1号) | 20 |
| 付録C | 2度寝判定コード(疑似コード) | 21 |
| 付録D | 実装前チェックリスト | 21 |
| **付録E** | **用語集** | **22** |
| **付録F** | **参考資料・関連リンク** | **23** |

# **1\. 背景 — こういう状況・社会になってきた**

## **1.1 睡眠への関心が急速に高まっている**

近年、生産性・健康・メンタルウェルネスへの社会的関心の高まりとともに、「睡眠の質」は個人の重要な管理指標となった。スマートウォッチやスマートフォンアプリによる睡眠ログの記録は一般化し、「何時間寝たか」「深い眠りが何分あったか」を日常的に把握する人が増えている。

また、リモートワークの普及により在宅勤務者が増えたことで、起床時刻の自己管理の重要性はさらに増している。オフィスへの通勤という物理的強制力がなくなった環境では、自分自身で起床リズムを維持することが生活の質と仕事のパフォーマンスに直結する。

## **1.2 IoT・センシング技術の民主化**

Raspberry PiやArduino、安価なセンサーモジュールの普及により、専門的なハードウェア知識がなくても、自宅でセンサーデバイスを構築できる時代になった。ロードセル+HX711の組み合わせによる荷重計測は、体重計のDIY用途として広く知られており、関連するライブラリや情報も豊富に整備されている。

こうした民主化されたIoT技術は、生活課題を自分でハックして解決する「個人DIYデバイス」の可能性を大きく広げている。市販品では実現できない、自分の生活に最適化されたシステムを低コストで作ることが、今や現実的な選択肢となっている。

## **1.3 「睡眠の計測」から「行動の検知」へ**

従来の睡眠デバイスは、睡眠中の状態(深い眠り・浅い眠りなど)を記録・可視化するものが中心だった。しかし、真に問題なのは「睡眠の質」だけでなく、「起きるべき時間に確実に起きられるか」という起床行動そのものである。計測から一歩踏み込んだ「行動の検知と介入」へのニーズが、個人レベルでも高まってきている。

|  | 時代背景のまとめ 睡眠管理への関心の高まり × IoT技術の民主化 × 在宅勤務による自己管理の必要性 — この3つが重なり、「自分だけの起床支援デバイスをDIYで作る」ことの意義と実現可能性が、今まさに高い水準で揃っている。 |
| :---- | :---- |

# **2\. 問題 — でも、こういう問題がある**

## **2.1 アラームは「鳴る」が「起こす」ことはできない**

スマートフォンや目覚まし時計のアラームは、指定した時刻に音を鳴らすことはできる。しかし「ベッドから出たかどうか」「出た後に戻っていないか」を検知する機能は持っていない。アラームを止めた後の行動は、完全にユーザー自身の意志力に委ねられている。

## **2.2 2度寝は「意図的な行動」ではない**

多くの場合、2度寝は「もう少し寝よう」という明確な意思決定ではなく、半覚醒状態でベッドに戻り、気づいたら寝ていた、という非意図的な行動である。このため、意志力や動機付けだけでは解決しにくく、外部からのフィードバックや介入が効果的とされている。

## **2.3 既存の解決手段の限界**

| 手段 | できること | できないこと・限界 |
| ----- | ----- | ----- |
| **音アラーム(スマホ等)** | 時刻に音を鳴らす | 再入床の検知ができない。止めた後は無力 |
| **スヌーズ機能** | 複数回鳴らす | 慣れると無意識にOFFにするだけになる |
| **光目覚まし** | 自然な光で覚醒を促す | 起きた後の行動を一切追跡できない |
| **スマートウォッチ** | 睡眠状態の記録・分析 | 装着必須。再入床の検知は行わない |
| **睡眠追跡アプリ** | 睡眠サイクルの記録 | 「起きた後に戻った」を物理的に検知できない |

## **2.4 問題の本質**

|  | 検知できていないから介入できない 既存ツールはすべて「起きる前」に作用するもの(アラーム)か「起きた後の記録」にとどまるもの(ログ系)である。「一度起きたのに再びベッドに戻った」という行動を、リアルタイムで物理的に検知して介入するツールが存在しない。これが解決されていない本質的な問題である。 |
| :---- | :---- |

# **3\. 提案 — そこで、こういう方法・デバイスを提案する**

## **3.1 提案の概要**

ベッドの4本脚の下にロードセル(荷重センサー)を設置し、Raspberry Pi 4 で荷重変化をリアルタイムに監視する。アラーム後に離床を検知し、その後30分を「監視ウィンドウ」として再入床を監視。再び荷重が増加し数分継続した場合に「2度寝」と判定し、ブザーやスマホ通知で強く介入する。

|  | 提案の核心 音ではなく「荷重の物理変化」を使う。装着不要で、ベッドそのものがセンサーになる。「起きた後に戻ったかどうか」をベッドが直接検知し、自動で介入する。 |
| :---- | :---- |

## **3.2 システム全体構成**

4つのブロックで構成される。圧力変化はアナログ信号として取得し、HX711 で24ビット精度のデジタル信号に変換してから Raspberry Pi 4 で処理する。

  \[ロードセル ×4\]  ──\>  \[HX711\]  ──\>  \[Raspberry Pi 4\]  ──\>  \[ブザー / 通知\]  
                                                                             
   アナログ信号      デジタル(GPIO)     判定・状態遷移      アラート出力  
  (荷重の変化)     (24bit ADC増幅)    (Python / 状態遷移)  (ブザー+Wi-Fi)

## **3.3 判定のしくみ — 状態遷移モデル**

単純な「荷重があるか」ではなく、起床から再入床までの流れを5つの状態で追跡する。

| \# | 状態 | 日本語 | 遷移条件 |
| :---: | ----- | ----- | ----- |
| **1** | **SLEEPING** | 睡眠中 | 初期状態。ベッドに荷重が安定してある |
| **2** | **LEFT\_BED** | 離床 | 荷重が大きく減少 → 起床と判定。監視開始 |
| **3** | **AWAKE\_WINDOW** | 監視中 | 起床後30分間の監視ウィンドウ |
| **4** | **RETURNED** | 再入床 | 監視中に荷重が再び増加 |
| **5** | **2ND\_SLEEP** | 2度寝確定 | 再入床状態が3〜5分以上継続 → 通知発動 |

## **3.4 必要部品と構成コスト**

既存資産(Raspberry Pi 4 / ACアダプター / microSD / LANケーブル)を活用するため、追加購入費用を最小化できる。

| 追加購入品 | 仕様 | 価格目安 |
| ----- | ----- | ----- |
| **ロードセル4個 \+ HX711キット** | 50kgハーフブリッジ型 × 4個 | **約 1,000円** |
| **パッシブブザー** | 2度寝時のアラート音源 | **約 150円** |
| **ジャンパワイヤ・延長用導線** | AWG24〜28、はんだごて一式 | **約 900円** |
| **固定用の板 \+ 滑り止めゴム** | ロードセル上下の力均等化 | **約 500円** |
| **合計** |  | **約 2,500〜3,000円** |

### **Amazon購入リンク一覧(参考)**

以下は実際にAmazon.co.jpで購入可能な商品例。価格と在庫は変動するため、注文前に最新情報を確認すること。メイン候補と代替候補を併記しているため、在庫状況に応じて選択できる。

### **① ロードセル4個 \+ HX711キット**

| 商品名 | URL / ASIN | 価格目安 | 推奨度 |
| ----- | ----- | :---: | :---: |
| **Youmile 4pcs DIY 50KG ハーフブリッジ \+ HX711** | amazon.co.jp/dp/B084VNV4P6 | **約 750円** | **◎ メイン** |
| **Ren He HX711 \+ 4pcs 50Kg ロードセルキット** | amazon.co.jp/dp/B0BCDWB4BL | **約 800円** | ○ 代替 |
| **Load Cell Kit 4pcs 50Kg \+ HX711** | amazon.co.jp/dp/B089LS556S | **約 1,200円** | ○ 代替 |

### **② パッシブブザー(またはアクティブブザー)**

| 商品名 | 検索キーワード | 価格目安 | 推奨度 |
| ----- | ----- | :---: | :---: |
| **KKHMF パッシブブザー 5V (10個セット等)** | Amazon検索: 「ラズパイ パッシブブザー」 | **約 300円** | **◎ メイン** |
| **アクティブブザー(電源だけで鳴る簡単タイプ)** | Amazon検索: 「アクティブブザー Arduino」 | **約 200円** | ○ 簡易 |

**補足:** パッシブはPWMで音程・メロディを制御できる。アクティブは電源で「ピー」と鳴るだけだが配線がより簡単。最初はアクティブから試すのもよい。

### **③ ジャンパワイヤ・延長用導線セット**

| 商品名 | 検索キーワード | 価格目安 | 推奨度 |
| ----- | ----- | :---: | :---: |
| **ジャンパワイヤ オス-メス・オス-オス各種40本** | Amazon検索: 「ジャンパワイヤ Arduino 40本」 | **約 500円** | **◎ 必須** |
| **AWG24 ビニール被覆導線(赤・黒・白・緑)** | Amazon検索: 「AWG24 配線 4色」 | **約 600円** | **◎ 延長用** |
| **熱収縮チューブセット(各サイズ)** | Amazon検索: 「熱収縮チューブ セット」 | **約 500円** | **◎ 絶縁用** |

### **④ はんだ付け道具(初めて用意する場合)**

| 商品名 | 検索キーワード | 価格目安 | 推奨度 |
| ----- | ----- | :---: | :---: |
| **白光 はんだごて(温調機能付き 30W)** | Amazon検索: 「白光 はんだごて 温調」 | **約 1,500円** | **◎ 推奨** |
| **電子工作用はんだ φ0.8mm 鉛フリー** | Amazon検索: 「電子工作 はんだ 0.8」 | **約 800円** | **◎ 推奨** |
| **ワイヤーストリッパー** | Amazon検索: 「ワイヤーストリッパー」 | **約 1,000円** | ○ 便利 |

### **⑤ 固定用の板・滑り止めゴム**

| 商品名 | 入手先 | 価格目安 | 推奨度 |
| ----- | ----- | :---: | :---: |
| **MDF板 / アクリル板(小) ×8枚** | 100円ショップ(ダイソー・セリア) | **約 200円** | **◎ 安価** |
| **家具用滑り止めシート** | 100円ショップ or Amazon検索: 「滑り止め 家具」 | **約 300円** | **◎ 必須** |
|  | **購入時の注意事項** ①Amazonの商品ページや価格は時期により変動する。注文前に必ず最新情報を確認すること。②同じASINでも出品者により発送元・到着日が異なる。「Amazon発送」を選ぶと到着が早い。③ロードセルキットは中国発送の場合があり、到着まで2〜3週間かかることもある。研究スケジュールに余裕を持って発注すること。 |  |  |

### **おすすめの発注タイミング**

| 発注時期 | 発注内容 |
| ----- | ----- |
| **Day 1(計画書承認後即日)** | ロードセル4個キット \+ HX711(納期が長い可能性があるため最優先) |
| **Day 1〜2** | ブザー、ジャンパワイヤ、延長導線、熱収縮チューブ(まとめて発注) |
| **Day 3〜(必要に応じて)** | はんだごて一式(既に持っている場合は不要) |
| **Day 1(同日)** | 板・滑り止めゴム(100円ショップで現地調達) |

## **3.5 実装計画 — 段階的アプローチ**

いきなり完成版を目指すのではなく、試作1号(センサー1個・椅子で検証)で動作を確認してから本番構成(ベッド4個)へ拡張する。学校環境でも安全に研究でき、問題の切り分けが容易になる。

### **Phase 1: 試作1号 — 椅子を用いたセンサー1個での動作確認**

本研究は学校での研究活動として実施するため、試作1号は椅子を使って行う。椅子の脚の下に1個のロードセルを設置し、Raspberry Pi 4 と HX711 で荷重変化を取得する。「座った/立った/戻った」という動作がベッドの「乗った/降りた/戻った」と同じ原理で検知できるため、学校のどこでも安全に実験・デモが可能である。

|  | 椅子で試作する理由 ①学校環境でも設置・実験が簡単にできる。②ベッドと同じ「座る/立つ/戻る」の荷重変化パターンを再現できる。③配線・HX711動作・ノイズの問題を切り分けるのに十分な環境。④1個構成で確認後、ベッド4個構成へ知識をそのまま転用できる。 |
| :---- | :---- |

| 確認項目 | 合格基準 |
| ----- | ----- |
| **Raspberry Pi 4 \+ HX711から値が読める** | Pythonコードで荷重値が毎秒出力される |
| **座った/立ったが検知できる** | 値が明確に増減し、着座/離席に追従する |
| **キャリブレーションが通る** | 体重が±数kg以内で表示される |
| **再着席の検知ができる** | 離席後に戻った際、荷重変化として捉えられる |
| **CSVログが保存される** | 授業1コマ分(90分)のログが途切れず保存される |

### **Phase 2: 本番構成 — ベッド4個で精度向上**

自宅のベッド4本脚にロードセルを設置し、フルブリッジ接続へ拡張。総荷重+荷重偏りを取得することで「腰掛けただけ」と「横になった」を区別できるようになる。

* 4個のハーフブリッジをフルブリッジに合成して接続

* キャリブレーションを再実施(総荷重が変わるため)

* 状態遷移コードと2度寝判定ロジックを実装

* ブザーとWi-Fi通知(Discord/LINE)を接続

### **Phase 3(任意): AIによる個人最適化**

1〜2週間のログを収集後、ラベル付けして軽量分類モデル(ロジスティック回帰・ランダムフォレスト等)を学習。誤検知をさらに減らし、個人の行動パターンに最適化する。詳細は第5章参照。

## **3.6 延長配線の実作業 — はんだ付けによる1m延長**

ロードセルの付属ケーブルは約20〜25cmしかなく、ベッド中央のHX711まで届かない。普通の導線(ビニール被覆付き)を購入し、はんだ付けで延長する。

### **材料**

* 導線: ビニール被覆付き AWG28〜24、1m×4本(赤・黒・白・緑の4色推奨)

* はんだごて: 20〜40W(温調機能付きが理想)

* はんだ: 電子工作用 φ0.8〜1.0mm

* 熱収縮チューブ: 内径2〜3mm(絶縁テープで代用可)

* ワイヤーストリッパー(カッター代用可)

### **手順(1本の線を延長、4本繰り返す)**

5. ロードセルの既存線の先端1cmの被覆を剥く

6. 延長導線も先端1cmを剥く

7. 先に熱収縮チューブを延長導線に通しておく(後では通せない)

8. 2本の芯線を重ねて指でしっかりねじり合わせる

9. はんだごてで温め、はんだを流し込む(線が温まってからはんだを当てる)

10. 熱収縮チューブを接続部分に移動させ、ライターで収縮・絶縁する

11. 残り3本でも同じ手順を繰り返す

### **ノイズ対策: ツイスト処理**

  \[赤\] \+ \[黒\] → 2本をペアにして軽くねじる  
  \[白\] \+ \[緑\] → 2本をペアにして軽くねじる  
  さらに2ペアをねじり合わせるとより効果的(任意)

|  | はんだ付けのコツ 「はんだごてを当てる → 線が温まる → はんだを当てる」の順番が正しい。いきなりはんだをこてに付けても流れない。芯線が十分温まってからはんだを当てるとスムーズに染み込む。 |
| :---- | :---- |
|  | **失敗しやすいポイントと対処** ①はんだが玉になって乗っているだけ(冷えはんだ)→ 再加熱して溶かし直す。②線がショート → テープで絶縁し直す。③値がゼロのまま → どこかで断線。テスターで各線を導通チェック。 |

## **3.7 キャリブレーション手順**

ロードセルの生の値を実際の重さ(kg)に変換するための必須作業。飛ばすと判定ロジックが動作しない。

| Step | 作業 | 内容 | ポイント |
| :---: | ----- | ----- | ----- |
| **01** | **ライブラリ導入** | pip install hx711 | \--break-system-packages オプションが必要 |
| **02** | **ベッドを完全状態に** | マットレス・布団・枕を全部載せる | 寝具の重さを初期値に含める |
| **03** | **ゼロ点測定** | 30回読み → 中央値を記録 | 外れ値に強い中央値を使う |
| **04** | **既知重量を載せる** | 2Lペットボトル×4本 \= 8kg | 重さは事前に体重計で確認 |
| **05** | **スケール係数算出** | (値 − ゼロ点) ÷ 重量\[kg\] | 複数重量で確認すると精度UP |
| **06** | **config.py に保存** | ZERO\_OFFSET と SCALE\_FACTOR | 起動5分後に実施(温度ドリフト回避) |

# **4\. 結果 — こういうことができる**

## **4.1 実現できること**

本システムを構築・運用することで、以下が実現できる。特に「物理的な再入床の検知」は、既存のどのツールも提供していない機能である。

| 実現できること | 詳細 |
| ----- | ----- |
| **再入床をリアルタイムで検知** | 「起床後に再びベッドに戻った」を物理的に、装着なしで自動検知する |
| **2度寝に段階的に介入** | ブザー → スマホ通知 → Discord/LINE と段階的に通知を強化する |
| **荷重ログの蓄積** | CSVで毎秒の荷重データを記録。自分の起床パターンを可視化できる |
| **「座っただけ」との誤検知抑制** | 4個構成の荷重偏りと継続時間の組み合わせで誤判定を大幅に削減 |
| **低コスト・装着ゼロ** | 追加コスト約3,000円。ベッドに乗るだけで自動計測が始まる |

## **4.2 システム動作の流れ(具体例)**

毎朝の動作イメージは以下の通り。

07:00  アラームが鳴る  
07:02  荷重が急減 → 「起床」と判定。30分間の監視ウィンドウ開始  
07:08  トイレから戻りベッドに腰掛ける → 荷重増加を検知  
07:08  30秒後に立ち上がる → 「一時的な腰掛け」と判断。リセット  
07:15  再びベッドに横になる → 荷重増加・継続を検知  
07:18  3分継続 → 「2度寝」確定  
07:18  ブザー再鳴動 \+ スマホ通知「2度寝を検知しました」

## **4.3 1個構成(試作)と4個構成(完成)の比較**

| 比較項目 | 1個構成(試作) | 4個構成(完成) |
| ----- | ----- | ----- |
| **導入コスト** | 最小(キット1セットで開始) | 同等(同キットをそのまま活用) |
| **設置の難しさ** | 簡単(1脚に挟むだけ) | やや手間(4脚 \+ 配線合成) |
| **離床・再入床の検知** | ○ 大まかに検知できる | ◎ 高精度に検知できる |
| **誤検知の多さ** | 多め(腰掛けで反応することあり) | 少ない(偏りで区別できる) |
| **用途** | 動作確認・閾値調整 | 実用運用 |

## **4.4 コスト効果**

既存のスマートホームデバイスや睡眠トラッカーと比較すると、本システムの追加コストは約3,000円と極めて低い。しかも「再入床の検知」という機能は市販品では提供されていないものであり、コストパフォーマンスは圧倒的に高い。

| デバイス/手段 | コスト目安 | 再入床検知 |
| ----- | ----- | ----- |
| **本システム(Piは既存)** | **約3,000円** | ◎ あり(本システム固有の機能) |
| **スマートウォッチ(Apple Watch等)** | 30,000〜80,000円 | × なし(睡眠記録のみ) |
| **スマートベッドマット** | 10,000〜50,000円 | △ 製品による(判定は不明確) |
| **スマホのアラームのみ** | 0円 | × なし |

# **5\. 今後 — こういう展開があり得る、もっとこういうことができる**

## **5.1 AIによる個人最適化 — ルールベースの先へ**

Phase 1〜4のルールベース実装が安定稼働し始めたら、蓄積されたログデータを使って機械学習モデルを構築することができる。これにより、固定の閾値では対応しきれない「個人差」や「状況の違い」を吸収し、2度寝判定の精度を大幅に向上させることができる。

### **なぜAIが必要か — ルールベースの限界**

ルールベース判定は「荷重が閾値を超えてX分継続したら2度寝」という固定条件で動く。これは汎用的だが、以下のような状況で誤検知・見逃しが発生しやすい。

| 状況 | ルールベースの反応 | 本来の正解 |
| ----- | ----- | ----- |
| 布団の上に荷物を置いた | 2度寝と誤判定することがある | 2度寝ではない |
| 体が小さく荷重が軽い | 閾値を超えずに見逃す場合がある | 再入床として検知すべき |
| ベッドの端に座っただけ | 横になったと誤判定する場合がある | 2度寝ではない |
| 休日の朝は条件を変えたい | 固定条件のため対応できない | 曜日・状況に応じて柔軟に判定したい |

### **AIで使う特徴量(入力データ)**

ロードセル4個から毎秒記録されるログには以下の豊富な特徴量が含まれる。これらをモデルの入力として使う。

| 特徴量 | 説明と意味 |
| ----- | ----- |
| **総荷重** | 4個の合計値。「重い \= 人が横になっている」の基本指標 |
| **荷重の偏り(左右・前後)** | 4点の差分。横になると均等、腰掛けると前側に偏る。姿勢の区別に有効 |
| **荷重変化の速さ** | 急増=飛び乗った、緩増=ゆっくり横になった。行動の種類を区別できる |
| **継続時間** | 一定以上の荷重が何分続いているか。短ければ腰掛け、長ければ就寝の可能性 |
| **時刻** | アラーム後7時10分か8時かで文脈が違う。同じ荷重でも意味が変わる |
| **アラームからの経過時間** | 起床直後(5分以内)の再入床は危険度が高い。時間が経つほどリスク低下 |
| **過去7日間のパターン** | 「この人は月曜日に2度寝しやすい」などの個人クセを学習できる |

### **ラベル付け — 教師データの作り方**

機械学習には「正解データ(教師データ)」が必要。1〜2週間のログを実際の行動と照らし合わせて以下の4クラスのラベルを付ける。

* sleeping: ベッドで睡眠中(安定した荷重)

* sitting: 端に腰掛けた(荷重が短時間・偏りあり)

* left\_bed: ベッドから離れた(荷重の急減)

* second\_sleep: 2度寝(再入床後に荷重が数分継続)

ラベル付けは手動で行う。CSVログを見ながら「この時間帯は腰掛けただけ」などを記録する。数時間分から始めても十分なデータになる。

### **使用するモデルとその特徴**

Raspberry Pi 4 のスペックでリアルタイム推論が動くよう、軽量なモデルを使う。

| モデル | 特徴 | 本システムでの役割 |
| ----- | ----- | ----- |
| **ロジスティック回帰** | 非常に軽量・解釈しやすい | まず最初に試す。特徴量の重要度が数字で見える |
| **決定木** | ルールが可視化できる | 「なぜ2度寝と判定したか」を人間が確認・説明できる |
| **ランダムフォレスト** | 精度が高い・過学習しにくい | ロジスティック回帰より精度を上げたい段階で使う |
| **XGBoost / LightGBM** | 精度が非常に高い | データが十分蓄積された後の最終精度向上に使う |

### **学習〜推論の流れ(Pythonコード例)**

\# step1\_features.py — 特徴量を作る  
import pandas as pd  
df \= pd.read\_csv('bed\_log.csv')

df\['total\_weight'\]   \= df\[\['lc1','lc2','lc3','lc4'\]\].sum(axis=1)  
df\['diff\_lr'\] \= (df\['lc1'\]+df\['lc2'\]) \- (df\['lc3'\]+df\['lc4'\])  \# 左右差  
df\['diff\_fb'\] \= (df\['lc1'\]+df\['lc3'\]) \- (df\['lc2'\]+df\['lc4'\])  \# 前後差  
df\['delta'\]   \= df\['total\_weight'\].diff().abs()                  \# 変化量  
df\['hour'\]    \= pd.to\_datetime(df\['timestamp'\]).dt.hour

\# step2\_train.py — モデルを学習  
from sklearn.ensemble import RandomForestClassifier  
from sklearn.model\_selection import cross\_val\_score  
import joblib

labels \= pd.read\_csv('labels.csv')  
X \= df\[\['total\_weight','diff\_lr','diff\_fb','delta','hour'\]\]  
y \= labels\['label'\]

model \= RandomForestClassifier(n\_estimators=100, random\_state=42)  
scores \= cross\_val\_score(model, X, y, cv=5)  \# 5分割交差検証  
print(f'精度: {scores.mean():.2f} (±{scores.std():.2f})')

model.fit(X, y)  
joblib.dump(model, 'sleep\_model.pkl')

\# step3\_predict.py — Pi 4でリアルタイム推論  
model \= joblib.load('sleep\_model.pkl')  
features \= \[total\_w, diff\_lr, diff\_fb, delta, hour\]  
label \= model.predict(\[features\])\[0\]  
\# → 'second\_sleep' なら通知発動

### **精度評価の指標**

「正確さ(Accuracy)」だけでなく、誤検知(False Positive)と見逃し(False Negative)をバランスよく評価するF1スコアを主指標として使う。

| 指標 | 意味 | 目標値 |
| ----- | ----- | ----- |
| **Accuracy(正確率)** | 全判定のうち正解した割合 | 90%以上 |
| **Precision(適合率)** | 「2度寝」と判定したうち実際に2度寝だった割合 | 誤通知を減らしたい場合に重視 |
| **Recall(再現率)** | 実際の2度寝のうち検知できた割合 | 見逃しを減らしたい場合に重視 |
| **F1スコア** | PrecisionとRecallの調和平均 | 0.85以上を目標(主指標) |
|  | **研究テーマとしてのAI活用** 「ルールベース vs 機械学習モデル vs LLM補助」の3段階比較はそのまま研究の評価軸になる。誤検知率・見逃し率・F1スコアをKPIとして計測し、各アプローチの優劣を定量的に示せると、研究発表として非常に説得力がある。 |  |

## **5.2 LLMの活用 — MLと組み合わせた高度な判断・対話**

機械学習モデルによる数値分類に加えて、LLM(大規模言語モデル)を組み合わせることで、「なぜそう判定したか」の説明生成や、ログデータの自然言語での解釈・対話が可能になる。実現方法は大きく2つに分かれる。

| LLMの役割 | できること | MLとの違い |
| ----- | ----- | ----- |
| **判定理由の説明生成** | 「7:15に離床後、7:22に再入床し5分継続。2度寝と判定」のような自然文を生成 | MLは0/1の分類のみ。LLMは根拠を言葉にできる |
| **ログの傾向分析** | 「先週の起床ログを分析して傾向を教えて」に自然言語で答える | グラフ不要。会話形式で洞察が得られる |
| **曖昧なケースの補助判断** | MLが迷ったケース(確信度50〜60%)をLLMに文脈つきで問い合わせ | MLは数値しか見ないが、LLMは時刻・曜日・状況の文脈を考慮できる |
| **研究考察の補助** | 実験結果のCSVをLLMに渡して「考察を日本語で書いて」と依頼 | 論文・発表資料の考察文作成を補助 |

### **方法A: ローカルLLM — Ollama \+ Gemma 4**

Wi-Fiなしで動作し、ログデータを外部に送らないため、プライバシーを守りながら研究できる。Raspberry Pi 4単体では処理が重いため、PC側でOllamaを動かしてAPIとして呼び出すのが現実的。

### **セットアップ手順(PC側)**

\# 1\. Ollamaをインストール(Mac/Linux/Windows対応)  
\# https://ollama.com からインストーラをダウンロード

\# 2\. Gemma 4モデルをダウンロード  
ollama pull gemma4

\# 3\. APIサーバーとして起動(デフォルトでlocalhost:11434)  
ollama serve

### **Raspberry Pi 4 からの呼び出しコード**

\# llm\_local.py — OllamaのGemma 4をRaspberry Pi 4から呼び出す  
import requests, json

OLLAMA\_URL \= 'http://\[PCのIPアドレス\]:11434/api/generate'

def ask\_gemma(prompt: str) \-\> str:  
    res \= requests.post(OLLAMA\_URL, json={  
        'model': 'gemma4',  
        'prompt': prompt,  
        'stream': False  
    })  
    return res.json()\['response'\]

\# 使用例: 2度寝判定の説明を生成  
def explain\_detection(wake\_time, return\_time, duration\_min):  
    prompt \= f"""  
    以下の荷重センサーのデータを解釈してください。  
    \- 起床時刻: {wake\_time}  
    \- 再入床時刻: {return\_time}  
    \- 再入床の継続時間: {duration\_min}分  
    2度寝と判定した理由を1〜2文で簡潔に説明してください。  
    """  
    return ask\_gemma(prompt)

\# 使用例: ログの傾向分析  
def analyze\_log\_summary(csv\_summary: str):  
    prompt \= f"以下は1週間の起床ログの集計です。傾向と改善点を分析してください。\\n{csv\_summary}"  
    return ask\_gemma(prompt)

| 項目 | 内容 | 備考 |
| ----- | ----- | ----- |
| **モデル** | Gemma 4(Google製オープンウェイトモデル) | 日本語対応・軽量で高性能 |
| **実行環境** | PC上でOllamaを動かし、Pi 4からHTTPで呼び出す | Pi 4単体では推論が重いため推奨構成 |
| **通信** | ローカルネットワーク内(Wi-Fi経由) | インターネット不要。データは外部に出ない |
| **コスト** | 無料(モデルのダウンロードのみ) | APIコスト一切なし |

### **方法B: クラウドAPI — OpenAI GPT-4o**

セットアップが最も簡単で、日本語の精度も非常に高い。インターネット接続とAPIキーが必要で、利用量に応じた課金が発生する。ログデータをOpenAIのサーバーに送信するため、研究倫理・プライバシーの観点を事前に確認すること。

\# llm\_openai.py — OpenAI APIをRaspberry Pi 4から呼び出す  
\# pip install openai \--break-system-packages  
from openai import OpenAI

client \= OpenAI(api\_key='YOUR\_API\_KEY')  \# 環境変数推奨

def ask\_gpt(system\_prompt: str, user\_message: str) \-\> str:  
    res \= client.chat.completions.create(  
        model='gpt-4o',  
        messages=\[  
            {'role': 'system', 'content': system\_prompt},  
            {'role': 'user',   'content': user\_message},  
        \]  
    )  
    return res.choices\[0\].message.content

\# 使用例: 2度寝判定の説明生成  
system \= '荷重センサーによる睡眠行動検知システムのアシスタントです。簡潔に説明してください。'  
user   \= f'起床後22分で再入床し、5分継続しました。判定理由を1文で説明してください。'  
print(ask\_gpt(system, user))

\# 使用例: 週次ログの傾向分析  
csv\_text \= open('weekly\_summary.csv').read()  
analysis \= ask\_gpt(  
    '睡眠研究のデータアナリストです。',  
    f'以下の起床ログを分析し、2度寝しやすい傾向と改善案を述べてください。\\n{csv\_text}'  
)  
print(analysis)

| 項目 | 内容 | 備考 |
| ----- | ----- | ----- |
| **モデル** | GPT-4o(OpenAI) | 日本語精度・推論能力が非常に高い |
| **実行環境** | Pi 4からWi-Fi経由でOpenAI APIを呼び出す | セットアップが最も簡単 |
| **通信** | インターネット必須。データはOpenAIサーバーに送信 | プライバシー面を研究前に確認すること |
| **コスト** | 従量課金(GPT-4o: 約$2.5/1M tokens入力) | 研究用途なら月数百円程度 |

### **2つの方法の比較**

| 比較項目 | 方法A: Ollama \+ Gemma 4 | 方法B: OpenAI GPT-4o |
| ----- | ----- | ----- |
| **セットアップの手軽さ** | PC側の準備が必要 | ◎ APIキー取得のみでOK |
| **日本語の精度** | ○ 良好 | ◎ 非常に高い |
| **コスト** | ◎ 完全無料 | 従量課金(少額) |
| **プライバシー** | ◎ データが外部に出ない | データがOpenAIに送信される |
| **インターネット不要** | ◎ ローカルで完結 | × 必須 |
| **推論速度** | PCスペックに依存 | ◎ クラウドで高速 |
| **研究推奨度** | ◎ プライバシー重視の研究向き | ○ 手軽に始めたい場合向き |
|  | **研究としての推奨アプローチ** 学校研究ではまずOllama \+ Gemma 4(方法A)から始めることを推奨する。データが外部に出ないため研究倫理上の問題が少なく、コストもかからない。精度比較が必要な場面ではOpenAI APIを使い、「ローカルLLM vs クラウドLLM」の差も評価軸にすると研究の深みが増す。 |  |

## **5.3 センサーの拡張**

圧力センサーに加えて、補助センサーを追加することで判定精度をさらに高められる。

| センサー | 取得できる情報 | 2度寝判定への貢献 |
| ----- | ----- | ----- |
| **人感センサー(PIR)** | 部屋内に人がいるか | 「歩き回っている \= 起きている」として2度寝リスクを下げる |
| **ドア開閉センサー** | 部屋を出たかどうか | 「部屋を出た \= 起床確定」として監視を解除できる |
| **カメラ(Camera Module)** | 姿勢・体の向き | 「横になった姿勢」を視覚的に確認。誤検知を最小化 |
| **マイク(音声検知)** | 声・アラーム音 | 「声を出している \= 起きている」として状態を補正 |

## **5.4 通知・介入の強化**

現在の「ブザー \+ スマホ通知」から、より強力な介入手段へ発展できる。

* スマートライト連携: 2度寝検知時に自動で照明を最大輝度に点灯

* スマートスピーカー連携: 「2度寝を検知しました、起きてください」と音声アナウンス

* 家族・同居人への通知: LINE/Discordで家族のスマホにも通知

* 段階的エスカレーション: 5分後に再確認し、まだ寝ていたら音量を上げる

## **5.5 データ活用・可視化**

蓄積されたログから、自分の睡眠・起床行動を分析・可視化できる。

* 起床成功率のグラフ化(週単位・月単位)

* 2度寝した曜日・時刻のパターン分析

* 季節による起床行動の変化

* WebダッシュボードやGrafana等で可視化

## **5.6 製品化・外部展開の可能性**

本システムはDIYデバイスとして始まるが、その機能自体には市場的な独自性がある。「再入床検知」という機能は既存の睡眠デバイスには存在せず、需要も潜在的に高い。

* OSSとして公開 → 類似ニーズを持つコミュニティへの貢献

* 基板設計のコンパクト化 → Raspberry Pi Zero 2W \+ 専用基板でワンボード化

* クラウドとの連携 → 複数ユーザーのデータを活用した汎用モデルの学習

* 睡眠改善コーチングアプリとの統合 → 「再入床のパターン」をコーチに共有

## **5.7 ロードマップ全体像**

| Phase | 名称 | 期間目安 | 主な成果物 |
| :---: | ----- | ----- | ----- |
| **1** | **試作1号(センサー1個)** | 1〜2日 | 荷重取得・CSVログ動作確認 |
| **2** | **ルールベース2度寝判定** | 2〜3日 | 状態遷移コード \+ ブザー通知 |
| **3** | **4個構成に拡張** | 2〜3日 | 総荷重 \+ 荷重偏り \+ 精度向上 |
| **4** | **通知強化** | 2〜3日 | Discord/LINE連携・段階通知 |
| **5** | **AI個人最適化(任意)** | 1〜2週間 | 分類モデル \+ 誤検知削減 |
| **6+** | **センサー拡張・可視化・OSSへ** | 随時 | カメラ・スマートライト・ダッシュボード等 |

|  | 最終メッセージ 「AIを作る」ことに先に飛びつくと詰まりやすい。まず圧力センシングと状態遷移を確実に動かし、その上に段階的に機能を積み上げていくのが最短ルート。シンプルに、1つずつ。 |
| :---- | :---- |

# **付録: 実装リファレンス**

## **A. 配線表**

### **4個ロードセル → HX711(フルブリッジ接続)**

| HX711側 | 線色(一般) | 接続先ロードセル |
| :---: | :---: | ----- |
| **E+** | 赤 | ロードセル 1 \+ ロードセル 2 |
| **E−** | 黒 | ロードセル 3 \+ ロードセル 4 |
| **A+** | 白 | ロードセル 1 \+ ロードセル 3 |
| **A−** | 緑 | ロードセル 2 \+ ロードセル 4 |

### **HX711 → Raspberry Pi**

| HX711ピン | Raspberry Piピン | 説明 |
| :---: | :---: | ----- |
| **VCC** | 3.3V (Pin 1\) | 電源 |
| **GND** | GND (Pin 6\) | グランド |
| **DT** | GPIO5 (Pin 29\) | データ出力 |
| **SCK** | GPIO6 (Pin 31\) | クロック |

## **B. 最小動作コード(試作1号)**

\# prototype\_v1.py — 試作1号: 荷重取得 \+ CSVログ  
from hx711 import HX711  
import time, csv, statistics  
from datetime import datetime  
from config import ZERO\_OFFSET, SCALE\_FACTOR

hx \= HX711(dout\_pin=5, pd\_sck\_pin=6)  
hx.reset()

with open('/home/pi/bed\_log.csv', 'a', newline='') as f:  
    writer \= csv.writer(f)  
    writer.writerow(\['timestamp', 'raw', 'weight\_kg'\])  
    while True:  
        raw    \= hx.get\_raw\_data\_mean(readings=10)  
        weight \= (raw \- ZERO\_OFFSET) / SCALE\_FACTOR  
        ts     \= datetime.now().isoformat()  
        writer.writerow(\[ts, raw, f'{weight:.2f}'\])  
        f.flush()  
        print(f'{ts}  {weight:.2f}kg')  
        time.sleep(1)

## **C. 2度寝判定コード(疑似コード)**

state \= 'SLEEPING'  
wake\_time \= return\_start \= None

EXIT\_THRESH    \= 0.3   \# 体重の30%を下回ったら離床  
RETURN\_THRESH  \= 0.4   \# 体重の40%を超えたら再入床  
MONITOR\_SEC    \= 1800  \# 起床後30分監視  
CONFIRM\_SEC    \= 180   \# 3分継続で2度寝確定

while True:  
    weight \= get\_weight()   \# 正規化済み(体重比)  
    now \= time.time()

    if state \== 'SLEEPING' and weight \< EXIT\_THRESH:  
        wake\_time \= now  
        state \= 'AWAKE\_WINDOW'

    elif state \== 'AWAKE\_WINDOW':  
        if now \- wake\_time \> MONITOR\_SEC:  
            state \= 'DONE'  
        elif weight \> RETURN\_THRESH:  
            return\_start \= now  
            state \= 'RETURNED'

    elif state \== 'RETURNED':  
        if weight \< RETURN\_THRESH:  
            state \= 'AWAKE\_WINDOW'  
        elif now \- return\_start \> CONFIRM\_SEC:  
            trigger\_buzzer()  
            send\_notification()  
            state \= '2ND\_SLEEP'

## **D. 実装前チェックリスト**

### **ハードウェア**

* □  Raspberry Pi 4 \+ ACアダプター \+ microSDが手元にある

* □  ロードセル4個キット(+HX711)を購入済み

* □  延長用導線・はんだごて・はんだ・熱収縮チューブを用意した

* □  固定用の板・滑り止めゴムを用意した

### **ソフトウェア**

* □  Raspberry Pi 4 に Raspberry Pi OS Bookwormをインストール済み

* □  Python3 \+ pip が動作する

* □  hx711 ライブラリをインストール済み

* □  Wi-Fiに接続できる(通知用)

### **キャリブレーション**

* □  ゼロ点測定済み(config.py に ZERO\_OFFSET を保存)

* □  スケール係数測定済み(config.py に SCALE\_FACTOR を保存)

* □  自分の体重で±数kg以内を確認済み

# **付録E: 用語集**

本計画書で使用される技術用語の定義を記載する。

| 用語 | 意味 |
| ----- | ----- |
| **ロードセル** | 荷重を電気信号(微弱電圧)に変換するセンサー。本研究では50kg対応のハーフブリッジ型を使用 |
| **HX711** | ロードセル専用の24ビットADC(アナログ・デジタル変換)モジュール。微弱信号を増幅してデジタル化する |
| **ハーフブリッジ / フルブリッジ** | ロードセルの内部回路構成。ハーフブリッジ4個を組み合わせて1つのフルブリッジを構成すると総荷重と偏りが取得できる |
| **Raspberry Pi 4** | 英Raspberry Pi財団製の小型コンピュータ。GPIO経由でセンサーと接続でき、Pythonで制御できる |
| **GPIO** | General-Purpose Input/Output。Raspberry Piの汎用入出力ピン。デジタル信号の送受信に使う |
| **キャリブレーション** | センサーの生の値を実際の物理量(kg)に変換するための較正作業。ゼロ点とスケール係数を測定する |
| **状態遷移モデル** | システムの状態を定義し、条件に応じて状態を遷移させる設計手法。本研究ではSLEEPING〜2ND\_SLEEPの5状態 |
| **ルールベース** | 「もしXがY超えたらZ」のような固定条件で判定する手法。学習不要で軽量だが柔軟性は低い |
| **機械学習(ML)** | データから自動的にパターンを学習する技術。本研究ではロジスティック回帰・ランダムフォレスト等を使用 |
| **LLM** | Large Language Model(大規模言語モデル)。Gemma 4・GPT-4oなど。自然言語の生成・理解が可能 |
| **Ollama** | LLMをローカル環境で簡単に実行できるオープンソースツール。CPU/GPUどちらでも動作可能 |
| **特徴量** | 機械学習モデルへの入力データ。本研究では総荷重・荷重偏り・継続時間・時刻などを使用 |
| **F1スコア** | Precision(適合率)とRecall(再現率)の調和平均。0〜1の範囲で1に近いほど高精度 |
| **ツイストペア** | 2本の電線を撚り合わせた配線。差動ノイズを相殺できるためアナログ信号の長距離配線に有効 |
| **Webhook** | 特定のイベント発生時に外部URLへ自動的にHTTPリクエストを送る仕組み。Discord/LINE通知に使用 |

# **付録F: 参考資料・関連リンク**

本計画書の作成・実装にあたって参考となる公式ドキュメント・ライブラリ・関連情報を記載する。

## **F.1 ハードウェア関連**

| リソース | 説明・URL |
| ----- | ----- |
| **Raspberry Pi 公式ドキュメント** | セットアップ・GPIO仕様・OSインストール手順 — raspberrypi.com/documentation |
| **HX711 データシート** | AVIA Semiconductor社の公式仕様書。ピン配列・通信プロトコル |
| **ロードセルの選び方** | SparkFun・Adafruit・秋月電子の解説記事を参照 |
| **Amazon部品購入リスト** | 第3.4節を参照(Amazon.co.jp の商品ASIN付きで記載) |
| **秋月電子通商(代替購入先)** | akizukidenshi.com — Amazonにない部品はここで入手可能 |
| **スイッチサイエンス(代替購入先)** | switch-science.com — Raspberry Pi本体・SparkFun製品の正規代理 |

## **F.2 ソフトウェア・ライブラリ**

| ライブラリ | 用途・取得先 |
| ----- | ----- |
| **hx711 (Python)** | PyPI: pip install hx711 — HX711とPi間のデータ取得 |
| **RPi.GPIO / gpiozero** | Raspberry Pi の GPIO制御。Bookworm標準対応 |
| **scikit-learn** | Phase 5(機械学習)で使用 — pip install scikit-learn |
| **pandas** | CSVログ処理・特徴量作成 — pip install pandas |
| **Ollama** | ローカルLLMランタイム — ollama.com |
| **openai (Python)** | OpenAI API公式SDK — pip install openai |

## **F.3 機械学習・LLM関連の学習リソース**

* scikit-learn 公式チュートリアル(分類問題の基礎)

* Kaggle Learn(無料の機械学習・特徴量エンジニアリング講座)

* Google Gemma 公式ページ — オープンウェイトLLMの仕様

* OpenAI Platform Documentation — APIリファレンスとプロンプト設計

## **F.4 関連研究・先行事例**

* 睡眠ステージ推定研究(ベッドセンサー型) — 医療機関の論文を参照

* DIY体重計プロジェクト(Hackster.io / Instructables)

* Raspberry Pi コミュニティのIoT活用事例

## **F.5 安全・倫理に関する留意事項**

|  | 研究実施上の注意 本システムは個人の睡眠データを扱う。ログデータの取り扱い、特にOpenAI API等のクラウドサービスを使用する場合は、データの送信先・保存ポリシーを事前に確認すること。他者のデータを扱う場合は、所属機関の研究倫理規程に従うこと。 |
| :---- | :---- |

*本文書はRaspberry Pi 4 × Load Cell Project の研究開発計画書です。*

*以上*

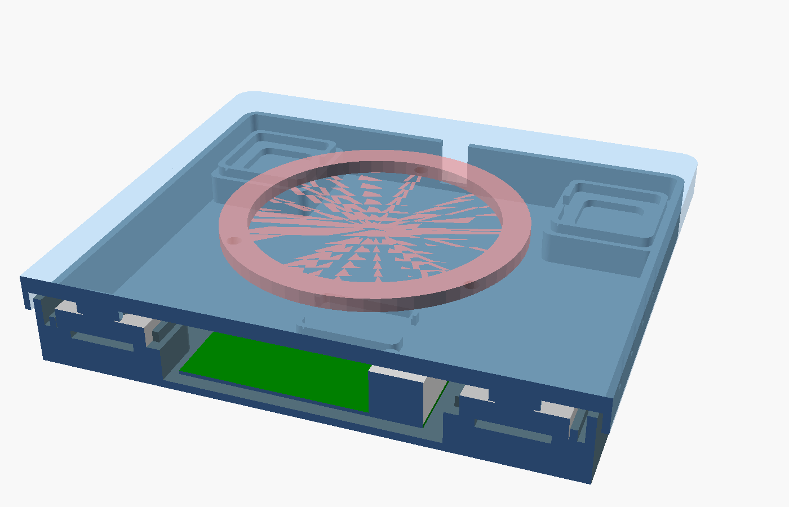
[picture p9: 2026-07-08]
hardware/case/img/section_iso.png

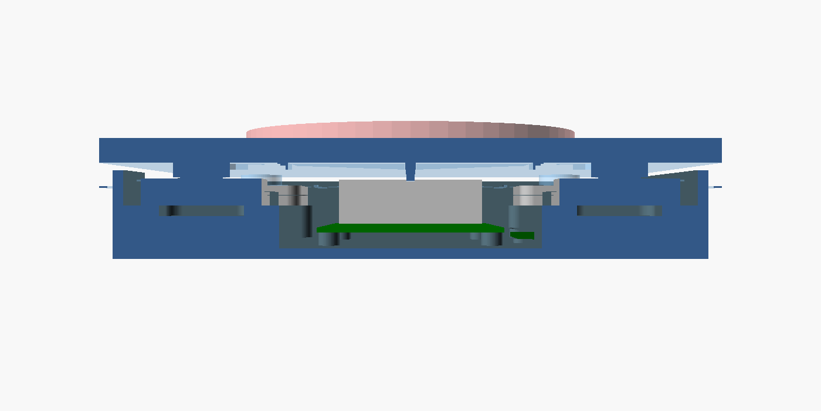
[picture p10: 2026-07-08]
hardware/case/img/section_front.png

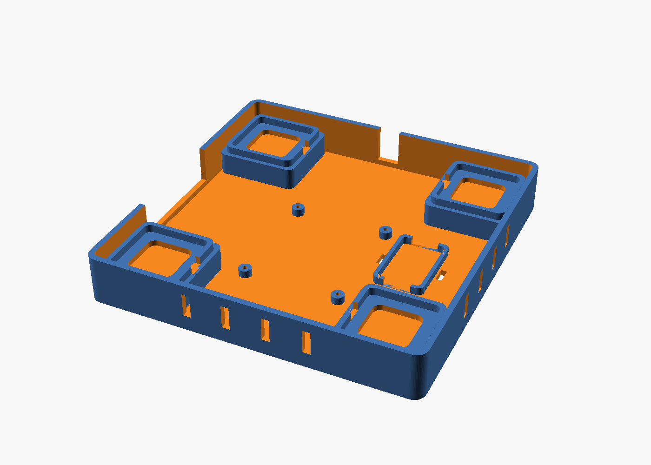
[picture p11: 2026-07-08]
hardware/case/img/base_iso.png

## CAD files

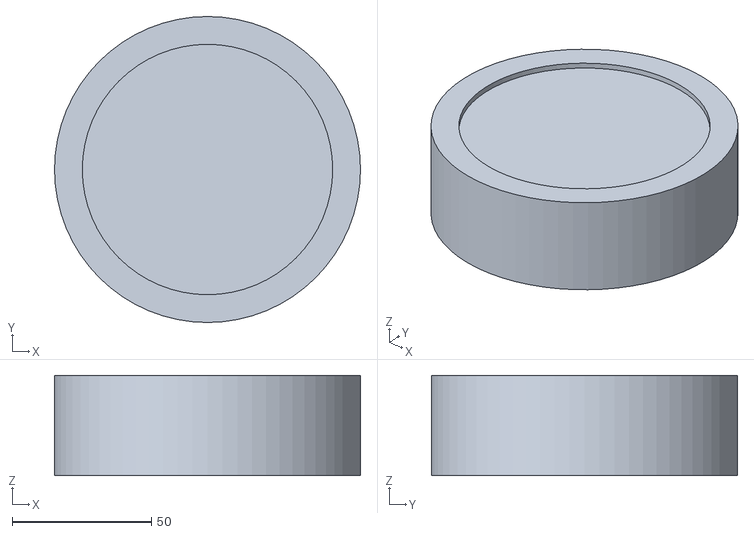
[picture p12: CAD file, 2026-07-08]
hardware/case/stl/leg_spacer.stl
110.0 x 110.0 x 36.0

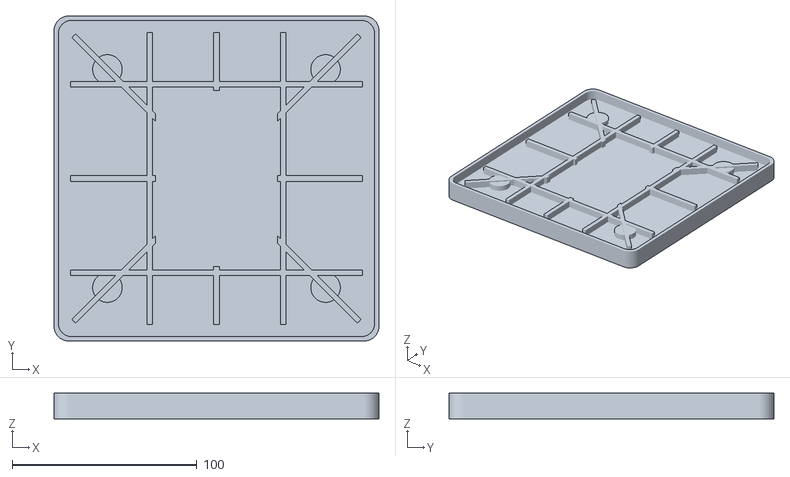
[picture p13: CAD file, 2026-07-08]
hardware/case/stl/top_plate.stl
175.8 x 175.8 x 14.0

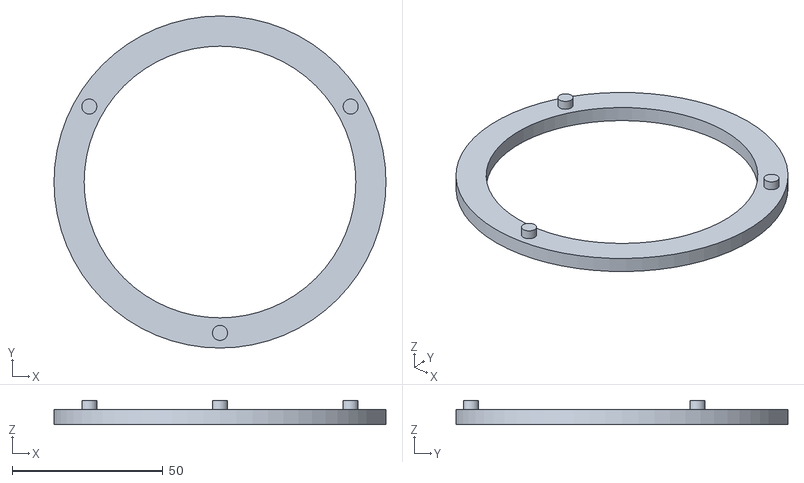
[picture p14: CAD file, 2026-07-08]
hardware/case/stl/leg_ring.stl
110.0 x 110.0 x 8.00

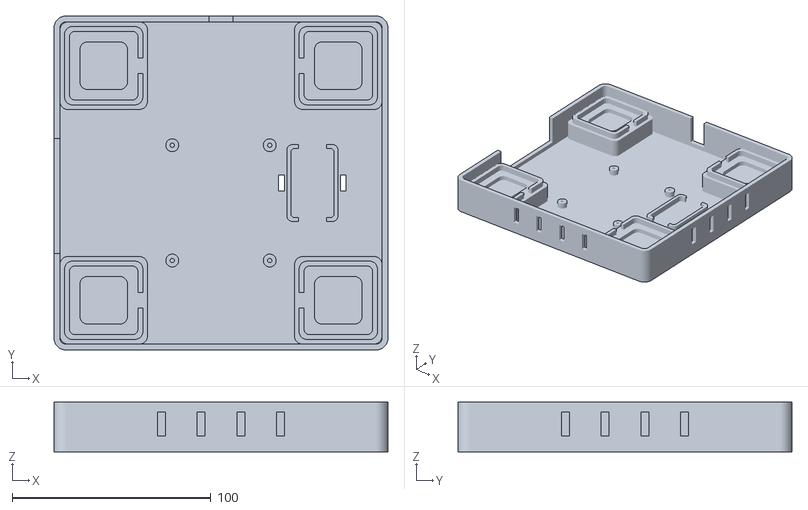
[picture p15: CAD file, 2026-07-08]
hardware/case/stl/base_plate.stl
168.0 x 168.0 x 25.0

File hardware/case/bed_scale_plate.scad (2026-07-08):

/*
 * bed_scale_plate.scad — 2dosumi ベッド下スケールプレート
 *
 * Raspberry Pi 4 + HX711 + 50kg半橋ロードセル×4 を内蔵する
 * 体重計型の一体プレート。ベッドの脚1本の下に敷いて使う。
 *
 * 構成パーツ (part 変数で切替):
 *   base     — 下皿。ロードセル4個・Pi 4・HX711 を搭載
 *   top      — 上蓋。四隅のロードセルのボタン4点だけに接触して浮く
 *   ring     — 脚受けリング。上蓋の天面にピンで固定(φ80mmまでの脚に対応)
 *   spacer   — 残り3本の脚用の同高スペーサー(3個印刷)
 *   assembly — 組立状態の確認用ビュー(印刷しない)
 *
 * 荷重経路: ベッドの脚 → 上蓋 → ボス×4 → ロードセルのボタン → ペデスタル → 床
 * 上蓋はベースの壁・Pi・HX711 のどこにも触れない(スカートは横ズレ防止のみ)。
 */

/* [部品選択] */
part = "assembly"; // [assembly, base, top, ring, spacer]

/* [全体寸法] */
base_outer = 168;   // ベース外形(一辺)。Bambu A1 mini (180角) 対応。上蓋は+7.8mm大きくなる
wall_t     = 3;     // 外壁厚
floor_t    = 3;     // 床厚
wall_h     = 25;    // 外壁高さ
corner_r   = 6;     // 外形コーナーR

/* [公差] */
cell_fit  = 0.3;    // ロードセルポケットの片側クリアランス
skirt_gap = 1.5;    // スカートとベース外壁の横クリアランス
pin_fit   = 0.2;    // リングピン穴の片側クリアランス

/* [ロードセル (50kg 半橋・体重計タイプ)] */
cell_w        = 34;    // セル本体の一辺
cell_h        = 7.6;   // セル全高
cell_inset    = 25;    // ベース外形コーナーからセル中心までの距離
pedestal_wh   = 44;    // ペデスタル(支持台)の一辺
pocket_wall_t = 2.4;   // セル位置決め壁の厚さ
pocket_wall_h = 4;     // セル位置決め壁の高さ
relief_w      = 24;    // セル中央下の逃げ(たわみ用)の一辺
relief_d      = 3;     // 逃げ深さ
wire_slot_w   = 8;     // セル配線用スロット幅

/* [トッププレート] */
top_underside = 27;    // 上蓋下面の高さ(Pi上空クリアランスを決める)
top_t         = 7;     // 上蓋板厚
skirt_t       = 2.4;   // スカート厚
skirt_drop    = 7;     // スカートが下面から下がる量
boss_d        = 16;    // ロードセルのボタンを押すボスの直径
boss_len      = 4;     // ボス長さ(接触面 z = top_underside - boss_len)
rib_t         = 3;     // 裏面リブ厚
rib_d         = 5;     // 裏面リブ深さ(Pi上空はリブなし)

/* [脚受けリング] */
ring_od     = 110;  // リング外径
ring_id     = 90;   // リング内径(φ80までの脚を受ける)
ring_h      = 5;    // リング高さ
ring_pin_d  = 5;    // 固定ピン径
ring_pin_h  = 3;    // 固定ピン長さ
ring_pin_bc = 100;  // ピン配置円直径

/* [Raspberry Pi 4] */
pi_l        = 85;
pi_w        = 56;
pi_hole_dx  = 58;    // 取付穴ピッチ X
pi_hole_dy  = 49;    // 取付穴ピッチ Y
pi_hole_off = 3.5;   // 基板端から穴中心まで
standoff_h  = 4;     // スタンドオフ高さ
standoff_od = 6.5;
standoff_id = 2.2;   // M2.5 セルフタップ下穴

/* [HX711] */
hx_l      = 34;      // 基板長辺
hx_w      = 21;      // 基板短辺
hx_wall_h = 4;       // 保持リブ高さ
hx_pos    = [46, 0]; // ベイ中心(長辺はY向きに配置)

/* [スペーサー] */
spacer_d          = 110;
spacer_dish_d     = 90;
spacer_dish_depth = 2;

/* [Hidden] */
$fn = 64;
eps = 0.01;

// 派生寸法
cc         = base_outer/2 - cell_inset;               // セル中心座標 (±cc, ±cc)
top_outer  = base_outer + 2*(skirt_gap + skirt_t);    // 上蓋外形
pocket_in  = cell_w + 2*cell_fit;
pocket_out = pocket_in + 2*pocket_wall_t;
// ペデスタル高さ: ボス接触面(top_underside - boss_len)からセル高+ボタン0.4mmを逆算
pedestal_h = top_underside - boss_len - cell_h - 0.4;
// スペーサー高さ: 本体の脚接地面(=上蓋天面)+皿深さ
spacer_h   = top_underside + top_t + spacer_dish_depth;
// Pi 4 は中央縦置き: 基板 56(X)×85(Y)、コネクタ長辺は -X(左壁)向き、
// USB/Ethernet の短辺は +Y(奥)向き、SDカードは -Y(手前)向き
slit_cy    = -pi_l/2 + 36;                            // 左壁スリット中心Y (USB-C〜audioを覆う)
slit_w     = 58;
slit_z     = 6;
pi_holes   = [for (hx = [-pi_hole_dy/2, pi_hole_dy/2],
                   hy = [-pi_l/2 + pi_hole_off, -pi_l/2 + pi_hole_off + pi_hole_dx])
                [hx, hy]];

// ---------- 汎用 ----------
module rsq(sx, sy, r = 3) offset(r) offset(-r) square([sx, sy], center = true);
module rbox(sx, sy, h, r = 3) linear_extrude(height = h) rsq(sx, sy, r);

// ---------- ベース ----------

// ロードセル支持台。原点=セル中心、配線スロットは +X 向き
module pedestal() {
    difference() {
        union() {
            rbox(pedestal_wh, pedestal_wh, pedestal_h, 4);
            // セル位置決め壁
            translate([0, 0, pedestal_h]) linear_extrude(pocket_wall_h)
                difference() {
                    rsq(pocket_out, pocket_out, 4);
                    rsq(pocket_in, pocket_in, 3);
                }
        }
        // セル中央下の逃げ(セルは外周5mm幅のリムで支持される)
        translate([0, 0, pedestal_h - relief_d])
            rbox(relief_w, relief_w, relief_d + pocket_wall_h + eps, 4);
        // 配線スロット(壁を貫通、上開放)
        translate([pocket_in/2 - 1, -wire_slot_w/2, pedestal_h])
            cube([pocket_wall_t + 2, wire_slot_w, pocket_wall_h + eps]);
    }
}

// HX711 保持ベイ。原点=ベイ中心、床上面に置く
module hx_bay() {
    in_x = hx_l + 0.8;
    in_y = hx_w + 0.8;
    difference() {
        linear_extrude(hx_wall_h)
            difference() {
                rsq(in_x + 4, in_y + 4, 3);
                rsq(in_x, in_y, 2);
            }
        // 両端のワイヤ開口
        for (sx = [-1, 1])
            translate([sx*(in_x/2 + 2), 0, hx_wall_h/2 + 0.5])
                cube([8, 14, hx_wall_h + 2], center = true);
    }
}

module base() {
    difference() {
        union() {
            // 床 + 外壁
            difference() {
                rbox(base_outer, base_outer, wall_h, corner_r);
                translate([0, 0, floor_t])
                    rbox(base_outer - 2*wall_t, base_outer - 2*wall_t,
                         wall_h, max(1, corner_r - wall_t));
            }
            // ペデスタル×4(配線スロットが中央側を向くよう回転)
            for (sx = [-1, 1], sy = [-1, 1])
                translate([sx*cc, sy*cc, 0])
                    rotate([0, 0, sx > 0 ? 180 : 0]) pedestal();
            // Pi スタンドオフ
            for (p = pi_holes)
                translate([p[0], p[1], floor_t])
                    cylinder(d = standoff_od, h = standoff_h);
            // HX711 ベイ(長辺Y向き)
            translate([hx_pos[0], hx_pos[1], floor_t]) rotate([0, 0, 90]) hx_bay();
        }
        // スタンドオフ下穴(M2.5 セルフタップ)
        for (p = pi_holes)
            translate([p[0], p[1], floor_t + standoff_h - 5.5])
                cylinder(d = standoff_id, h = 6);
        // 左側面ケーブルスリット(USB-C電源・HDMI。上開放でブリッジ不要)
        translate([-base_outer/2 - 1, slit_cy - slit_w/2, slit_z])
            cube([wall_t + 2, slit_w, wall_h]);
        // 背面予備スリット(ブザー等)
        translate([-6, base_outer/2 - wall_t - 1, slit_z])
            cube([12, wall_t + 2, wall_h]);
        // ベントスロット(右側面+前面)
        for (vy = [-30, -10, 10, 30])
            translate([base_outer/2 - (wall_t + 2)/2, vy - 2, 8])
                cube([wall_t + 2, 4, 12]);
        for (vx = [-30, -10, 10, 30])
            translate([vx - 2, -base_outer/2 - 1, 8])
                cube([4, wall_t + 2, 12]);
        // HX711 結束バンド用スロット(床貫通)
        for (sx = [-1, 1])
            translate([hx_pos[0] + sx*(hx_w/2 + 5) - 1.5, hx_pos[1] - 4, -1])
                cube([3, 8, floor_t + 2]);
    }
}

// ---------- トッププレート ----------

module ribs() {
    difference() {
        intersection() {
            translate([0, 0, top_underside - rib_d])
                linear_extrude(rib_d + eps) union() {
                    for (a = [45, -45])
                        rotate([0, 0, a]) square([280, rib_t], center = true);
                    square([rib_t, 170], center = true);
                    square([170, rib_t], center = true);
                    // Pi両脇のフランクリブ(脚荷重を四隅へ流すメインビーム)
                    for (s = [-1, 1]) {
                        translate([s*(pi_w/2 + 8), 0])
                            square([rib_t, 170], center = true);
                        translate([0, s*(pi_l/2 + 8.5)])
                            square([170, rib_t], center = true);
                    }
                }
            rbox(base_outer - 2*wall_t - 4, base_outer - 2*wall_t - 4,
                 100, corner_r);
        }
        // Pi 上空はリブ禁止(クリアランス確保)
        translate([-pi_w/2 - 5, -pi_l/2 - 5, top_underside - rib_d - 1])
            cube([pi_w + 10, pi_l + 10, rib_d + 2]);
    }
}

module top_plate() {
    difference() {
        union() {
            // 天板スラブ
            translate([0, 0, top_underside])
                rbox(top_outer, top_outer, top_t, corner_r + 2);
            // スカート(横ズレ・ホコリ防止。上下方向はフリー)
            translate([0, 0, top_underside - skirt_drop])
                linear_extrude(skirt_drop + eps)
                    difference() {
                        rsq(top_outer, top_outer, corner_r + 2);
                        rsq(base_outer + 2*skirt_gap, base_outer + 2*skirt_gap,
                            corner_r + 1);
                    }
            // ロードセルボタンを押すボス×4
            for (sx = [-1, 1], sy = [-1, 1])
                translate([sx*cc, sy*cc, top_underside - boss_len])
                    cylinder(d = boss_d, h = boss_len + eps);
            ribs();
        }
        // 脚受けリング用ピン穴×3
        for (a = [90, 210, 330])
            rotate([0, 0, a])
                translate([ring_pin_bc/2, 0,
                           top_underside + top_t - ring_pin_h - 2*pin_fit])
                    cylinder(d = ring_pin_d + 2*pin_fit,
                             h = ring_pin_h + 2*pin_fit + eps);
    }
}

// ---------- 脚受けリング ----------
module leg_ring() {
    difference() {
        cylinder(d = ring_od, h = ring_h);
        translate([0, 0, -1]) cylinder(d = ring_id, h = ring_h + 2);
    }
    for (a = [90, 210, 330])
        rotate([0, 0, a])
            translate([ring_pin_bc/2, 0, -ring_pin_h])
                cylinder(d = ring_pin_d, h = ring_pin_h + eps);
}
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

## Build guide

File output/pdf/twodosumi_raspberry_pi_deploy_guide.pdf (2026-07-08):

2dosumi Raspberry Pi デプロイ手順

config/pi.aggregate.json と config/secrets.json は Pi 側を正として保持 | 1

# 2dosumi Raspberry Pi デプロイ手順

## Windows から Raspberry Pi へ同期し、校正済み設定を守りながら Web UI を systemd と Tailscale Serve で運用するための実行手順です。

このPDFで扱う範囲

初回デプロイ、更新デプロイ、Tailscale公開、センサー確認、校正、systemdの運用確認。OSイメージ作成やTailscaleアカウント登 録は前提外です。

前提

□ | Windows から ssh/scp で Pi に接続できる
□ | Pi は systemd が使える Raspberry Pi OS 系
□ | Tailscale は Pi 側でログイン済み、または後で設 定する
□ | GPIO 配線は DATA=D6、SCK=D5、ブザー=D13 前 提

## 既定値

項目 | 値
HostName | 192.168.137.105
User | yuki
RemoteDir | /home/yuki/2dosumi
Port | 8080

## 全体の流れ

順番 | 作業 | 結果
1 | Windowsからdeploy_pi.ps1を実行 | コードだけをPiへ同期
2 | Pi上で.venv作成と依存更新 | Python環境をアプリ専用に固定
3 | systemdサービスを再起動 | 起動時にWeb UIが自動起動
4 | Tailscale Serveを有効化 | ブラウザから安全にアクセス
5 | センサー確認と校正 | 検知に使う重量値を本番化

config/pi.aggregate.json と config/secrets.json は Pi 側を正として保持 | 2

# 1. 初回デプロイ

まず Windows 側のプロジェクトフォルダから Pi へ接続できることを確認します。

ssh yuki@192.168.137.105

接続できたら、Windows 側でデプロイスクリプトを実行します。

.\scripts\deploy_pi.ps1 -HostName 192.168.137.105 -User yuki -RemoteDir /home/yuki/2dosumi

重要: Pi側の設定を守る

config/pi.aggregate.json は Pi に存在しない初回だけ配置します。既にある場合は上書きしません。config/secrets.json も通常のデプ ロイ対象外です。

## スクリプトが行うこと

□ | twodosumi、scripts、docs、requirements-pi.txt、README.md を同期
□ | Pi に config/pi.aggregate.json がない場合だけ初期設定を配置
□ | .venv を作成または更新し、requirements-pi.txt をインストール
□ | twodosumi-web.service をインストールまたは再起動
□ | http://127.0.0.1:8080/healthz を確認

作業ツリーに未コミット変更がある状態で実機テストしたい場合だけ、明示的に許可します。

.\scripts\deploy_pi.ps1 -AllowDirty

venv作成で失敗した場合

Pi側で python3-venv が入っていない可能性があります。次を実行してから、Windows側でデプロイを再実行します。

ssh yuki@192.168.137.105

sudo apt-get update

sudo apt-get install -y python3-venv

config/pi.aggregate.json と config/secrets.json は Pi 側を正として保持 | 3

# 2. Web UIをTailscaleで公開

Flask は Pi の localhost だけで待ち受けます。外からのアクセスは Tailscale Serve を使います。

tailscale serve --bg 8080

tailscale serve status

初回トークン

初回起動時に config/secrets.json が作成され、web_ui_token が発行されます。Web UIでこのトークンを入力します。

journalctl -u twodosumi-web.service --no-pager -n 50

# 3. センサー配線の前提

HX711 | Raspberry Pi
DT / DOUT | GPIO6 / board.D6
SCK / CLK | GPIO5 / board.D5
VCC | 3.3V
GND | GND

電圧注意

まず HX711 VCC は 3.3V で使います。Raspberry Pi の GPIO に 5V 信号を入れないでください。

# 4. 最初のセンサー確認

cd /home/yuki/2dosumi

. .venv/bin/activate

python -m twodosumi check-sensor --config config/pi.aggregate.json --samples 10

成功時は ok=True、samples=10/10、raw の min/max/median が表示されます。Web UI の センサー確認 ボタン でも同じ確認ができます。

よくある失敗

HX711 DOUT stayed HIGH が出る場合は、HX711の電源、GND、DT/DOUT、SCK/CLK、ロードセルブリッジ配線を確認します。

config/pi.aggregate.json と config/secrets.json は Pi 側を正として保持 | 4

# 5. 校正

検知精度の中心になる作業です。ベッドを空にしてゼロ校正し、既知の重さを載せてスケール校正します。

## ゼロ校正

python -m twodosumi calibrate-zero --config config/pi.aggregate.json

## 重量校正

python -m twodosumi calibrate-scale --config config/pi.aggregate.json --known-kg 8

known-kg

例の 8 は実際に載せた既知重量 kg に置き換えます。校正後は再度センサー確認し、weight_median_kg が現在の荷重に近いことを 確認します。

# 6. サービス運用確認

systemctl status twodosumi-web.service --no-pager

journalctl -u twodosumi-web.service -f

tailscale serve status

curl http://127.0.0.1:8080/healthz

## サービスを手動で入れ直す場合

cd /home/yuki/2dosumi

APP_DIR=/home/yuki/2dosumi APP_USER=yuki PORT=8080 ./scripts/install_twodosumi_web_service.sh

## Web UIを手動起動してデバッグする場合

cd /home/yuki/2dosumi

. .venv/bin/activate

python -m twodosumi web --config config/pi.aggregate.json --secrets config/secrets.json --host 127.0.0.1 --port 8080

config/pi.aggregate.json と config/secrets.json は Pi 側を正として保持 | 5

# 7. 日常運用と更新

Web UI へ Tailscale 経由でアクセスし、web_ui_token を入力して操作します。

□ | センサー確認 を実行
□ | ライブ重量とステータスを確認
□ | 予定アラームを設定
□ | 開始 を押して検知を開始

## コード更新時

.\scripts\deploy_pi.ps1

未コミットの作業中変更を実機に送る場合だけ次を使います。

.\scripts\deploy_pi.ps1 -AllowDirty

# トラブルシュート早見表

症状 | 見る場所 | 対応
Web UIが開かない | systemctl status / curl / tailscale serve status | サービス起動、ポート8080、Tailscale Serveを確認
認証できない | journalctl / config/secrets.json | web_ui_token を確認して再入力
センサー値が出ない | check-sensor のエラー | HX711電源、GND、DOUT、SCK、ブリッジ配線を確 認
重量がずれる | weight_median_kg | ゼロ校正と重量校正をやり直す
更新で設定が戻る | Pi側 config | 通常デプロイでは config を上書きしない。手動コピー を避ける

運用ルール

Pi 上の config/pi.aggregate.json と config/secrets.json は本番状態です。校正値、Web UI設定、Webhook URL、トークンを守るため、 通常の更新ではPC側から上書きしません。

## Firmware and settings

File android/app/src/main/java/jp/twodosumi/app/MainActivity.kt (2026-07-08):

@file:OptIn(androidx.compose.material3.ExperimentalMaterial3Api::class)

package jp.twodosumi.app

import android.Manifest
import android.content.ActivityNotFoundException
import android.content.Context
import android.content.Intent
import android.content.pm.PackageManager
import android.os.Build
import android.os.Bundle
import android.provider.AlarmClock
import android.widget.Toast
import androidx.activity.compose.BackHandler
import androidx.activity.ComponentActivity
import androidx.activity.compose.setContent
import androidx.compose.foundation.BorderStroke
import androidx.compose.foundation.Canvas
import androidx.compose.foundation.clickable
import androidx.compose.foundation.layout.Arrangement
import androidx.compose.foundation.layout.Column
import androidx.compose.foundation.layout.Row
import androidx.compose.foundation.layout.Spacer
import androidx.compose.foundation.layout.fillMaxSize
import androidx.compose.foundation.layout.fillMaxWidth
import androidx.compose.foundation.layout.height
import androidx.compose.foundation.layout.heightIn
import androidx.compose.foundation.layout.padding
import androidx.compose.foundation.layout.width
import androidx.compose.foundation.lazy.LazyColumn
import androidx.compose.foundation.lazy.items
import androidx.compose.foundation.shape.RoundedCornerShape
import androidx.compose.foundation.text.KeyboardOptions
import androidx.compose.material.icons.Icons
import androidx.compose.material.icons.automirrored.outlined.ArrowBack
import androidx.compose.material.icons.outlined.Add
import androidx.compose.material.icons.outlined.Alarm
import androidx.compose.material.icons.outlined.AddAlarm
import androidx.compose.material.icons.outlined.Build
import androidx.compose.material.icons.outlined.Delete
import androidx.compose.material.icons.outlined.Home
import androidx.compose.material.icons.outlined.Refresh
import androidx.compose.material.icons.outlined.Save
import androidx.compose.material.icons.outlined.Settings
import androidx.compose.material3.AssistChip
import androidx.compose.material3.AlertDialog
import androidx.compose.material3.Button
import androidx.compose.material3.ButtonDefaults
import androidx.compose.material3.Card
import androidx.compose.material3.CardDefaults
import androidx.compose.material3.HorizontalDivider
import androidx.compose.material3.ExperimentalMaterial3Api
import androidx.compose.material3.FilterChip
import androidx.compose.material3.Icon
import androidx.compose.material3.IconButton
import androidx.compose.material3.MaterialTheme
import androidx.compose.material3.NavigationBar
import androidx.compose.material3.NavigationBarItem
import androidx.compose.material3.OutlinedButton
import androidx.compose.material3.OutlinedTextField
import androidx.compose.material3.Scaffold
import androidx.compose.material3.Slider
import androidx.compose.material3.SnackbarHost
import androidx.compose.material3.SnackbarHostState
import androidx.compose.material3.SnackbarResult
import androidx.compose.material3.Surface
import androidx.compose.material3.Switch
import androidx.compose.material3.Text
import androidx.compose.material3.TextButton
import androidx.compose.material3.TimePicker
import androidx.compose.material3.rememberTimePickerState
import androidx.compose.runtime.Composable
import androidx.compose.runtime.LaunchedEffect
import androidx.compose.runtime.getValue
import androidx.compose.runtime.mutableStateOf
import androidx.compose.runtime.remember
import androidx.compose.runtime.setValue
import androidx.compose.ui.Alignment
import androidx.compose.ui.Modifier
import androidx.compose.ui.draw.alpha
import androidx.compose.ui.geometry.Offset
import androidx.compose.ui.graphics.Color
import androidx.compose.ui.graphics.Path
import androidx.compose.ui.graphics.drawscope.Stroke
import androidx.compose.ui.graphics.vector.ImageVector
import androidx.compose.ui.platform.LocalContext
import androidx.compose.ui.semantics.selected
import androidx.compose.ui.semantics.semantics
import androidx.compose.ui.text.font.FontWeight
import androidx.compose.ui.text.input.KeyboardType
import androidx.compose.ui.text.input.PasswordVisualTransformation
import androidx.compose.ui.text.style.TextOverflow
import androidx.compose.ui.unit.dp
import androidx.lifecycle.ViewModel
import androidx.lifecycle.ViewModelProvider
import androidx.lifecycle.viewmodel.compose.viewModel
import java.util.Calendar
import kotlin.math.max

class MainActivity : ComponentActivity() {
    override fun onCreate(savedInstanceState: Bundle?) {
        super.onCreate(savedInstanceState)
        requestNotificationPermission()
        setContent {
            TwodosumiTheme {
                TwodosumiApp()
            }
        }
    }

    private fun requestNotificationPermission() {
        if (Build.VERSION.SDK_INT < Build.VERSION_CODES.TIRAMISU) return
        if (checkSelfPermission(Manifest.permission.POST_NOTIFICATIONS) == PackageManager.PERMISSION_GRANTED) return
        requestPermissions(arrayOf(Manifest.permission.POST_NOTIFICATIONS), 1001)
    }
}

@Composable
private fun TwodosumiTheme(content: @Composable () -> Unit) {
    MaterialTheme(
        colorScheme = androidx.compose.material3.lightColorScheme(
            primary = Color(0xFF007AFF),
            secondary = Color(0xFF34C759),
            error = Color(0xFFFF3B30),
            surface = Color(0xFFFFFFFF),
            background = Color(0xFFF2F2F7),
        ),
        content = content,
    )
}

@Composable
private fun TwodosumiApp() {
    val context = LocalContext.current.applicationContext
    val vm: AppViewModel = viewModel(factory = object : ViewModelProvider.Factory {
        override fun <T : ViewModel> create(modelClass: Class<T>): T {
            @Suppress("UNCHECKED_CAST")
            return AppViewModel(context) as T
        }
    })
    val state by vm.uiState
    val snackbar = remember { SnackbarHostState() }
    val snackbarText = state.error ?: state.message

    LaunchedEffect(snackbarText) {
        if (!snackbarText.isNullOrBlank()) {
            snackbar.showSnackbar(snackbarText)
            vm.clearMessage()
        }
    }
    LaunchedEffect(state.deletedAlarm) {
        if (state.deletedAlarm != null) {
            val result = snackbar.showSnackbar(
                message = "アラームを削除しました",
                actionLabel = "元に戻す",
            )
            if (result == SnackbarResult.ActionPerformed) vm.undoDeleteAlarm() else vm.clearDeletedAlarm()
        }
    }
    if (state.phoneAlarmActive) {
        PhoneAlarmDialog(
            title = state.phoneAlarmTitle.ifBlank { "2dosumiアラーム" },
            onDismiss = vm::dismissPhoneAlarm,
        )
    }

    Scaffold(
        snackbarHost = { SnackbarHost(snackbar) },
        bottomBar = {
            NavigationBar {
                Tab.entries.forEach { tab ->
                    NavigationBarItem(
                        selected = state.activeTab == tab,
                        onClick = { vm.setTab(tab) },
                        icon = { Icon(tab.icon(), contentDescription = tab.label) },
                        label = { Text(tab.label) },
                    )
                }
            }
        },
    ) { padding ->
        Surface(
            modifier = Modifier
                .fillMaxSize()
                .padding(padding),
            color = MaterialTheme.colorScheme.background,
        ) {
            when (state.activeTab) {
                Tab.Overview -> OverviewScreen(state, vm)
                Tab.Alarms -> AlarmsScreen(state, vm)
                Tab.Calibration -> CalibrationScreen(state, vm)
                Tab.Settings -> SettingsScreen(state, vm)
            }
        }
    }
}

@Composable
private fun PhoneAlarmDialog(title: String, onDismiss: () -> Unit) {
    AlertDialog(
        onDismissRequest = {},
        title = { Text(title) },
        text = { Text("スマホでアラームを鳴らしています。") },
        confirmButton = {
            Button(onClick = onDismiss) {
                Text("停止")
            }
        },
    )
}

private fun Tab.icon(): ImageVector = when (this) {
    Tab.Overview -> Icons.Outlined.Home
    Tab.Alarms -> Icons.Outlined.Alarm
    Tab.Calibration -> Icons.Outlined.Build
    Tab.Settings -> Icons.Outlined.Settings
}

@Composable
private fun OverviewScreen(state: UiState, vm: AppViewModel) {
    LazyColumn(
        modifier = Modifier.fillMaxSize(),
        contentPadding = androidx.compose.foundation.layout.PaddingValues(16.dp),
        verticalArrangement = Arrangement.spacedBy(12.dp),
    ) {
        item { CompactHeader(state) }
        if (!state.connected) item { ConnectCard(state, vm) }
        item { StatusHero(state, vm) }
        item { AlarmSummary(state) }
        item { StatusDetails(state) }
        item { EventTimeline(state.events) }
    }
}

@Composable
private fun CompactHeader(state: UiState) {
    Row(
        modifier = Modifier.fillMaxWidth().heightIn(min = 48.dp),
        horizontalArrangement = Arrangement.SpaceBetween,
        verticalAlignment = Alignment.CenterVertically,
    ) {
        Text("2dosumi", style = MaterialTheme.typography.titleLarge, fontWeight = FontWeight.Bold)
        Row(horizontalArrangement = Arrangement.spacedBy(12.dp), verticalAlignment = Alignment.CenterVertically) {
            CompactStatus(if (state.connected) "接続済" else "未接続", if (state.connected) Tone.Done else Tone.Idle)
            CompactStatus(if (isRunning(state.status)) "稼働中" else "停止中", if (isRunning(state.status)) Tone.Sleep else Tone.Idle)
        }
    }
}

@Composable
private fun CompactStatus(label: String, tone: Tone) {
    Row(horizontalArrangement = Arrangement.spacedBy(5.dp), verticalAlignment = Alignment.CenterVertically) {
        ToneDot(tone)
        Text(label, style = MaterialTheme.typography.bodySmall, color = MaterialTheme.colorScheme.onSurfaceVariant)
    }
}

@Composable
private fun ConnectCard(state: UiState, vm: AppViewModel) {
    SectionCard(title = "接続") {
        OutlinedTextField(
            value = state.baseUrl,
            onValueChange = vm::updateBaseUrl,
            modifier = Modifier.fillMaxWidth(),
            label = { Text("Pi Web UI URL") },
            placeholder = { Text("http://raspberrypi.local:8080") },
            singleLine = true,
        )
        Spacer(Modifier.height(8.dp))
        OutlinedTextField(
            value = state.token,
            onValueChange = vm::updateToken,
            modifier = Modifier.fillMaxWidth(),
            label = { Text("Web UI Token") },
            visualTransformation = PasswordVisualTransformation(),
            singleLine = true,
        )
        if (state.baseUrl.startsWith("http://")) {
            Spacer(Modifier.height(6.dp))
            Text("HTTP接続です。Tailscale Serve等でHTTPSが使える場合はHTTPSを推奨します。", color = MaterialTheme.colorScheme.error)
        }
        Spacer(Modifier.height(12.dp))
        Button(
            onClick = vm::connect,
            enabled = !state.loading,
            modifier = Modifier.fillMaxWidth(),
        ) {
            Text(state.busyAction ?: "保存して接続")
        }
    }
}

@Composable
private fun StatusHero(state: UiState, vm: AppViewModel) {
    val status = state.status
    val settings = state.settings ?: state.draftSettings
    val meta = StateLabels[status?.state.orEmpty()]
    val presence = presenceLabel(status?.smoothedWeightKg ?: status?.weightKg, settings)
    SectionCard(title = "概要") {
        Row(verticalAlignment = Alignment.CenterVertically) {
            ToneChip(meta?.label ?: status?.state?.ifBlank { "未取得" } ?: "未取得", meta?.tone ?: Tone.Idle)
            Spacer(Modifier.width(8.dp))
            Text(
                status?.timestamp?.let { "${formatLocalTime(it, "HH:mm:ss")} 更新" } ?: "更新待ち",
                style = MaterialTheme.typography.bodySmall,
                color = MaterialTheme.colorScheme.onSurfaceVariant,
            )
            Spacer(Modifier.weight(1f))
            IconButton(onClick = vm::loadStatus) {
                Icon(Icons.Outlined.Refresh, contentDescription = "状態更新")
            }
        }
        Spacer(Modifier.height(12.dp))
        Text(
            presence,
            style = MaterialTheme.typography.displaySmall,
            fontWeight = FontWeight.Bold,
        )
        Text(
            status?.smoothedWeightKg?.let { "推定 %.1f kg 相当".format(it) } ?: "検知開始後に判定します",
            color = MaterialTheme.colorScheme.onSurfaceVariant,
        )
        Sparkline(state.weightHistory)
        MissionProgress(status?.pendingRechecks.orEmpty())
        Spacer(Modifier.height(12.dp))
        Row(horizontalArrangement = Arrangement.spacedBy(8.dp)) {
            Button(onClick = vm::startRun, enabled = !state.loading, modifier = Modifier.weight(1f)) {
                Text("検知開始")
            }
            OutlinedButton(onClick = vm::stopRun, enabled = !state.loading, modifier = Modifier.weight(1f)) {
                Text("検知停止")
            }
        }
    }
}

@Composable
private fun AlarmSummary(state: UiState) {
    val settings = state.draftSettings ?: state.settings
    val enabled = settings?.scheduledAlarms.orEmpty().filter { it.enabled }
    val featured = state.status?.nextScheduledAlarm ?: enabled.firstOrNull()
    val others = enabled.filterNot { it.id == featured?.id }.take(3)
    SectionCard(title = "次のアラーム") {
        if (featured == null) {
            Text("次のアラームは未設定です", color = MaterialTheme.colorScheme.onSurfaceVariant)
        } else {
            Row(verticalAlignment = Alignment.Bottom) {
                Text(featured.time, style = MaterialTheme.typography.headlineMedium, fontWeight = FontWeight.Bold)
                Spacer(Modifier.width(12.dp))
                Column {
                    Text(featured.label.ifBlank { "アラーム" }, fontWeight = FontWeight.SemiBold)
                    Text(formatWeekdaySummary(featured.weekdays), color = MaterialTheme.colorScheme.onSurfaceVariant)
                }
            }
        }
        if (others.isNotEmpty()) {
            HorizontalDivider(Modifier.padding(vertical = 10.dp))
            others.forEach { alarm ->
                Row(
                    modifier = Modifier.fillMaxWidth().padding(vertical = 3.dp),
                    verticalAlignment = Alignment.CenterVertically,
                ) {
                    Text(alarm.time, fontWeight = FontWeight.Bold, modifier = Modifier.width(64.dp))
                    Text(
                        "${alarm.label.ifBlank { "アラーム" }}  ${formatWeekdaySummary(alarm.weekdays)}",
                        modifier = Modifier.weight(1f),
                        maxLines = 1,
                        overflow = TextOverflow.Ellipsis,
                        color = MaterialTheme.colorScheme.onSurfaceVariant,
                    )
                }
            }
        }
    }
}

@Composable
private fun StatusDetails(state: UiState) {
    val status = state.status
    val settings = state.settings ?: state.draftSettings
    SectionCard(title = "状態") {
        MetricGrid(
            listOf(
                "在床判定" to presenceLabel(status?.smoothedWeightKg ?: status?.weightKg, settings),
                "状態" to (StateLabels[status?.state.orEmpty()]?.label ?: status?.state.orEmpty().ifBlank { "-" }),
                "イベント" to status?.event.orEmpty().ifBlank { "-" },
                "推定値" to (status?.smoothedWeightKg?.let { "%.2f kg相当".format(it) } ?: "-"),
                "プロセス" to if (isRunning(status)) "稼働中" else "停止中",
                "次アラーム" to (formatAlarm(status?.nextScheduledAlarm) ?: "-"),
                "再確認" to formatRechecks(status?.pendingRechecks.orEmpty()),
            )
        )
    }
}

@Composable
private fun EventTimeline(events: List<EventEntry>) {
    SectionCard(title = "最近のできごと") {
        if (events.isEmpty()) {
            Text("状態の変化がここに記録されます。", color = MaterialTheme.colorScheme.onSurfaceVariant)
        } else {
            events.forEach { entry ->
                Row(Modifier.fillMaxWidth().padding(vertical = 6.dp), verticalAlignment = Alignment.CenterVertically) {
                    ToneDot(entry.tone)
                    Spacer(Modifier.width(10.dp))
                    Text(entry.label, modifier = Modifier.weight(1f), fontWeight = FontWeight.SemiBold)
                    Text(entry.time, color = MaterialTheme.colorScheme.onSurfaceVariant)
                }
            }
        }
    }
}

@Composable
private fun AlarmsScreen(state: UiState, vm: AppViewModel) {
    val settings = state.draftSettings ?: state.settings
    val context = LocalContext.current
    val editorId = state.alarmEditorId
    if (editorId != null) {
        val alarm = if (editorId == AppViewModel.NEW_ALARM_ID) {
            state.newAlarmDraft
        } else {
            settings?.scheduledAlarms?.firstOrNull { it.id == editorId }
        }
        if (alarm != null) {
            AlarmEditorScreen(
                alarm = alarm,
                isNew = editorId == AppViewModel.NEW_ALARM_ID,
                saveStatus = state.alarmSaveStatus,
                loading = state.loading,
                onBack = vm::closeAlarmEditor,
                onChange = { transform ->
                    if (editorId == AppViewModel.NEW_ALARM_ID) vm.updateNewAlarm(transform)
                    else vm.updateAlarm(editorId, transform)
                },
                onLabelChange = { label ->
                    if (editorId == AppViewModel.NEW_ALARM_ID) {
                        vm.updateNewAlarm { it.copy(label = label) }
                    } else {
                        vm.updateAlarmLabel(editorId, label)
                    }
                },
                onCreate = vm::createAlarm,
                onDelete = { vm.deleteAlarm(editorId) },
                onAddToClock = { addToClockApp(context, alarm) },
            )
            return
        }
    }

    LazyColumn(
        modifier = Modifier.fillMaxSize(),
        contentPadding = androidx.compose.foundation.layout.PaddingValues(16.dp),
        verticalArrangement = Arrangement.spacedBy(12.dp),
    ) {
        item { CompactHeader(state) }
        item {
            SectionCard(title = "時刻アラーム") {
                ToggleRow(
                    title = "有効",
                    description = "登録時刻にベッド上なら鳴らす",
                    checked = settings?.scheduledAlarmEnabled == true,
                    onCheckedChange = vm::setScheduledAlarmEnabled,
                )
                SaveStatusLabel(state.alarmSaveStatus)
            }
        }
        item {
            SectionCard(title = "登録済み") {
                if (settings?.scheduledAlarms.isNullOrEmpty()) {
                    Text("アラームはありません", color = MaterialTheme.colorScheme.onSurfaceVariant)
                }
                val alarms = settings?.scheduledAlarms.orEmpty()
                alarms.forEachIndexed { index, alarm ->
                    AlarmListRow(
                        alarm = alarm,
                        onEnabledChange = { enabled -> vm.updateAlarm(alarm.id) { it.copy(enabled = enabled) } },
                        onEdit = { vm.openAlarmEditor(alarm.id) },
                        onAddToClock = { addToClockApp(context, alarm) },
                    )
                    if (index < alarms.lastIndex) {
                        HorizontalDivider(Modifier.padding(vertical = 4.dp))
                    }
                }
                if (alarms.isNotEmpty()) Spacer(Modifier.height(8.dp))
                OutlinedButton(onClick = vm::openNewAlarmEditor, modifier = Modifier.fillMaxWidth()) {
                    Icon(Icons.Outlined.Add, contentDescription = null)
                    Spacer(Modifier.width(6.dp))
                    Text("アラームを追加")
                }
            }
        }
        item {
            SectionCard(title = "起床ミッション") {
                ToggleRow(
                    title = "有効",
                    description = "離床を確認するまで再アラーム",
                    checked = settings?.wakeMissionEnabled == true,
                    onCheckedChange = vm::setWakeMissionEnabled,
                )
                settings?.let {
                    RecheckIntervalControl(it.bedRecheckMinutes, vm::setBedRecheckMinutes)
                    NumberField("離床確認 秒", it.wakeMissionRequiredOffBedSec, vm::setWakeMissionRequiredSeconds)
                }
            }
        }
        item {
            SectionCard(title = "二度寝検知") {
                settings?.let {
                    SecondSleepConfirmControl(it.confirmSec, vm::setSecondSleepConfirmSeconds)
                    SaveStatusLabel(state.alarmSaveStatus)
                }
            }
        }
    }
}

@Composable
private fun RecheckIntervalControl(value: Double, onChange: (Double) -> Unit) {
    Text("再確認 ${value.cleanString()} 分", fontWeight = FontWeight.SemiBold)
    Row(horizontalArrangement = Arrangement.spacedBy(8.dp), modifier = Modifier.fillMaxWidth()) {
        listOf(3.0, 5.0, 10.0, 15.0).forEach { minutes ->
            FilterChip(
                selected = value == minutes,
                onClick = { onChange(minutes) },
                modifier = Modifier.weight(1f),
                label = { Text("${minutes.toInt()}分") },
            )
        }
    }
    Row(horizontalArrangement = Arrangement.spacedBy(8.dp), modifier = Modifier.fillMaxWidth()) {
        OutlinedButton(
            onClick = { onChange((value - 1.0).coerceAtLeast(1.0)) },
            modifier = Modifier.weight(1f),
        ) {
            Text("-1分")
        }
        OutlinedButton(
            onClick = { onChange(value + 1.0) },
            modifier = Modifier.weight(1f),
        ) {
            Text("+1分")
        }
    }
}
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

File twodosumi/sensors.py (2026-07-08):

from __future__ import annotations

from abc import ABC, abstractmethod
from dataclasses import dataclass
import itertools
import math
import statistics
import time
from typing import Iterable

from .config import AppConfig


HX711_INVALID_RAW_VALUES = frozenset((-0x800000, -1, 0x7FFFFF))
HX711_READ_ATTEMPTS = 3


class SensorReader(ABC):
    @abstractmethod
    def read_raw(self) -> float:
        raise NotImplementedError

    def close(self) -> None:
        pass


@dataclass
class SensorCheckResult:
    ok: bool
    reader: str
    samples_requested: int
    samples_read: int
    raw_min: float | None = None
    raw_max: float | None = None
    raw_median: float | None = None
    raw_span: float | None = None
    weight_median_kg: float | None = None
    duration_sec: float = 0.0
    message: str = ""
    warnings: list[str] | None = None


class MockReader(SensorReader):
    def __init__(self, config: AppConfig) -> None:
        points: list[float] = []
        for step in config.mock_sequence:
            samples = int(step["samples"])
            raw = config.zero_offset + float(step["weight_kg"]) * config.scale_factor
            points.extend([raw] * samples)
        if not points:
            points = [config.zero_offset]
        self._values = itertools.chain(points, itertools.repeat(points[-1]))

    def read_raw(self) -> float:
        return float(next(self._values))


class AdafruitHX711AggregateReader(SensorReader):
    def __init__(self, config: AppConfig) -> None:
        self._gpio = None
        self._gpio_data_pin: int | None = None
        self._gpio_clock_pin: int | None = None
        self._data = None
        self._clock = None
        self._timeout_sec = config.hx711_ready_timeout_sec
        self._data_pin_name = config.data_pin
        self._clock_pin_name = config.clock_pin

        GPIO = None
        try:
            import RPi.GPIO as candidate_gpio

            data_pin = _board_pin_to_bcm(config.data_pin)
            clock_pin = _board_pin_to_bcm(config.clock_pin)
            candidate_gpio.setwarnings(False)
            candidate_gpio.setmode(candidate_gpio.BCM)
            candidate_gpio.setup(data_pin, candidate_gpio.IN)
            candidate_gpio.setup(
                clock_pin, candidate_gpio.OUT, initial=candidate_gpio.LOW
            )
            GPIO = candidate_gpio
        except ImportError:
            GPIO = None
        except RuntimeError:
            try:
                candidate_gpio.cleanup((data_pin, clock_pin))
            except RuntimeError:
                pass
            GPIO = None

        if GPIO is not None:
            self._gpio = GPIO
            self._gpio_data_pin = data_pin
            self._gpio_clock_pin = clock_pin
            return

        try:
            import board
            import digitalio
        except ImportError as exc:
            raise RuntimeError(
                "Install Pi dependencies with: python3 -m pip install -r requirements-pi.txt"
            ) from exc

        data_pin = getattr(board, config.data_pin)
        clock_pin = getattr(board, config.clock_pin)
        data = digitalio.DigitalInOut(data_pin)
        data.direction = digitalio.Direction.INPUT
        clock = digitalio.DigitalInOut(clock_pin)
        clock.direction = digitalio.Direction.OUTPUT
        clock.value = False

        self._data = data
        self._clock = clock

    def read_raw(self) -> float:
        last_value = 0
        for _ in range(HX711_READ_ATTEMPTS):
            self._wait_until_ready()
            last_value = self._read_channel_a_gain_128()
            if last_value not in HX711_INVALID_RAW_VALUES:
                return float(last_value)
        raise RuntimeError(
            "HX711 returned an invalid endpoint value "
            f"({last_value}) {HX711_READ_ATTEMPTS} times. "
            "This usually means SCK timing interference or an unstable GPIO backend."
        )

    def close(self) -> None:
        if self._gpio is not None:
            pins = [
                pin
                for pin in (self._gpio_data_pin, self._gpio_clock_pin)
                if pin is not None
            ]
            if pins:
                self._gpio.cleanup(pins)
            self._gpio = None
        for pin in (self._data, self._clock):
            if pin is not None:
                pin.deinit()
        self._data = None
        self._clock = None

    def _wait_until_ready(self) -> None:
        deadline = time.monotonic() + self._timeout_sec
        while self._read_data_pin():
            if time.monotonic() >= deadline:
                raise TimeoutError(
                    "HX711 DOUT stayed HIGH and no sample became ready. "
                    f"Check VCC=3.3V, GND, DT/DOUT={self._data_pin_name}, "
                    f"SCK/CLK={self._clock_pin_name}, and the 4-load-cell bridge wiring."
                )
            time.sleep(0.01)

    def _read_channel_a_gain_128(self) -> int:
        value = 0
        try:
            for _ in range(24):
                self._set_clock_pin(True)
                value = (value << 1) | int(self._read_data_pin())
                self._set_clock_pin(False)

            # One extra pulse selects channel A with gain 128 for the next sample.
            self._set_clock_pin(True)
            self._set_clock_pin(False)
        finally:
            self._set_clock_pin(False)

        if value & 0x800000:
            value -= 0x1000000
        return value

    def _read_data_pin(self) -> bool:
        if self._gpio is not None:
            return bool(self._gpio.input(self._gpio_data_pin))
        return bool(self._data.value)

    def _set_clock_pin(self, value: bool) -> None:
        if self._gpio is not None:
            self._gpio.output(self._gpio_clock_pin, self._gpio.HIGH if value else self._gpio.LOW)
            return
        self._clock.value = value


def _board_pin_to_bcm(pin_name: str) -> int:
    if not pin_name.startswith("D"):
        raise ValueError(f"Unsupported Raspberry Pi GPIO pin name: {pin_name}")
    try:
        return int(pin_name[1:])
    except ValueError as exc:
        raise ValueError(f"Unsupported Raspberry Pi GPIO pin name: {pin_name}") from exc


def create_reader(config: AppConfig) -> SensorReader:
    if config.reader == "mock":
        return MockReader(config)
    if config.reader == "adafruit_hx711":
        return AdafruitHX711AggregateReader(config)
    raise ValueError(f"Unsupported reader: {config.reader}")


def median_raw(reader: SensorReader, samples: int, interval_sec: float = 0.02) -> float:
    values: list[float] = []
    for index in range(max(1, samples)):
        values.append(reader.read_raw())
        if index < samples - 1 and interval_sec > 0:
            time.sleep(interval_sec)
    return float(statistics.median(values))


def warmup(reader: SensorReader, samples: int) -> None:
    for _ in range(max(0, samples)):
        reader.read_raw()
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

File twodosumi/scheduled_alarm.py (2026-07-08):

from __future__ import annotations

from dataclasses import dataclass
from datetime import date, datetime, timedelta

from .alarm import REALARM_EVENT, SCHEDULED_ALARM_EVENT
from .config import AppConfig, ScheduledAlarmConfig


DISMISSED_EVENT = "alarm_dismissed"


@dataclass
class ScheduledAlarmAction:
    event: str
    message: str
    alarm_ids: list[str]


@dataclass
class PendingRecheck:
    alarm: ScheduledAlarmConfig
    alarm_date: date
    due_at: datetime
    off_bed_since: datetime | None = None
    realarm_count: int = 0


class ScheduledAlarmManager:
    def __init__(self, config: AppConfig) -> None:
        self.config = config
        self._completed: set[tuple[date, str]] = set()
        self._pending: dict[str, PendingRecheck] = {}

    def update(self, *, now: datetime, smoothed_weight_kg: float) -> list[ScheduledAlarmAction]:
        if not self.config.scheduled_alarm_enabled:
            return []

        self._forget_old_days(now.date())
        actions: list[ScheduledAlarmAction] = []
        in_bed = self._is_in_bed(smoothed_weight_kg)

        for alarm_id, pending in list(self._pending.items()):
            if self.config.wake_mission_enabled:
                if self._mission_completed(pending, now=now, in_bed=in_bed):
                    actions.append(
                        ScheduledAlarmAction(
                            event=DISMISSED_EVENT,
                            message=f"Wake mission completed: {self._alarm_name(pending.alarm)}",
                            alarm_ids=[alarm_id],
                        )
                    )
                    self._complete(pending.alarm_date, alarm_id)
                    del self._pending[alarm_id]
                    continue
                if in_bed and now >= pending.due_at:
                    pending.realarm_count += 1
                    pending.due_at = now + timedelta(minutes=self.config.bed_recheck_minutes)
                    actions.append(
                        ScheduledAlarmAction(
                            event=REALARM_EVENT,
                            message=f"Still in bed: {self._alarm_name(pending.alarm)} #{pending.realarm_count}",
                            alarm_ids=[alarm_id],
                        )
                    )
                continue

            if not in_bed:
                actions.append(
                    ScheduledAlarmAction(
                        event=DISMISSED_EVENT,
                        message=f"Alarm dismissed: {self._alarm_name(pending.alarm)}",
                        alarm_ids=[alarm_id],
                    )
                )
                self._complete(pending.alarm_date, alarm_id)
                del self._pending[alarm_id]
            elif now >= pending.due_at:
                actions.append(
                    ScheduledAlarmAction(
                        event=REALARM_EVENT,
                        message=f"Still in bed: {self._alarm_name(pending.alarm)}",
                        alarm_ids=[alarm_id],
                    )
                )
                self._complete(pending.alarm_date, alarm_id)
                del self._pending[alarm_id]
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
